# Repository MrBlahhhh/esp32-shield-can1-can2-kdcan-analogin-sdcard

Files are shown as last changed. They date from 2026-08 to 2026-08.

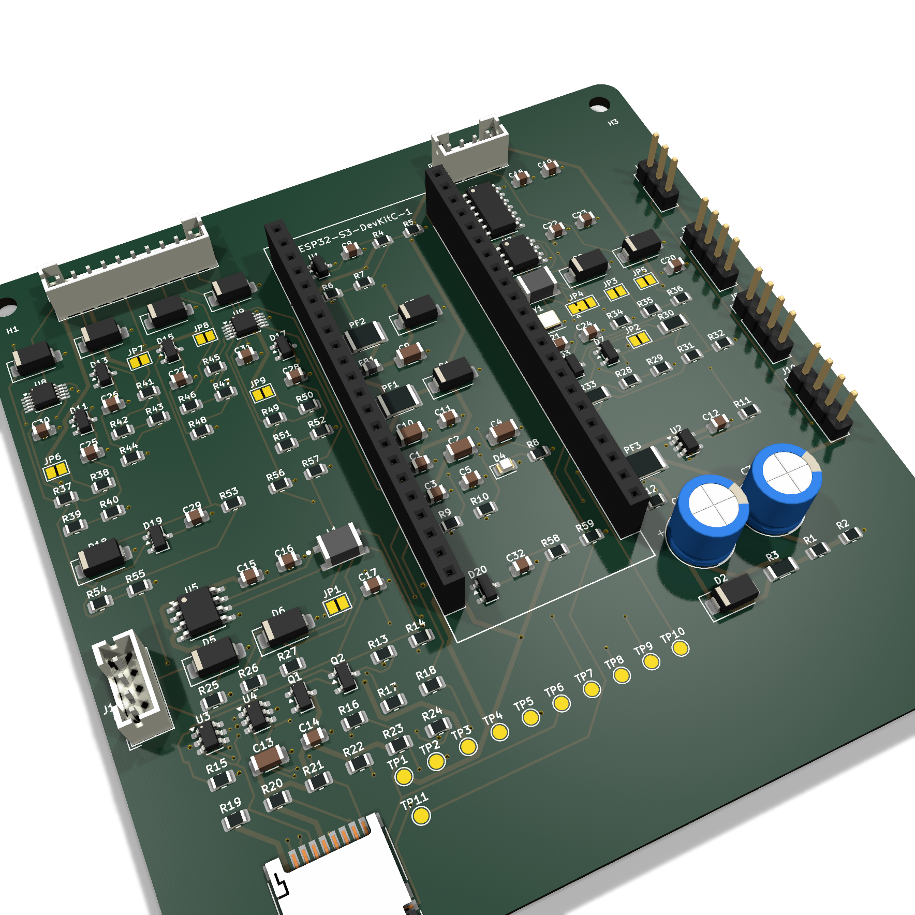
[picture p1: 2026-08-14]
plots/board-iso.png

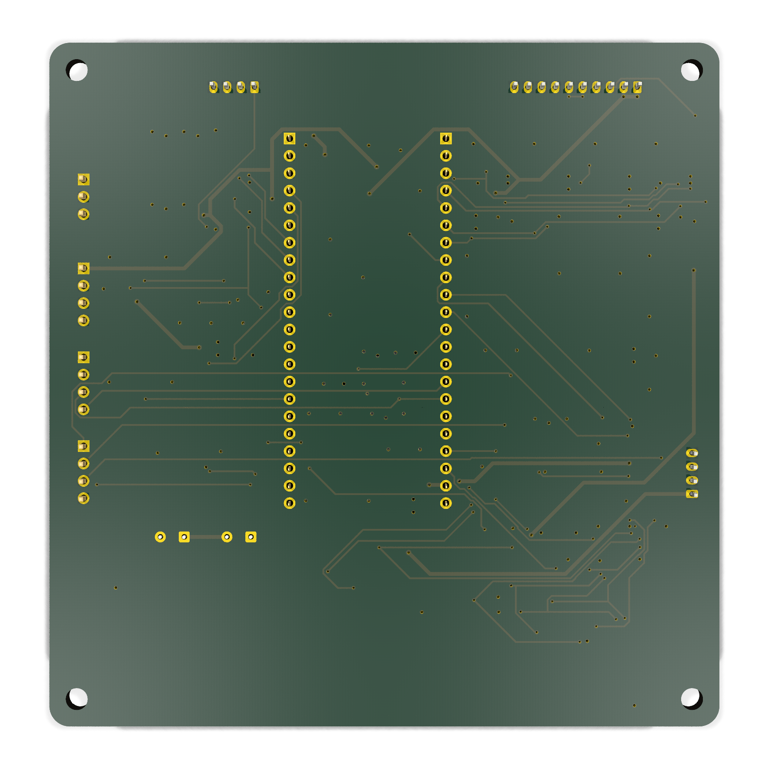
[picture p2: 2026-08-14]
plots/board-back.png

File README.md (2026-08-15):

# ESP32-S3 automotive I/O carrier — two CAN buses, K-line, microSD, analog

## TL;DR

A carrier board an **ESP32-S3-DevKitC-1 plugs into**, turning it into a
vehicle data logger. The dev board brings the MCU and its power; this board
brings everything that has to touch a car.

- **Two CAN buses at once.** One on the ESP32's own TWAI controller, one on
  an MCP2518FD over SPI — because the S3 has exactly one TWAI and two
  transceivers on it would only ever give you a choice, not both.
- **K-line (ISO 9141 / KWP2000) as well**, so a BMW/MINI K+DCAN cable is
  covered end to end. A solder jumper picks whether the aux harness pins
  carry K-line or the second CAN pair; the two cannot share a wire.
- **Four analog channels, read differentially.** The sensor loom's own
  ground comes back as a Kelvin wire through an attenuator matched to the
  signal channels', so chassis offset subtracts out exactly instead of
  landing on every reading.
- **The card survives ignition-off.** A supercapacitor bank holds the 5 V
  rail for about 825 ms after the supply goes away — six times what the board
  this forked from shipped with, and long enough to finish the block in
  flight and close the file.
- **The Python in `gen/` is the source.** It generates, places, routes,
  audits and circuit-simulates the whole board; the KiCad files are build
  outputs. `python gen/build_board.py` rebuilds the PCB from nothing.
- **The firmware runs before the board exists.** `gen/simulate_firmware.py`
  compiles the real sketch for the PC against a model of this board and
  feeds it CAN frames, sensor voltages and a power cut.
- **State: routed clean, simulated, firmware ported, never manufactured.**

## Why a carrier and not a shield

It was going to be a shield. It measured out at 1.4× the dev board's entire
area before a single track was drawn, so it isn't one — the DevKitC-1 drops
into two 22-way sockets on a board considerably larger than itself.

Worth being plain: at **98 × 100 mm** this is no smaller than the standalone
board it forked from. What it buys is a replaceable MCU with no module to
reflow, and a second CAN bus and a K-line the parent never had.

| | |
|---|---|
| Board | 98 × 100 mm, 4 layer |
| Parts | 153 component instances, 70 distinct BOM lines |
| Nets | 90 |
| Assembly | 128 surface-mount designators across 48 fab BOM lines |

## What's on it

| Block | Detail |
|---|---|
| **CAN 1** | TJA1051T/3 on the ESP32's TWAI. Common-mode choke, split termination (off by default), bidirectional clamps. |
| **CAN 2** | MCP2518FD (SOIC-14) on SPI with a 40 MHz crystal, its own TJA1051, choke, termination and clamps. |
| **K-line** | Discrete: 2N7002 low-side driver, clamped 22k/10k receiver, optional ISO 9141 tester pull-up on a jumper. |
| **Analog** | 4 channels, fixed 0–16 V divider (0.1 % where it sets the gain, 0.235 % worst case, no calibration needed), pull-up jumper per channel, two ADS1115s, shared Kelvin ground return. |
| **microSD** | 1-bit SDMMC, switched card supply, ESD arrays on every contact. |
| **Hold-up** | 2 × 0.33 F 2.7 V supercaps in series on the 5 V rail, TLV431 power-fail detector tripping at 4.20 V. |
| **Shift light** | 74AHCT1G125 buffer so WS2812 DIN is a real 5 V, fused tap, 3-pin header. |

There is **no power conversion**. Both rails come up from the dev board's
sockets — 5 V from its USB-C behind its own Schottky, 3.3 V from its LDO.
The only 12 V the board sees is OBD-II pin 16, and that is sense-only.

## Pin map

All 24 usable DevKitC-1 GPIOs are allocated; nothing is spare. Pins are
grouped by which socket row they are on, because each row is 22 through-holes
that cut a 53 mm slot through every inner layer — a signal crossing one has
no return path underneath it.

| J1 row (left of the board) | | J3 row (right) | |
|---|---|---|---|
| IO4–IO7 | AIN1–4 | IO1, IO2 | K-line RX / TX |
| IO8 | battery sense | IO39–IO42 | CAN 2 SPI (SCK/MOSI/MISO/CS) |
| IO9, IO10 | I²C SCL / SDA | IO21 | CAN 2 interrupt |
| IO11 | SD card detect | IO47 | SD supply enable |
| IO12–IO14 | SD D0 / CMD / CLK | IO48 | WS2812 data |
| IO15 | power fail | | |
| IO16–IO18 | CAN 1 S / TX / RX | | |

Exactly one net crosses sides — `SD_PWR_EN`, a load-switch gate — and it
routes around the end of the row rather than through it.

The analog channels must live in IO1–IO10 because ADC2 is unusable with the
radio up. After the SD bus takes IO9–IO14 and IO3 is excluded as a strapping
pin, IO4–IO8 are exactly the five that remain.

## Ordering

```
python gen/export_fab.py      # gerbers, positions, JLC BOM
python gen/export_order.py    # LCSC shopping list + what to buy elsewhere
```

Every one of the 48 fab BOM lines carries an LCSC part number, and each was
checked against the live catalogue rather than assumed — see
[`docs/PARTS.md`](docs/PARTS.md) for what that turned up, including three
part numbers that were confidently wrong and two footprints that would not
have soldered. [`docs/COST.md`](docs/COST.md) prices the result and identifies
about $5.70 a board of savings that cost nothing functional.

`fab/order-elsewhere.csv` lists what LCSC's assembly flow cannot supply:
the through-hole connectors, the two supercapacitors and the dev board.

**The order is ready and paused.** Everything is verified — gerbers, BOM,
placements, both JLCPCB quotes and an LCSC cart — and it is on hold because
US customs adds 35% of merchandise value. See
[`docs/TODO.md`](docs/TODO.md) for the state of play and the resume
checklist, and [`docs/COST.md`](docs/COST.md) for the quotes and the
hand-build-versus-assembled comparison.

## Verification

| | |
|---|---|
| `gen/validate.py` | schematic re-extracted through KiCad and compared net for net; ERC clean |
| `gen/build_board.py` | places, routes, and runs DRC — **0 violations, 0 unconnected** |
| `gen/simulate_firmware.py` | **50 checks**, the real sketch compiled for the host against a model of this board |
| `gen/mutate_firmware.py` | deliberately breaks the firmware 17 ways to prove the suite notices — **17 of 17 caught** |
| `gen/simulate.py` | ngspice: analog channel, crank, CAN bus, system budgets, log fidelity |
| `gen/audit_*.py` | docs, polarity, straps, paste, mechanical, PCB, routes, schematic readability |

Study 0 of the firmware suite is the one everything else rests on: it dumps
the simulator's pin map and compares it to `netlist.txt`, so a model built
from prose instead of the design fails loudly rather than validating the
wrong board.

## Wanted, not yet built

[`docs/TODO.md`](docs/TODO.md) — additions nobody has started, as opposed to
the defects below, plus the state of the paused parts order. Currently two
sensor additions, and **neither needs a board change**:

- **Exhaust gas temperature** through an MCP9600 on the I2C header. Entirely
  firmware.
- **Wideband AFR** from a DIY-EFI TinyWB. Its 0–5 V output drops straight
  into a sensor channel with nothing to change at all — that is the input
  the analogue front end was designed around. The open question is its
  10–20 AFR scaling, which clips anything richer than 10.0.

## Known open

- ~~**`ROW_PITCH` is an assumption.**~~ **Settled — 22.86 mm is correct**, from
  Espressif's own DXF. The pad columns sit at x = 1.270 and x = 24.130, 22
  pads each over y 7.960–61.300 (53.34 mm = 21 × 2.54), so the spacing is
  24.130 − 1.270 = **22.860 mm exactly**. It closes against the board width
  too: 1.270 + 22.860 + 1.270 = 25.400.

  Worth knowing that a figure of "25.4 mm row spacing on a 27.9 mm board"
  circulates for this part. That is the **original ESP32-DevKitC** with the
  WROOM-32 module, which really is wider. On the S3, 25.40 mm is the board
  width — the tell is that a 25.5 mm body with 25.4 mm rows would put the pin
  centres 0.05 mm from the edge.
- **No antenna keepout.** The module is on the dev board now, radiating from
  about 8.5 mm above this laminate. Copper underneath still detunes it, but
  which end of the outline to clear needs measuring off the same DXF.
- **The hold-up timings are calculated, not measured.** 825 ms shed /
  254 ms unshed come from `t = C·dV/I`; the ngspice study for the supercap
  bank has not been written, and ESR and the Schottky's drop over
  temperature will both eat into them.
- **Check the dev board revision.** v1.1 puts the onboard RGB LED on IO38,
  which this board leaves free for it. Some revisions use IO48, which is the
  WS2812 output here and would clash.
- **The schematic still has about 20 text collisions** out of the ~150 it
  started with, mostly a label brushing a neighbour inside a hand-drawn
  block. `gen/audit_schematic.py` lists each one with coordinates.
- **Two bypass capacitors sit 8.7 mm from the pin they bypass**, against the
  6 mm `gen/audit_pcb.py` asks for. That is the width of the SOIC-8 itself:
  the shelf packer keeps each bypass immediately beside its IC, but fills
  left to right, so the capacitor lands on the opposite side of the package
  from the supply pin. Down from 42 mm, and fine for 500 kbit/s CAN with
  22 µF of bulk on the same rail, but it is the one placement the audit
  still objects to.

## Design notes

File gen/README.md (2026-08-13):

# The generator pipeline

Everything in this project is generated: the Python in this directory is the
source of truth and every `.kicad_sch` / `.kicad_pcb` / `fab/` / `plots/`
file is a build artifact. Nothing is ever hand-edited in KiCad — if it were,
the next regeneration would silently discard it. This file documents how the
pipeline works and, more importantly, the rules that were learned the hard
way, so the next boards can reuse all of it. The intended flow for a new design is at the bottom of this file.

## The one-command loops

```
# schematic loop (any Python 3)
python gen/generate_schematic.py && python gen/tidy_sch_text.py \n  && python gen/validate.py && python gen/audit_schematic.py

# board loop (needs KiCad 9 installed, freerouting.jar in the repo root)
python -u gen/build_board.py --passes 60

# the checks DRC cannot make (after a build)
"C:\Program Files\KiCad\9.0\bin\python.exe" gen/audit_pcb.py
python gen/simulate.py            # needs ngspice, numpy, matplotlib

# outputs
python gen/export_plots.py        # schematic.pdf + three board renders
"...\bin\python.exe" gen/export_fab.py   # JLCPCB gerbers/BOM/CPL
```

## What each file owns

| file | owns |
|---|---|
| `generate_schematic.py` | the part and net tables (the design itself), sheet packing, symbol/wire/label emission, netclasses, title blocks |
| `sch_blocks.py` | hand-drawn schematic layouts for every recurring circuit — coordinates only, no electrical content |
| `generate_pcb.py` | board outline, placement zones, fixed placements (`FIXED`, `BUCK_FIXED`, `PIN_FIXED`), planes, keepouts |
| `build_board.py` | the 10-stage build driver, with a lock so two builds cannot fight |
| `route_bucks.py` | hand-shaped copper for switching loops. **Not run on this board** — the converters went with the power section, `BUCK_FIXED` is empty, and `build_board.py` skips the stage. Kept for the next design that has one |
| `finish_routing.py` | ties for duplicated connector pins (runs before AND after autorouting) |
| `stitch_planes.py` | a via from every GND/+3V3 pad to its plane, with hole-collision checks |
| `maze_route.py` | rip-up-and-retry router for whatever freerouting leaves open |
| `tidy_silk.py` | reference designator declutter; touches no copper |
| `tidy_sch_text.py` | the same job on the schematic: nudges colliding references and values, slides labels along their own wire, pulls a stub out where a label needs room. Touches no connectivity |
| `audit_schematic.py` | measures what tidy_sch_text.py then fixes — text collisions (including pin numbers) and symbols joined by name rather than by wire |
| `validate.py` | compares KiCad's own netlist node-for-node against `netlist.txt`, runs ERC |
| `audit_pcb.py` | current capacity, antenna keepout, decoupling distance, thermal, drill overlaps |
| `simulate.py` | twelve ngspice/numpy/scipy studies of the circuits themselves |
| `audit_routes.py` | post-route extraction: IR drop over the real copper, bus lengths/skew, SW-node area |
| `audit_straps.py` | every ESP32 strapping pin's state at reset vs what the netlist hangs on it |
| `overstress.py` | closed-form worst-case for every external input |
| `export_plots.py` | schematic.pdf + board renders (top, back, iso) into `plots/` |
| `export_fab.py` | JLCPCB gerber zip, BOM csv, CPL csv into `fab/` (KiCad python) |

## Design rules the pipeline enforces mechanically

- Parts are identified by **(sheet, value, exact pad-net signature)**
  everywhere — placement tables, schematic blocks, buck routing. References
  renumber on every run and must never be used as keys.
- Values are **display-short** ("600R", "0.2A PTC", "AO3401A"); ratings live
  in the hidden Voltage/Tolerance/Note/MPN fields. `split_value()` separates
  voltage and tolerance automatically. Because values are matching keys, a
  value rename must be applied to `generate_schematic.py`, `sch_blocks.py`,
  `generate_pcb.py` and `audit_pcb.py` in the same commit.
- Every recurring or nontrivial circuit gets a **hand-drawn block** in
  `sch_blocks.py`. The column packer is only for true one-liners (bypass
  caps, single pull-resistors that belong to no connector) — anything that
  reads as "parts floating in space" should be blocked or attached.

## How to draw a schematic block (the hard-won rules)

A block is a dict: `sheet`, `anchor` (value, netset), `parts`
[(value, netset, dx, dy, rot)], `wires` [polylines], `junctions`, `rails`
[(net, x, y, facing)], `labels` {net: (x, y, angle)}. All coordinates are
mm relative to the anchor, on the **1.27 mm grid** — 12.07 is not a grid
point, 12.70 is; off-grid ends throw ERC "off connection grid" warnings.

**Rotation → pin positions** (sheet coordinates, y grows downward):

- Two-pin R/C/L/fuse (pins 1/2 at lib (0, ±3.81)):
  rot 0 → pin 1 top, pin 2 bottom; rot 180 → flipped;
  rot 90 → pin 1 left; rot 270 → pin 1 right.
- GSD FETs / BEC BJTs (G/B lib (−5.08, 0), D/C (2.54, 5.08), S/E (2.54, −5.08)):
  rot 0 → gate left, drain top, source bottom;
  rot 90 → gate bottom, drain left-top, source right-top;
  rot 270 → gate top, source left-bottom, drain right-bottom.
  The mapping is: rot 270 ≡ (lx,ly)→(ly,lx), rot 90 ≡ (lx,ly)→(−ly,−lx).
- TL431DBZ: A left, K right, REF top (rot 0).

**Connectivity rules** (each of these broke a build before it was learned):

- A wire must **end** at every junction on it. To tap a wire mid-span,
  split it into two wires that both end at the tap point and add a junction
  there. Three or more wire-ends (or wire-ends plus a pin) at one point
  need a junction; exactly two objects sharing an endpoint connect without
  one, and adding a junction to a bare two-object meeting point *breaks*
  the netlist.
- Crossing wires without a junction are legal and do not connect — use
  crossings freely, the way any dense schematic does.
- A wire routed through a third part's **pin point** connects to it. Route
  around pins you do not mean to touch.
- Labels attach anywhere along a wire or at a pin end. One label position
  per net per block. The emitter picks local vs global form automatically
  from whether the net leaves the sheet.
- Pins on power nets (GND, +3V3, +5V, +VBAT, +5VS, VBUS) may simply be
  left unwired: the emitter hangs the right power symbol on them. Only
  signal nets need wires or labels.
- **The anchor keeps its natural rotation** — only member parts get the
  block's `rot`. If the drawing needs a part rotated, that part cannot be
  the anchor (this is why SENSW anchors on the 2N7002, not the P-FET).
- Value text is placed above/below the body; leave a grid step of air
  between parallel runs or the text lands on the neighbouring wire.

**Label and text readability** (learned by zooming into ugly sheets):

- Every private net still needs exactly **one label for its name** — delete
  them all and KiCad silently renames the net `Net-(R5-Pad2)`, which breaks
  name-based netlist comparison and the schematic/board net linkage. But
  the label does not have to sit on the circuit: put it on a **short
  vertical spur** (one wire, one junction) rising into open sheet, angle 90.
- Labels at wire ends must extend **away** from the circuit: angle 180 on a
  left-pointing stub, 0 on a right-pointing one. A label anchored at a left
  stub-end with angle 0 prints its text right across the part it feeds.
- Part pitch on a shared run: **>= 10-12 mm** between centres, more when a
  value is long. Budget a full symbol's width between one part's text and
  the next part's body.
- Every pin that gets an auto GND/power symbol needs **~10 mm of empty
  sheet** beyond it for the symbol body plus its text.
- To actually judge a sheet, render it: `kicad-cli sch export svg`, then a
  headless browser screenshot (`msedge --headless --screenshot=... file:///
  ...svg`), and zoom in. Text collisions are invisible at full-page scale
  and glaring at reading scale — review at the scale a reader uses.

**Never put a control character in any emitted string.** A literal newline
inside a symbol property is accepted by KiCad's loader and then silently
breaks connectivity for every symbol after it in the file — the netlist
drops them with no error pointing anywhere near the cause. The emitter now
flattens all whitespace in properties; keep it that way.

## Writing simulation decks (ngspice gotchas, each cost an hour)

- `tran` picks its own tmax and will step right over ns-scale pulses.
  Always pass it explicitly: `tran <step> <stop> 0 <step>`.
- An "ideal diode" as a tanh-blended behavioral source leaks backward.
  Use a hard clamp: `B1 a b I=max(V(a)-V(b),0)/R_on`.
- An RC delay hung directly on a behavioral comparator output loads it and
  shifts the threshold. Buffer first: `Bbuf buf 0 V=V(comp)`, RC off `buf`.
- LTRA transmission lines go unstable next to coupled inductors; the ideal
  `T` element (`T1 p1 n1 p2 n2 Z0=120 TD=21n`) is solid. Calibrate drivers
  to the datasheet's loaded test condition, not open-circuit levels.
- `wrdata` on an AC vector writes complex pairs. Convert first:
  `let m = mag(v(out))` and write `m`.
- Keep component values in the decks in step with the schematic tables —
  the duplication is deliberate; a disagreement is a bug report.

## Fab outputs, plots, and the ordering package

- JLCPCB BOM header is exactly `Comment,Designator,Footprint,JLCPCB Part #`.
  Basic parts auto-match from the footprint+value; extended parts need a
  real LCSC C-number in the part's `lcsc=` field — **never guess one**.
  Parts without a number get listed in the project README for hand-matching
  in the order UI. Check BOM designator count == CPL count after export.
- `kicad-cli pcb render` needs its rotate argument quoted *inside* the
  string: `["--rotate", "'-30,0,25'"]` — without the inner quotes the
  leading `-` is eaten as a flag.
- STEP model for enclosure work: `kicad-cli pcb export step --subst-models`.
- **NTFS timestamp tunneling:** a regenerated file keeps its old
  CreationTime — even through delete-then-recreate within ~15 s — and
  Explorer's default "Date" column shows CreationTime, so fresh plots look
  stale to the user. After regenerating, stamp them:
  `Get-ChildItem plots | % { $_.CreationTime = $_.LastWriteTime }`.

## Build discipline (how a night of rebuilds went wrong)

- **One build at a time, ever.** The `.build_board.lock` exists for this;
  never put `rm -f .build_board.lock` inside a launch command "to be safe" —
  that is how two autorouters ended up writing the same board file.
- Stopping a build's shell does **not** stop freerouting: the java process
  survives and keeps routing a board that no longer exists. Kill java
  explicitly (`taskkill /F /IM java.exe`) after aborting a build.
- Always launch the driver with `python -u`. Block-buffered stdout means an
  empty log for ten minutes, which is indistinguishable from a hang and has
  caused healthy builds to be killed.
- A placement zone must have **more rect area than the sum of its parts'
  courtyards** (SOT-23 ~12 mm2, 0805 ~7 mm2, plus ~30 % packing loss). The
  shelf packer does not fail when a zone is too small -- it silently spills
  parts onto whatever is below. Watch the post-placement DRC line (the
  early tie stage prints it) instead of waiting ten minutes for routing.
- freerouting runs at below-normal priority (set in build_board.py) so a
  build does not take the machine down with it.

## Verification ladder

Every change climbs the same ladder, and each rung catches a class of
mistake the rung below cannot:

1. `generate_schematic.py` — dies loudly on unmatched block parts.
2. `validate.py` — ERC plus node-for-node netlist comparison.
3. `build_board.py` — DRC to 0 violations / 0 unconnected.
4. `audit_pcb.py` — the physics DRC does not know about.
5. `simulate.py` — does the circuit *work*, across tolerance and abuse.

## Starting a new board from this pipeline

The next boards are dedicated PCBs for **existing, running ESP32 projects**,
so the requirements are not invented — they are extracted:

0. Read the running project's firmware first. The pin map (`#define`s /
   board config), the peripheral drivers it initialises (which buses, which
   sensors, which voltages), and the modules on the current dev-board build
   ARE the part tables. List every external connection the firmware
   touches, then add the infrastructure the dev board was silently
   providing: power input + protection, USB, decoupling, boot straps,
   and (for anything in a vehicle) the ride-through/PWR_FAIL contract so
   firmware can keep its existing shutdown behaviour.

1. Copy `gen/` wholesale; delete the project-specific tables in
   `generate_schematic.py` (sheets/parts) and `generate_pcb.py` (zones,
   FIXED/BUCK_FIXED/PIN_FIXED, HOLES, board size) and `sch_blocks.py`.
2. Write the part tables first; run the schematic loop until validate
   passes with everything column-packed and ugly.
3. Draw blocks for each circuit cluster; re-run the loop after each one.
4. Define zones roughly, build the board, then iterate placement from the
   courtyard-overlap warnings and the renders.
5. Keep `simulate.py`'s decks in step with the schematic tables — the
   component values are duplicated there on purpose, so a disagreement is
   a bug report.
6. Before ordering: full ladder green, `export_fab.py`, BOM==CPL count,
   `docs/BRINGUP.md`-style staged checklist written from the studies'
   expected values, and JLC's free DFM at upload as the last gate.

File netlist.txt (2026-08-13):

Net connectivity for ESP32-S3 CAN + microSD Automotive Logger rev B
(88 nets)

+3V3           #FLG3.1 C10.1 C11.1 C16.1 C18.1 C19.1 C23.1 C30.1 C31.1 C4.1 C5.1 D11.2 D13.2 D15.2 D17.2 D19.2 D20.2 D4.2 D7.2 J3.1 J3.2 J5.2 J7.2 Q1.2 R10.1 R13.1 R24.1 R6.1 R9.1 TP2.1 U3.5 U4.5 U5.5 U6.14 U7.5 U8.8 U9.1 U9.8
+5V            #FLG2.1 C12.1 C15.1 C2.1 C22.1 C3.1 D2.1 J3.21 J7.1 PF2.1 PF3.1 R3.1 R4.1 TP1.1 U2.5 U5.3 U7.3
+5VS           #FLG4.1 C9.1 D3.1 FB1.2 J9.1 J9.2 JP6.1 JP7.1 JP8.1 JP9.1 TP3.1
AGND_A         R53.2 R54.1
AGND_SENSE     #FLG7.1 C29.1 D19.3 J10.3 R54.2 R55.1 U8.7 U9.7
AIN1           C25.1 D11.3 J3.4 R39.2 R40.1 U8.4
AIN1_A         R37.2 R38.2 R39.1
AIN1_IN        D10.1 J9.3 R37.1
AIN1_PU        JP6.2 R38.1
AIN2           C26.1 D13.3 J3.5 R43.2 R44.1 U8.5
AIN2_A         R41.2 R42.2 R43.1
AIN2_IN        D12.1 J9.4 R41.1
AIN2_PU        JP7.2 R42.1
AIN3           C27.1 D15.3 J3.6 R47.2 R48.1 U8.6
AIN3_A         R45.2 R46.2 R47.1
AIN3_IN        D14.1 J9.7 R45.1
AIN3_PU        JP8.2 R46.1
AIN4           C28.1 D17.3 J3.7 R51.2 R52.1 U9.4
AIN4_A         R49.2 R50.2 R51.1
AIN4_IN        D16.1 J9.8 R49.1
AIN4_PU        JP9.2 R50.1
AIN_SP1        J10.1 R56.1 U9.5
AIN_SP2        J10.2 R57.1 U9.6
AUX_A          D8.1 J2.1 JP4.2 TP11.1
AUX_B          D9.1 J2.2 JP5.1
CAN2H_T        L2.1 U7.7
CAN2L_T        L2.3 U7.6
CAN2_CS        J4.6 U6.13
CAN2_H_C       JP3.1 JP4.3 L2.2
CAN2_INT       J4.18 U6.4
CAN2_L_C       JP5.2 L2.4 R36.2
CAN2_MISO      J4.7 U6.12
CAN2_MOSI      J4.8 U6.11
CAN2_RXD       U6.2 U7.4
CAN2_S         R34.1 U7.8
CAN2_SCK       J4.9 U6.10
CAN2_SPLIT     C24.1 R35.2 R36.1
CAN2_TXD       U6.1 U7.1
CANH_T         L1.1 U5.7
CANL_T         L1.3 U5.6
CAN_H          D5.1 J1.3 JP1.1 L1.2 TP8.1
CAN_L          D6.1 J1.4 L1.4 R27.2 TP9.1
CAN_RX         J3.11 U5.4
CAN_S          J3.9 R25.1 U5.8
CAN_SPLIT      C17.1 R26.2 R27.1
CAN_TX         J3.10 U5.1
GND            #FLG1.1 C1.2 C10.2 C11.2 C12.2 C13.2 C14.2 C15.2 C16.2 C17.2 C18.2 C19.2 C2.2 C20.2 C21.2 C22.2 C23.2 C24.2 C25.2 C26.2 C27.2 C28.2 C29.2 C3.2 C30.2 C31.2 C32.2 C4.2 C5.2 C7.2 C8.2 C9.2 D1.2 D10.2 D11.1 D12.2 D13.1 D14.2 D15.1 D16.2 D17.1 D18.2 D19.1 D20.1 D3.2 D5.2 D6.2 D7.1 D8.2 D9.2 J1.2 J10.4 J2.3 J2.4 J3.22 J4.1 J4.21 J4.22 J5.1 J6.3 J7.3 J7.4 J8.10 J8.6 J9.10 J9.9 Q2.2 Q3.2 R15.2 R2.2 R25.2 R29.2 R32.2 R34.2 R40.2 R44.2 R48.2 R5.2 R52.2 R55.2 R56.2 R57.2 R59.2 R8.2 TP5.1 U1.3 U2.1 U2.3 U3.2 U4.2 U5.2 U6.7 U7.2 U8.1 U8.3 U9.3 Y1.2 Y1.4
I2C_SCL        J3.15 J5.4 R10.2 U8.10 U9.10
I2C_SDA        J3.16 J5.3 R9.2 U8.9 U9.9
K_LINE         JP4.1 R30.2 R31.1 R33.2 TP10.1
K_PU           JP2.2 R33.1
K_RX           D7.3 J4.4 R31.2 R32.1
K_TX           J4.5 R28.1
K_TX_D         Q3.3 R30.1
K_TX_G         Q3.1 R28.2 R29.1
LED_5V         J6.1 PF3.2
LED_DIN        R12.1 U2.4
LED_DIN_A      R11.2 U2.2
LED_DIN_J      J6.2 R12.2
LED_DIN_MCU    J4.16 R11.1
OBD_VBAT       #FLG5.1 J1.1 PF1.1 R58.1 TP4.1
OBD_VBAT_F     C1.1 D1.1 JP2.1 PF1.2
PFD_SENSE      C8.1 R4.2 R5.1 R7.2 U1.2
PWR_FAIL       J3.8 R6.2 R7.1 U1.1
PWR_LED_K      D4.1 R8.1
SCAP_MID       C6.2 C7.1 R1.2 R2.1
SCAP_TOP       C6.1 D2.2 R1.1 R3.2
SD_CD          J3.17 J8.9 R24.2 U4.4
SD_CLK         J3.20 R16.1
SD_CLK_C       J8.5 R16.2 TP6.1 U3.1
SD_CMD         J3.19 R17.1
SD_CMD_C       J8.3 R17.2 R19.2 TP7.1 U3.3
SD_D0          J3.18 R18.1
SD_D0_C        J8.7 R18.2 R20.2 U3.4
SD_D1_C        J8.8 R21.2 U3.6
SD_D2_C        J8.1 R22.2 U4.1
SD_D3_C        J8.2 R23.2 U4.3
SD_EN_G        Q2.1 R14.2 R15.1
SD_PG          Q1.1 Q2.3 R13.2
SD_PWR_EN      J4.17 R14.1
SD_VDD         #FLG6.1 C13.1 C14.1 J8.4 Q1.3 R19.1 R20.1 R21.1 R22.1 R23.1
SENS_RTN       D18.1 J9.5 J9.6 R53.1
TERM2_A        JP3.2 R35.1
TERM_A         JP1.2 R26.1
VBAT_SNS       C32.1 D20.3 J3.12 R58.2 R59.1
VSENS_F        FB1.1 PF2.2
XTAL1          C20.1 U6.6 Y1.1
XTAL2          C21.1 U6.5 Y1.3

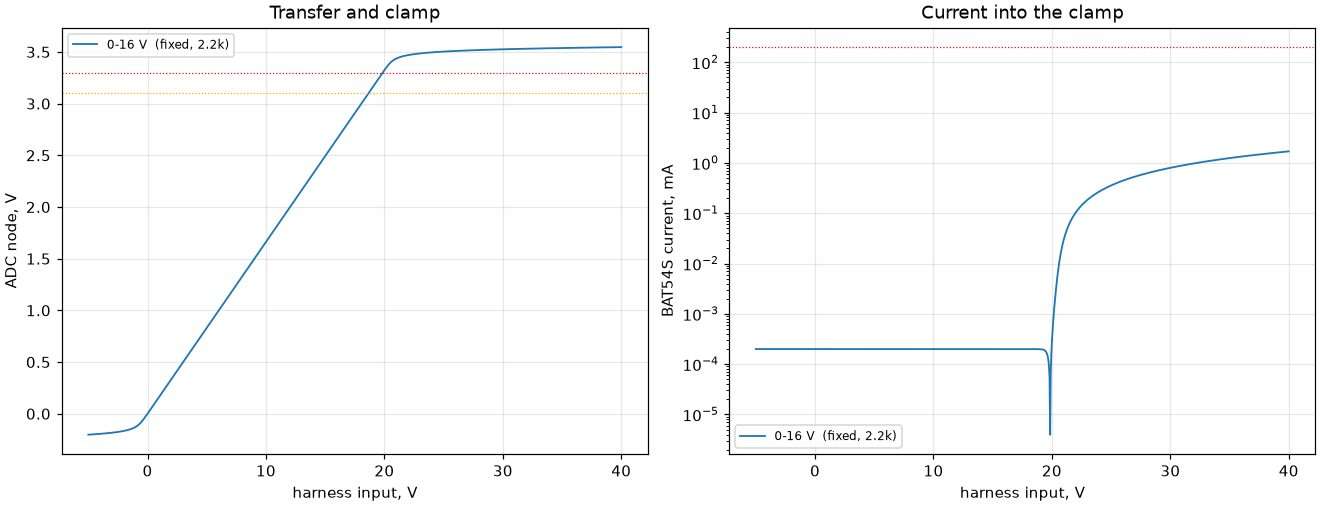
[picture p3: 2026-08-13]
sim/analog.png

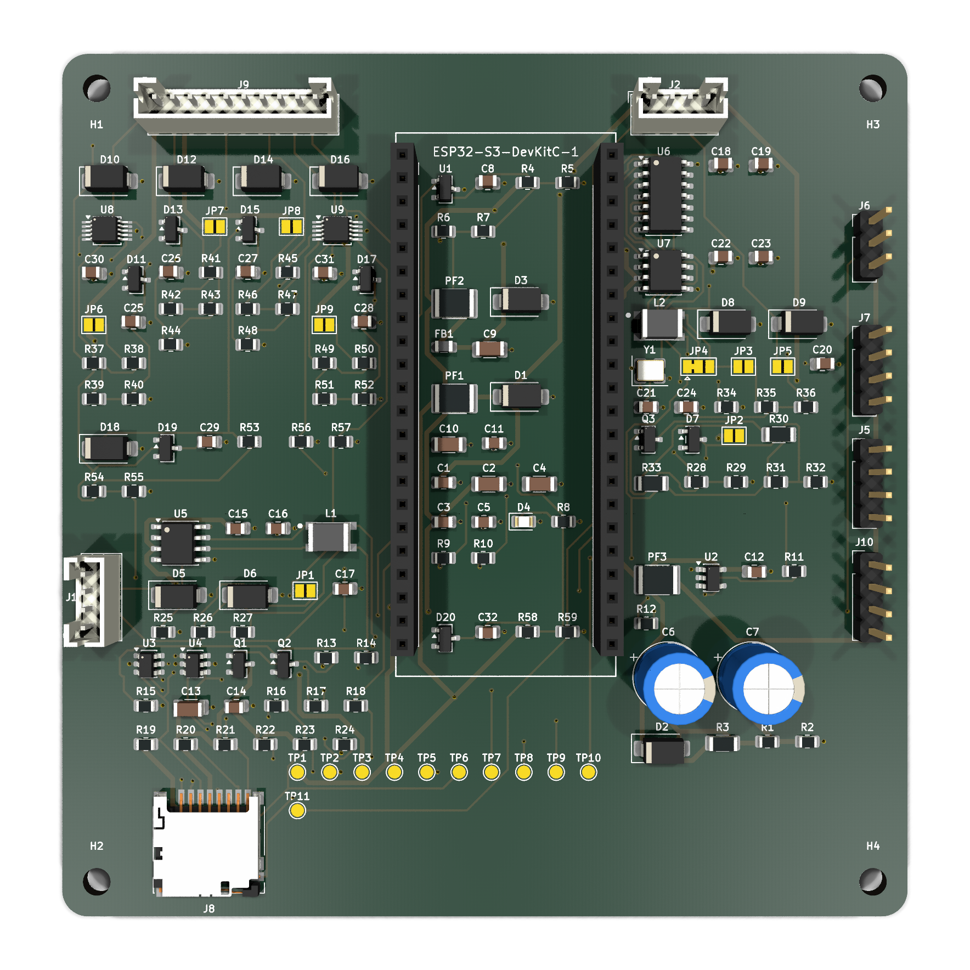
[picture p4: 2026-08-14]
plots/board-routed.png

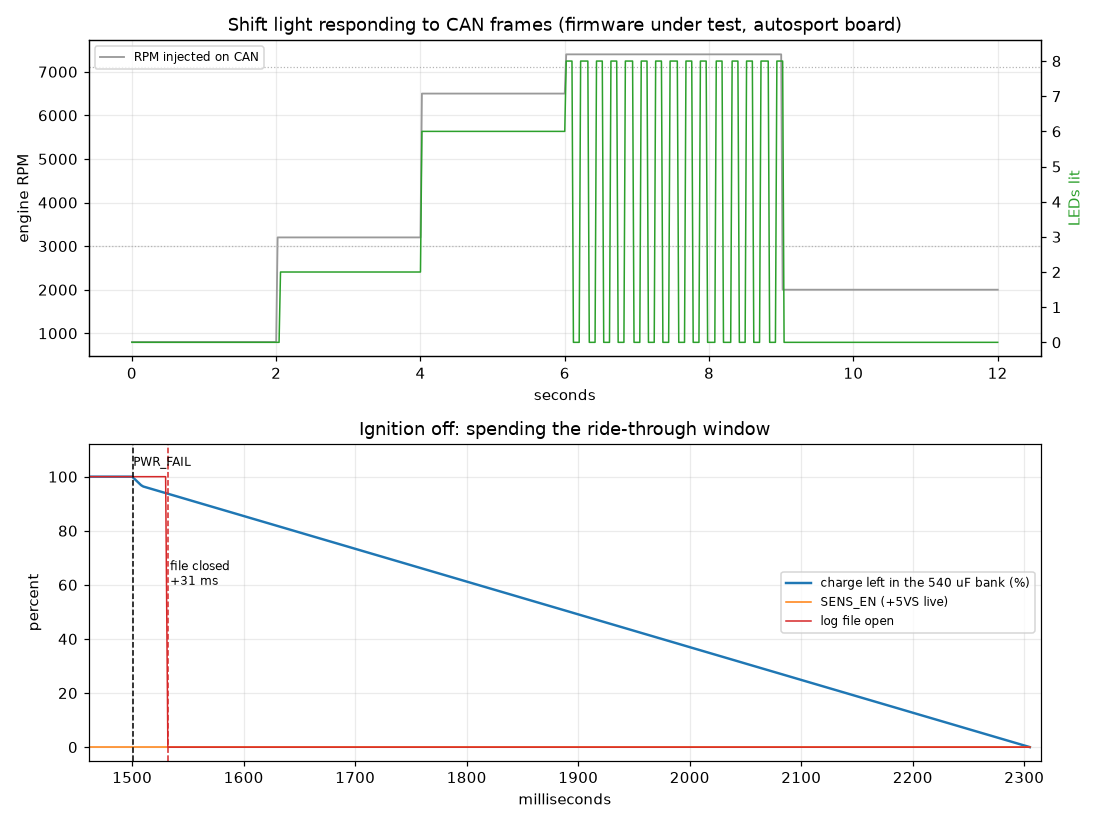
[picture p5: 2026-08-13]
sim/firmware.png

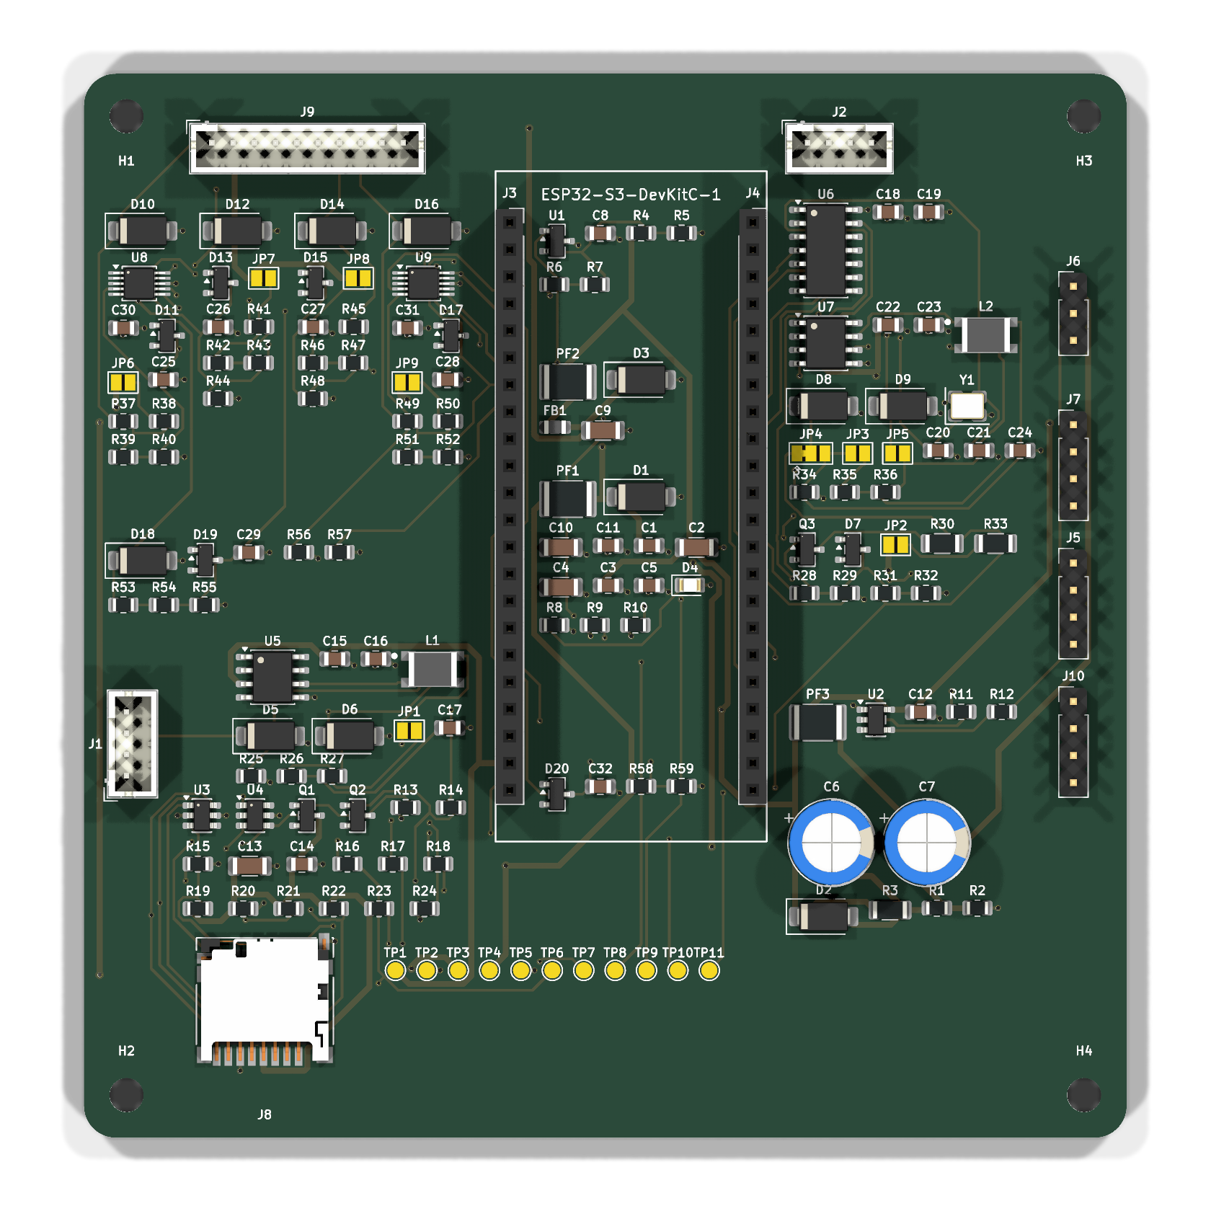
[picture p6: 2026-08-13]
sim/carrier-top.png

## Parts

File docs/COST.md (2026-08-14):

## What to upload, per vendor

The generated files differ by who is building it, and the difference that
bites is the part number. **JLCPCB matches on LCSC codes; everyone else
matches on manufacturer part numbers.** Uploading `fab/bom.csv` to PCBWay or
MacroFab returns every line unmatched, because `C37593` means nothing
outside LCSC.

| | JLCPCB | PCBWay / MacroFab / Eurocircuits |
|---|---|---|
| Board | `fab/*-gerbers.zip` | same |
| BOM | `fab/bom.csv` (LCSC codes) | `fab/assembly-bom-*.xlsx` (**MPNs**) |
| Placement | `fab/positions.csv` | `fab/centroid-*.csv` |

`gen/export_assembly_bom.py` writes the MPN version. Columns are Designator,
Quantity, Value, Package, Manufacturer, MPN, Type, Populate — the union of
what those three ask for, including the SMD/PTH marking PCBWay wants.

PCBWay's one hard rule is that **the pick-and-place designators must match
the BOM exactly, with through-hole excluded**. Both hold here and are
checked rather than assumed: 128 designators on the logger and 51 on the
gate, identical in both files, with no through-hole in either — those live
in `fab/order-elsewhere.csv` because no SMT line fits them.

### Two centroid files, and why

`fab/positions.csv` is KiCad's own export and is what JLCPCB wants: X to the
right, **Y negated**, because KiCad's Y axis points down and the export flips
the sign rather than moving the origin. Every Y in it is negative -- the
logger runs -91.5 to -13.0 on a board occupying 0..100. JLCPCB's tooling
knows that convention.

Not every assembler does, and an unstated origin with negative Y is
ambiguous in exactly the way that gets a board built mirrored. So
`gen/export_centroid.py` writes `fab/centroid-{logger,gate}.csv` with the
origin at the **bottom-left corner of the board outline**, X right, Y up,
both positive. That can be checked by eye: nothing negative, nothing larger
than the board.

It also filters to the BOM rather than to the board. Taking every footprint
gave 140 rows against the logger's 128 BOM designators, because the board
also carries connectors, sockets and supercapacitors. PCBWay asks
specifically for "all the designators/references same as the ones in BOM,
with THT designators excluded", and a centroid that disagrees with the BOM is
the one thing they warn about. The script fails if the two ever diverge.

Through-hole is hand-fitted whoever builds the boards: relays, terminal
blocks, the optocoupler and the JST headers.
if a quote is easy to get.

### Europe — the most plausible alternative

- **Aisler** (Netherlands) — small-batch, hobbyist-friendly, EU-made, online
  quoting. Closest thing to an OSH Park in Europe.
- **Eurocircuits** (Belgium/Germany) — prototype and small series, and they
  do assembly. Well regarded, properly engineered, online quoting.
- **Beta Layout / PCB-Pool**, **Multi-CB** (Germany) — similar.

EU prices are higher than mainland China, but the comparison is against
JLC+35% rather than JLC, and EU→US duty is a different and generally lower
rate. Eurocircuits is the one to quote for assembly, Aisler for bare boards.

### United States — priced, not competitive

MacroFab quoted **$1200 and that excluded pick and place**, against JLCPCB's
$475.71 all in. Duty would have to reach **265%** before JLCPCB assembled
cost what MacroFab quoted; it is 35%.

Bare board only: OSH Park prices 4-layer by area at roughly $10/in², and the
logger is about 15 in², so three boards would exceed $100 against $13 for
ten. Advanced Circuits, Sunstone, Bay Area Circuits and Royal Circuits are
all real, all 5–20× for prototype quantities. Screaming Circuits, PCB:NG and
Tempo do assembly at MacroFab-like levels.

US board fab is not close, and the tariff does not make it close.
oor stays open.

Worth knowing that all 19 Yageo part numbers that script *constructs* from
Yageo's own scheme came back **Exact** matches at Octopart, which validates
the scheme end to end.
eference the ADS1115's own gain error is 0.15 % typical and 0.30 %
maximum, so the middle row puts the divider just under the converter — the
point past which spending more stops buying anything. It saves $1.47 against
all-0.1 % and needs no calibration.

#### The original argument, for the record

The biggest surprise in the whole BOM: **fifteen resistors cost $2.68**, more
than the CAN controller. Yageo's RT/AT 0.1 % series is 0.30 and 0.19 dollars a
piece against $0.0027 for a stocked 1 % part — a hundredfold difference.

They are not buying what they look like they are buying:

- **The ADS1115's own gain error is ±0.15 % typical, ±0.30 % maximum.** A
  0.1 % divider contributes about 0.14 %. The converter is already the
  dominant error term, so tightening the resistors below it changes the total
  by almost nothing.
- **Absolute accuracy has to be calibrated anyway.** One constant per channel
  against a known voltage removes the divider error whatever its tolerance —
  and the schematic has said "exact scale is a firmware calibration constant"
  since the parent board.
- **The thing that cannot be calibrated away is the differential match**, and
  1 % is fine there. The ground correction's residue is the *mismatch* between
  the signal chain and the return chain: at 1 % that is about 2 % of the
  offset, so a 300 mV chassis offset leaves **6 mV** instead of 0.6 mV. Both
  are negligible against the 300 mV being removed.

Honest version of the trade: uncalibrated, 0.1 % gives ~0.33 % total error and
1 % gives ~1.4 %. Calibrated, they are indistinguishable. **If you will
calibrate once per channel, this is free money.** If you will not, keep the
0.1 % parts on the four signal channels and the shared return — that is ten
resistors, not fifteen, and saves $0.27 instead of $2.63.

### 2. Shrink the supercapacitor bank — saves roughly $2

1 F per cell buys 2500 ms of hold-up. Nothing needs that:

| cells | bank | shed | everything on |
|---|---|---:|---:|
| 0.10 F | 0.05 F | 250 ms | 77 ms |
| **0.33 F** | 0.165 F | **825 ms** | 254 ms |
| 0.47 F | 0.235 F | 1175 ms | 362 ms |
| 1.00 F (now) | 0.5 F | 2500 ms | 769 ms |

The parent board rode out **127 ms** and that was judged adequate. A healthy
card flushes in 18 ms; the worst stall the studies model is 500 ms, and
`shutdown()` clears the strip within 9 ms so the shed column is the one that
applies. **0.33 F is 6× the parent's proven margin** and still clears the
worst modelled stall with 65 % to spare.

Correction to `docs/PARTS.md` while I am here: I wrote that cylindrical cells
are "tens of milliohms". The Eaton HV0810 class is **200 mΩ**. Two in series
is 400 mΩ, which drops 48 mV at 120 mA — fine, and still inside the "under
about 1 Ω" requirement, but the note overstated the case.

### 3. Replace the Hirose microSD socket — NOT DONE, see below

$1.12 against $0.04–0.06 for a generic push-push TF socket. That is 9 % of the
SMD BOM in one connector.

The catch is real: **the cheap sockets have no card-detect switch.** That
costs the `SD_CD` signal, and firmware finds out there is no card by failing
to mount — which for a logger that checks at boot is not much of a loss. It
also *frees a GPIO*, and this board currently has none spare.

It needs a footprint change and push-push instead of push-pull (spring eject
rather than friction). Arguably better in a car.

### 4. Consider one ADS1115 instead of two — saves $1.32

The second one exists solely to give channel 4 a differential pair: one chip's
MUX offers three channels against a shared negative, not four.

With one chip you keep three fully differential channels and read the fourth
single-ended on the ESP32's own ADC — still four inputs, but the fourth
without ground correction and at ±1–2 %. Worth it only if three precision
channels is genuinely enough.

## Not recommended

**MCP2518FD → MCP2515 (saves $1.82).** Tempting: $0.94 against $2.76, and the
car runs classic CAN at 500 kbit/s so CAN FD is unused. But the MCP2515 has
**two receive buffers** where the MCP2518FD has 2 KB of message RAM and 32.
On a busy bus with SPI latency in the way, two buffers overrun and you lose
frames — and this is a logger, where a dropped frame is the failure mode that
matters. Keep the 2518.

**TJA1051 → SN65HVD230 (saves ~$0.30).** The HVD230 is 3.3 V only. This board
wants 5 V bus drive with a 3.3 V logic pin, which is exactly what the
TJA1051T/3 does. Not the same part.

**2-layer PCB.** The two socket rows already slot the planes; taking the
planes away entirely on a board carrying CAN, a 20 MHz SPI bus and four analog
channels is a false economy.

## Summary

| Change | saves | status |
|---|---:|---|
| 0.1 % only where it matters | **$1.47** | **done** |
| 1 F → 0.33 F supercaps | ~$1.80 estimated | **done** |
| Generic microSD socket | — | **dropped**, see below |
| **Achieved** | **$3.27** | **$18.29 → $15.02, an 18 % cut** |
| One ADS1115 | $1.32 | available, costs channel 4's ground correction |

The resistor saving is measured against the regenerated BOM. The supercapacitor saving is an estimate, because those
are bought outside the LCSC catalogue and the price depends on the cell.

## What happened to the socket

The $1.06 saving was real arithmetic against the wrong part. Those $0.04
sockets are SHOU HAN and XUNPU house parts whose only drawing is a scanned
PDF with no extractable dimensions, so **the land pattern cannot be verified**
— and this project's whole standard is that every part is checked before it is
trusted. Shipping an unverified footprint on five boards to save a dollar is
not a trade worth making.

The verifiable alternatives are much less attractive than the search results
suggested:

| Part | LCSC | qty 10 | KiCad footprint | card detect |
|---|---|---:|---|---|
| Hirose DM3D-SF (fitted) | `C719027` | $1.12 | yes | yes |
| Molex 47219-2001 | `C164170` | $0.63 | yes | no, hinged lid |
| Hirose DM3AT-SF-PEJM5 | `C114218` | $0.96 | yes | yes, push-push |

So the honest saving is **$0.49**, not $1.06, and it costs the card-detect
signal and swaps a push-pull for a hinged lid. That is 2.7 % of the board to
lose a feature. Not worth it — the Hirose stays.

Worth noting for a larger run: at volume the $0.04 parts become worth the
effort of drawing and verifying a footprint from the manufacturer's drawing.
At five boards it is not.

## A note on the PCB

98 × 100 mm sits **2 mm inside** the 100 × 100 tier boundary that most fabs
price against. Any growth past that steps into a materially more expensive
bracket, so treat 100 mm as a hard limit on both axes rather than a target to
grow into.

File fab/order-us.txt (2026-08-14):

US distributor order -- 10 x logger, 5 x gate
================================================================

Upload order-us.csv to Digi-Key's BOM manager. Quantities are
the exact build plus 2 spares -- there are no minimums here,
and some lines are lifted to the next price break only because
that costs less than buying under it.

  part number                   qty  what
  CC0805JRNPO9BN150              22  15pF 50V               
  CC0805KRX7R9BB222              12  2.2nF 50V              
  LTV-814                         7  AC-input optocoupler,  
  SMAJ5.0A                       17  SMAJ5.0A               
  SMAJ36A                         7  SMAJ36A                
  TLV431ASN1T1G                  12  TLV431ASN1T1G          
  CL31A226KAHNNNE                32  22uF 16V               
  B4B-PH-K-S(LF)(SN)             22  JST PH 4-pin vertical  
  SMAJ26CA-13-F                  52  SMAJ26CA-13-F          
  CL31A106KBHNNNE                37  10uF 16V               
  SRV05-4.TCT                    22  SRV05-4.TCT            
  CL21B474KBFNNNE                52  470nF 50V              
  RC0805FR-07100KL              107  100k                   constructed, was 0805W8F1003T5E
  B10B-PH-K-S(LF)(SN)            12  JST PH 10-pin vertical 
  MF-MSMF050-2                   17  MF-MSMF050-2           
  RC0805FR-07100RL               12  100                    constructed, was 0805W8F1000T5E
  RC0805FR-0710KL               107  10k                    constructed, was 0805W8F1002T5E
  RC0805FR-07121KL               10  121k                   constructed, was 0805W8F1213T5E
  CC0805KRX7R9BB472              22  4.7nF 50V              constructed, was 0805B472K500NT
  RC0805FR-0718KL                12  18k 1%                 constructed, was 0805W8F1802T5E
  RC0805FR-071KL                100  1k                     constructed, was 0805W8F1001T5E
  RC0805FR-071ML                 12  1M                     constructed, was 0805W8F1004T5E
  RC0805FR-072K2L                17  2.2k                   constructed, was 0805W8F2201T5E
  RC0805FR-07220RL               17  220                    constructed, was 0805W8F2200T5E
  RC0805FR-0722KL                12  22k                    constructed, was 0805W8F2202T5E
  RC0805FR-0733RL                42  33                     constructed, was 0805W8F330JT5E
  RC0805FR-074K7L                22  4.7k                   constructed, was 0805W8F4701T5E
  RC0805FR-0743KL                12  43k 1%                 constructed, was 0805W8F4302T5E
  RC0805FR-0747KL                12  47k                    constructed, was 0805W8F4702T5E
  RC0805FR-078K2L                12  8.2k                   constructed, was 0805W8F8201T5E
  RC1206FR-07100RL               12  100                    constructed, was 1206W4F1000T5E
  RC1206FR-074K7L                10  4.7k                   constructed, was 1206W4F4701T5E
  RC1206FR-0720RL                12  20                     constructed, was 1206W4F200JT5E
  RC1206FR-07750RL               12  750                    constructed, was 1206W4F7500T5E
  AO3400A                        12  AO3400A                
  SMAJ40CA                       52  SMAJ40CA               
  SMAJ6.0A                       12  SMAJ6.0A               
  SS14                           17  SS14                   
  CL21B104KCFNNNE                22  100nF 100V             
  CL21B105KBFNNNE                12  1uF 16V                
  RC0805FR-0731K6L               12  31.6k                  constructed, was FRC0805F3162TS
  RC0805FR-072K49L               42  2.49k                  constructed, was FRC0805F2491TS
  C3216X6S2A106KT0A0E             7  10uF 100V              
  ADS1115IDGSR                   22  ADS1115IDGSR           
  BAT54S                         72  BAT54S                 
  CL21B102KBCNNNC                12  1nF 50V                
  LM5164DDAR                      7  LM5164DDAR             
  CC0805KRX7R9BB104             157  100nF 16V              
  RT0805BRD0710KL               100  10k 0.1%               constructed, was FRH0805B1002TS
  TJA1051T/3,118                 22  TJA1051T/3,118         
  MCP2518FDT-H/SL                12  MCP2518FDT-H/SL        
  DM3D-SF                        12  DM3D-SF                
  MF-MSMF020/60-2                22  MF-MSMF020/60-2        
  RC0805FR-0760R4L               42  60.4                   constructed, was 0805W8F604JT5E
  DMG2301L                       12  DMG2301L               
  SN74AHCT1G125DBVR              12  SN74AHCT1G125DBVR      
  ACT45B-510-2P-TL003            22  ACT45B-510-2P-TL003    
  MPZ2012S601ATD25               12  742792022              
  1N4148W                        12  1N4148W                
  2N7002                         22  2N7002                 
  RT0805BRD072K21L               52  2.21k 0.1%             
  SS34                            7  SS34                   

  62 lines, 1716 pieces

24 of those are CONSTRUCTED Yageo equivalents
----------------------------------------------------------------
The original is a Chinese brand no US distributor carries.
Same value, tolerance and package, so the substitution is
free -- but the numbers are built from Yageo's scheme, not
read off a catalogue page. The scheme was checked against
the live site for 100R and 31K6. Spot-check a few.

CHOOSE THESE YOURSELF -- footprint-critical
----------------------------------------------------------------
Substituting the maker substitutes the pinout, and the
board is already laid out. Match the spec exactly:

  green                  x17    (was KT-0805G)
        green LED, 0805, ~525 nm

  SPDT power relay, 5 V  x12    (was SRD-05VDC-SL-C)
        SPDT power relay, 5 V coil, THT, 19.2 x 15.6 mm body, SANYOU/Songle pinout (coil 2+5, COM 1, NO 3, NC 4)

  5.00 mm screw terminal x22    (was KF301-5.0-2P)
        2-pole screw terminal, 5.00 mm pitch, THT

  5.00 mm screw terminal x12    (was KF301-5.0-3P)
        3-pole screw terminal, 5.00 mm pitch, THT

  TX322540M4FBCE2T       x12    (was TX322540M4FBCE2T)
        40 MHz crystal, 3225 4-pad, 12 pF load, -40/+85 C or wider

  XL-2012UYC             x12    (was NCD0805Y1)
        yellow LED, 0805, ~595 nm

NOT CLASSIFIED -- look these up by hand
----------------------------------------------------------------
  C168133    FNR8040S330MT            cjiang             x7    FNR8040S330MT

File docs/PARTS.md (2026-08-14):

# Part numbers, and how they were checked

Every LCSC number on this board was opened and read before it was trusted:
manufacturer part number, package, and the one or two parameters that decide
whether the part is the right one. This page records what that turned up,
because the interesting entries are the ones that were wrong.

The habit exists because this project has been bitten before. On the parent
board `C8544` was written down for an MMBT3906 and is in fact an **S9018
NPN** — the wrong polarity, in the same package, which would have left a USB
over-voltage cutoff permanently inoperative. `C7975` for an SN74AHCT1G125 is
an **LMV324 quad op-amp**. Neither is catchable by ERC, DRC, a netlist
compare or a simulation. They are only catchable by looking.

## Wrong on the first pass

| Wanted | First guess | What it actually is | Corrected to |
|---|---|---|---|
| MCP2518FD, SOIC-14 | `C2148396` | 18.7 kΩ 0805 resistor, **out of stock** | `C626759` |
| 40 MHz crystal, 3225 | `C255909` | **16 MHz** crystal | `C5186937` |
| JST PH 10-pin header | `C157966` | JST **XH 9-pin**, 2.5 mm pitch | `C158038` |

Three of the five part numbers introduced in one sitting were wrong, and all
three were plausible: right category, right-looking number, and the BOM would
have exported clean.

## Footprints that would not have soldered

Both polyfuses were specified on a **1206** land and both parts are **1812**.
Bourns' MSMF series is 4.5 × 3.2 mm; a 1206 land is 3.2 × 1.6 mm. This came
across from the parent board, where it had survived every audit — nothing in
the toolchain compares a part's package against the footprint it was assigned,
because nothing in the toolchain knows the part's package. Reading the
catalogue entry is what knows.

- `C17313` MF-MSMF050-2 — 0.5 A hold, 1812
- `C719178` MF-MSMF020/60-2 — 0.2 A hold, 60 V, 1812

## The generic-passive table is keyed on package now

`GENERIC_LCSC` in `gen/generate_schematic.py` maps a jellybean value to a
part number. It used to be keyed on value alone, which is fine until the same
value appears in two packages — and this board has 33 Ω on both an 0805 and a
1206 land, the second for the K-line driver's fault current. Keyed on value
only, the 1206 position ordered the 0805 part: right resistance, wrong
footprint, every board.

It is keyed on `(value, package)` now, and `generic_lcsc()` returns nothing
rather than guessing when a combination is missing. An unmatched line has no
part number, `export_order.py` refuses to write it, and somebody has to go
and look — which is the correct failure.

## Values chosen to match stock, not the other way round

Several values moved so that a real, stocked part exists:

| Was | Now | Why |
|---|---|---|
| 28.7k / 12.0k divider | **43k / 18k** | Same trip point to 2 mV (4.202 V vs 4.204 V); both are stocked 1 % parts and 28.7k is not |
| 33 Ω K-line series | **20 Ω** | 33 Ω does not exist in 1206 in the basic library. 20 Ω keeps the dominant level inside 0.2 × Vb with either pull-up configuration; 100 Ω would not |
| 510 Ω tester pull-up | **750 Ω** | Also absent in 1206, and 750 is the better number anyway: 190 mW while dominant against 510 Ω's 280 mW, which a 250 mW part could not carry |
| 22 Ω charge resistor | **100 Ω** | Charging 0.5 F dissipates 5.5 J whatever the resistance; 22 Ω puts 1.0 W into a 250 mW part for the first several seconds. 100 Ω peaks at 0.22 W |
| 100 nF anti-alias | **470 nF** | 100 nF against the 1.84 kΩ source gives an 865 Hz corner, above the ADS1115's 430 Hz Nyquist. Caught by `gen/simulate.py` once 0–16 V became the only range |

## Where LCSC's own data is wrong

`C719027` (Hirose DM3D-SF, the microSD socket) is listed as **"Card
Detection: No"**. It has one. DigiKey describes the same part as
"10 (8 + 2) position" with a normally-open card-detect switch, and the KiCad
footprint carries the two extra pads. The schematic wires pin 9 as
`SD_CD` and that is correct — do not "fix" it.

## The rest

Opened and confirmed, with stock at the time of checking:

| Part | LCSC | Confirmed as |
|---|---|---|
| TJA1051T/3 | `C58988` | NXP CAN transceiver, SOIC-8 |
| MCP2518FD | `C626759` | Microchip CAN FD controller, SOIC-14 |
| ADS1115IDGSR | `C37593` | TI 16-bit I²C ADC, VSSOP-10 |
| SN74AHCT1G125 | `C7484` | TI single bus buffer, SOT-23-5 |
| TLV431A | `C127592` | onsemi shunt reference, SOT-23 |
| SRV05-4 | `C13612` | Semtech 4-channel TVS array, SOT-23-6 |
| ACT45B-510 | `C76584` | TDK CAN choke, 51 µH, AEC-Q200 |
| 2N7002 | `C8545` | N-channel, 60 V — the standoff the K-line needs |
| DMG2301L | `C7472914` | P-channel, 20 V, 3 A |
| BAT54S | `C408389` | dual **series** Schottky, SOT-23 |
| SS14 | `C2480` | 40 V Schottky, SMA |
| SMAJ26CA | `C134976` | 26 V **bidirectional** TVS |
| SMAJ40CA | `C223989` | 40 V bidirectional TVS, 400 W |
| SMAJ6.0A | `C223993` | 6 V **unidirectional** TVS |
| KT-0805G | `C2297` | green LED, 0805 |
| B4B / B8B / B10B-PH | `C131334` / `C157974` / `C158038` | JST PH, 2.0 mm |
| DM3D-SF | `C719027` | Hirose microSD, push-pull |
| TX322540M4FBCE2T | `C5186937` | 40 MHz, 12 pF CL, −40/+85 °C, 30 Ω ESR |

The crystal's temperature range is the reason it is that part and not the
first 40 MHz one found: `C5380316` is also 40 MHz in the same package and is
rated **−20 to +70 °C**, which a car in a summer car park exceeds.

## The generic table was not as checked as it claimed

The header of this page says every number was opened and read. That was true
of the parts chosen deliberately. It was **not** true of `GENERIC_LCSC`, the
lookup that hands out a part number for any plain resistor or capacitor by
value and package — that table carried a comment saying it had been verified
against the live catalogue, and it had not been. Nine of its entries were
wrong, and they were wrong in the way that survives every other check:

| Wanted | Was | What it actually is | Now |
|---|---|---|---|
| 2.2 nF 50 V 0805 | `C1547` | 12 pF, and **0402** | `C107146` |
| 121 kΩ 0805 | `C25089` | 20 Ω, and 0402 | `C17438` |
| 31.6 kΩ 0805 | `C25100` | 27 Ω, and 0402 | `C2930156` |
| 4.7 kΩ 1206 | `C17909` | 120 Ω | `C17936` |
| SMAJ5.0A, SMA | `C908214` | right part, **SOD-123 body** | `C113952` |
| SMAJ36A, SMA | `C908224` | right part, SOD-123 body | `C113967` |
| green LED 0805 | `C965798` | 0603 | `C2297` |
| yellow LED 0805 | `C965800` | 0603 | `C84261` |
| 600 Ω @ 100 MHz bead | `C216149` | **60 Ω** — a factor of ten | `C81034` |

Six of the nine are package errors, and a package error is the worst kind
here: the part number is valid, the part is in stock, the value is right, and
it arrives and does not fit the land pattern. Nothing in ERC, DRC, the
netlist compare or the stock check looks at the body size of what was
ordered against the footprint it was ordered for.

`gen/verify_cart.py` now does exactly that, and it is the reason all nine
were found at once. Two ways to run it:

```
python gen/verify_cart.py --live                # before there is a cart
python gen/verify_cart.py <cart-export.csv>     # after, on what LCSC has
```

`--live` looks every number in `fab/order-combined.csv` up in the catalogue
and compares package, value, tolerance and voltage against what the
schematic asked for. Use that one — a wrong number found there is a one-line
edit, and the same number found in a cart export has already been paid for.

Two of its own bugs are worth knowing, because both reported correct parts as
wrong: `1N4148W` parsed as the value "1" against a description leading with
"150 mA", and the Würth bead's MPN `742792022` parsed as 742 megohms. Values
that are really part numbers are now skipped rather than compared.

### When to substitute for a part that is not in the index

An earlier version of this page said `C28233` was a 16 V capacitor that
`check_stock.py` had wrongly dropped into a 100 V position. **That was wrong.**
`C28233` is a 100 V 100 nF X7R 0805 and the substitution was correct. The
index holds two records for it — one keyed by part number and one by MPN —
and the by-number record comes back with an empty description, so the
Samsung code `CL21B104K`**`C`**`FNNNE` was decoded by hand and read as 16 V.
The cart export settles it: `A` is 25 V and `B` is 50 V across four other
Samsung lines on this board, and `C` is 100 V.

The real question is narrower. Absence from the index means one of two
things, because the index is JLCPCB's **assembly** library:

- `C37593`, the ADS1115, is reported absent from it and was sitting in a real
  LCSC cart at the same moment. It is not absent at all: JLCPCB quoted this
  board at 48 items, every part type including that one. The index simply
  answers inconsistently for it — present on some queries, missing on others.
  So a miss here can just be the index being unreliable.
- `C29055` and `C1794` were absent and LCSC rejected both, one "not found"
  and one "not available".

Two out of three, so absence is a real signal, and refusing to act on it is
not the safe choice it looks like — a round of this project shipped a cart
with two unbuyable lines in it for exactly that reason.

What separates the cases is not the index, it is what the schematic asked
for. A jellybean is specified by **value** — "100 nF 100 V", "15 pF 50 V" —
and anything meeting that value will do, so swapping is free. A part
specified by **manufacturer part number** — "ADS1115IDGSR", "1N4148W" — was
chosen for reasons the tool cannot see, and the nearest match by description
is a different component. So it substitutes jellybeans and never an MPN.

Any substitute it does make must state a tolerance and a voltage at or above
the design's. Silence is not evidence of a 100 V part.

### Both dead parts are fixed at source, not at order time

`C29055` and `C1794` are gone from the generators. The 100 V decoupler is
`C28233` and the crystal load caps are `C107110`, an NP0 part, which matters
for a 40 MHz crystal in a way X7R would not have been.

The 100 nF was interesting for a second reason: the logger already said
`C28233` and only the gate project said `C29055`. The combined order picks
one number when the two projects disagree, and it picked by **quantity used**
— the gate uses ten and the logger five, so the one dead number in the pair
beat the live one. It now prefers whichever number has come back in a cart
export, and falls back to quantity only between two equally unknown ones.

## A 32.768 kHz crystal as the converter's bulk input capacitor

Caught on the last check before the order went in, with a correct-looking
cart open on screen. The gate board's generic table had `C387601` for
`10uF100V` in 1206. `C387601` is an **ECS-.327-7-34B-TR, a 32.768 kHz
crystal**, and it was sitting in the cart against C2 — the LM5164's bulk
input capacitor on the 24 V rail.

`verify_cart.py` had passed it twice, for two independent reasons, and both
were bugs in the checker rather than bad luck:

- **The package matched.** `SMD3215-2P` contains "3215", which was in the
  accept list for 1206. It should never have been: 1206 is **3216** metric,
  and 3215 is a crystal package. One digit.
- **The value check silently did nothing.** It read the *leading* token of
  the description. That description begins "Crystal", which is not a number,
  so there was nothing to compare — and finding nothing to compare was
  treated as agreement rather than as the loud signal it is.

The value check now anchors on the **unit** and searches the whole line, so
it does not care whether the description leads with the value, the power
rating, the voltage or a temperature range — all four spellings occur. If
the design asks for a capacitance and the line states no capacitance
anywhere, that is now a reported disagreement. Where a record carries no
description at all, the report says so by name instead of counting it as a
pass; "checked" and "nothing to check with" are different answers.

The replacement is `C35689855`, a TDK `C3216X6S2A106KT0A0E` — 10 µF 100 V
X6S, **1206**, so the land pattern is unchanged and no board respin is
needed. It is the only 10 µF 100 V part in 1206 in the catalogue; everything
else at that value and rating is 1210. The 100 V is not over-specification:
the input TVS is an SMAJ36A clamping at 58.1 V, which a 50 V part would not
survive.

The logger's table had the same key pointing at `C6872041`, which is not in
the catalogue at all. Nothing used it, so it never surfaced — a dead number
waiting for the first part that asked for that value. Both now point at
`C35689855`.

## Minimum order quantities: the cart export is the only source

MOQs cannot be derived. Across 78 real parts they take seven distinct values
— 1, 2, 5, 10, 20, 50, 100 — and two 0805 resistors from the same
manufacturer in the same series can differ. An early version of this project
guessed them from the package and got **45 of 70 wrong**.

There is also no API for them. LCSC's own is behind Akamai, EasyEDA's mirror
answers 403 from CloudFront, JLCPCB's cart endpoint 404s, and the parts index
that does answer carries stock and price but not MOQ.

The reaction to that was to stop rounding altogether and let LCSC bump each
line at checkout. That is worse than it sounds, and it is what produced the
complaint that the minimums were "way off": **42 of 69 lines in the paste
file disagreed with what ended up in the cart.** The file said 5 and the cart
said 100, silently, forty-two times. A file that does not say what you are
buying is not much of an order.

What does carry the real numbers, exactly and for free, is a cart export:

```
python gen/learn_moq.py <cart-export.csv> [more.csv ...]
```

That folds `LCSC#`, `MOQ` and `Multiple` into `fab/lcsc-moq.csv`, which only
grows. Rounding is on by default now and `moq_round` leaves any part not in
that table exactly alone, so there is no guessing left in it — the choice is
"round the lines we have real numbers for", which has no downside. All 69
lines of the current order now conform, and the paste file matches the cart
line for line.

The ledger is also the best available evidence that a part number is real —
better than the parts index, which both misses parts LCSC sells and lists
parts it no longer does. The combined order uses it to break ties.

**So the loop is: paste, export, `learn_moq.py`, and the next order is
quantised correctly.** Each round trip through the cart permanently improves
the data, which is the closest thing to an API that exists here.

### Board counts and spares

The two projects are built in different numbers, so they are counted
separately, and hand assembly loses parts:

```
python gen/export_combined_order.py --boards 10 --other-boards 5 --spares 2
```

Spares are added **before** rounding, which is what makes them nearly free.
On a 100-piece minimum two extra cost nothing at all; they only move the
lines whose minimum is 1 or 5 — the LM5164, the MCP2518FD, the SD socket,
the relays, the terminal blocks. Those are exactly the lines where losing one
part stops a build, and where there is no bag of spares in the drawer.

At 10 loggers + 5 gates with two spares each, 33 of 69 lines do not move at
all: their minimum already covered the extra.

## Before you order

1. Re-check stock. These were read on 2026-08-12 and stock moves.
   `python gen/check_stock.py`, then `python gen/verify_cart.py --live`.
   Both should report nothing: no short lines, no unlisted lines, and every
   line matching the value, package, tolerance and voltage asked for.
2. After the cart exists, `python gen/learn_moq.py <export.csv>` and
   `python gen/verify_cart.py <export.csv>` — the first keeps the minimums
   current, the second checks what LCSC actually put in the basket.
3. ~~Confirm the DevKitC-1 header row pitch.~~ Done — 22.86 mm exactly, read
   out of Espressif's DXF. See the README's "Known open" for the numbers.
4. The two supercapacitors are the only line where the exact part matters
   beyond its value: ESR must be under about 1 Ω. A 5.5 V coin-type EDLC is
   30–200 Ω and cannot source the 120 mA the hold-up has to carry.
   Cylindrical cells clear that easily — the Eaton HV0810 class is 200 mΩ,
   so two in series drop 48 mV at 120 mA. (An earlier draft of this page said
   "tens of milliohms"; that overstated it. 200 mΩ is the number, and it is
   still comfortably inside the requirement.)
5. They are also the most expensive item on the board, and 1 F is far more
   than anything needs. See [COST.md](COST.md) — 0.33 F is still six times
   the hold-up the parent board shipped with.

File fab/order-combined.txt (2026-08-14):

Combined parts order -- 10 x logger + 5 x gate, +2 spare of each
==========================================================

Paste fab/order-combined-paste.txt into LCSC's quick-order
box, or upload order-combined.csv to their BOM tool.

Quantities are the build plus the spares, rounded up to
each part's real minimum from fab/lcsc-moq.csv. Anything
not in that table is left alone and LCSC raises it at
checkout. --no-moq turns the rounding off.

Spares are added BEFORE rounding, so on a 100-piece
minimum they cost nothing. They only change the lines
whose minimum is 1 or 5 -- which are the ones where
losing a part actually stops the build.

  part       order  needed  logger    gate  comment
  C49678       160     157     120      35 * 100nF 16V
  C149504      200     107      80      25 * 100k
  C17414       200     107     100       5 * 10k
  C17513       100      92      70      20 * 1k
  C13585        40      37      30       5 * 10uF 16V
  C12891        40      32      20      10 * 22uF 16V
  C28233        50      22      10      10 * 100nF 100V
  C2480         50      17      10       5 * SS14
  C2297         50      17      10       5 * green
  C17313        20      17      10       5 * MF-MSMF050-2
  C408389      100      72      70       0   BAT54S
  C13967        60      52      50       0   470nF 50V
  C134976       55      52      50       0   SMAJ26CA-13-F
  C223989       55      52      50       0   SMAJ40CA
  C5159707     100      52      50       0   10k 0.1%
  C865368       60      52      50       0   2.21k 0.1%
  C17634       100      42      40       0   33
  C72998       100      42      40       0   60.4
  C2930178     100      42      40       0   2.49k
  C1744         50      22      20       0   4.7nF 50V
  C107110      100      22      20       0   15pF 50V
  C76584        22      22      20       0   ACT45B-510-2P-TL003
  C719178       25      22      20       0   MF-MSMF020/60-2
  C8545         50      22      20       0   2N7002
  C17673       100      22      20       0   4.7k
  C13612        25      22      20       0   SRV05-4.TCT
  C58988        22      22      20       0   TJA1051T/3,118
  C37593        22      22      20       0   ADS1115IDGSR
  C113952       20      17       0      15   SMAJ5.0A
  C17557       100      17       0      15   220
  C17520       100      17       0      15   2.2k
  C28323        20      12      10       0   1uF 16V
  C46653        20      12      10       0   1nF 50V
  C223993       15      12      10       0   SMAJ6.0A
  C81034        20      12      10       0   742792022
  C719027       12      12      10       0   DM3D-SF
  C7472914      20      12      10       0   DMG2301L
  C17408       100      12      10       0   100
  C17713       100      12      10       0   47k
  C17901       100      12      10       0   100
  C17955        50      12      10       0   20
  C17560       100      12      10       0   22k
  C17985       100      12      10       0   750
  C17695       100      12      10       0   43k 1%
  C17506       100      12      10       0   18k 1%
  C17828       100      12      10       0   8.2k
  C17514       100      12      10       0   1M
  C127592       15      12      10       0   TLV431ASN1T1G
  C7484         15      12      10       0   SN74AHCT1G125DBVR
  C626759       12      12      10       0   MCP2518FDT-H/SL
  C5186937      20      12      10       0   TX322540M4FBCE2T
  C107146      100      12       0      10   2.2nF 50V
  C81598        50      12       0      10   1N4148W
  C84261        20      12       0      10   XL-2012UYC
  C20917        15      12       0      10   AO3400A
  C2930156     100      12       0      10   31.6k
  C35689855      7       7       0       5   10uF 100V
  C113967       20       7       0       5   SMAJ36A
  C8678         20       7       0       5   SS34
  C168133       10       7       0       5   FNR8040S330MT
  C17438       100       7       0       5   121k
  C17936        50       7       0       5   4.7k
  C477928        7       7       0       5   LM5164DDAR

  63 distinct parts, 3894 pieces
  * = on both boards (10 parts)

  Ordering the two projects separately would take 4314 pieces.
  Combining saves 420 pieces of minimum-order padding.

Through-hole, also from LCSC -- same basket
----------------------------------------------------------
  C10790    x10   AC-input optocoupler, DIP-4, LTV-814           gate U2
  C131334   x30   JST PH 4-pin vertical header, 2.00 mm          logger J1; logger J2
  C158038   x15   JST PH 10-pin vertical header, 2.00 mm         logger J9
  C35449    x12   SPDT power relay, 5 V coil, SANYOU/Songle SRD- gate K1, K2
  C474881   x25   5.00 mm screw terminal, 2 pole (MaiXu MX126 /  gate J1, J7; gate J6
  C474882   x15   5.00 mm screw terminal, 3 pole, same family    gate J5, J8

Buy elsewhere -- no LCSC part number
----------------------------------------------------------

  [logger] C6, C7       x20
        1 F 2.7 V low-ESR EDLC, 8 mm can, radial P3.5mm
        Eaton HB1030-2R5105-R or equivalent. TWO THINGS TO CHECK. (1) ESR must be under about 1 ohm: a 5.5 V coin-type EDLC is 30-200 ohm and cannot source the 120 mA this has to carry, so the rail would collapse the instant it was asked to. Cylindrical cells are tens of milliohms. (2) Anything from 0.1 F up works -- 0.1 F still gives about 500 ms of hold-up against the 2.5 s the design point buys

  [logger] J3, J4       x20
        0.1" pin SOCKET, 1x22 vertical
        RECEPTACLES, not pin headers: a DevKitC-1 ships with male pins already soldered pointing down, and it drops into these. Buy 1x22 strips -- most 1x40 socket strips do not cut cleanly and you lose a position

  [logger] J5, J7, J10  x30
        0.1" pin header, 1x04 vertical
        any

  [logger] J6           x10
        0.1" pin header, 1x03 vertical
        any

  [logger] harness      x10
        JST PH crimp housings + crimps
        PHR-4 x2 and PHR-10 x1 per board, plus SPH-002T-P0.5S crimps. Buy with the headers or the loom cannot be made up

  [logger] dev board    x10
        ESP32-S3-DevKitC-1, N8R8 or N16R8
        The MCU. Check the revision: v1.1 puts the onboard RGB LED on IO38, which this board leaves free for it. Some revisions use IO48, which is the WS2812 output here and would clash

  [gate] J2, J3       x10
        0.1" pin SOCKET strip, 1x07 vertical
        RECEPTACLES, not pin headers. The XIAO gets male pins soldered to its castellations pointing down and drops into these. Buy 1x07 strips or cut from 1x40 -- most socket strips lose a position when cut, so allow for that.

  [gate] J4           x5
        0.1" pin header, 1x04 vertical
        Any. The spare GPIO.

  [gate] H1-H4        x20
        M3 screw, nut and standoff
        4 corner holes, 3.2 mm.

  [gate] module       x5
        Seeed XIAO ESP32-S3
        The MCU. Fit the U.FL antenna that comes in the box -- a gate is the wrong place to rely on a chip antenna. It also needs male header pins soldered to its castellations, pointing DOWN, to plug into J2/J3.

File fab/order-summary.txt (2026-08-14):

Parts order for 5 boards
========================================

1. From LCSC -- paste fab/order-lcsc-paste.txt into their
   quick-order box, or upload order-lcsc-simple.csv.
   Order quantities are already rounded up to LCSC's
   minimum order quantity and order multiple.

   part          order  needed  comment            designators
   C49678           80      60  100nF 16V          C11,C12,C14,C15,C16,C18,C22,C23,C30,C31,C32,C5
   C17414          100      50  10k                R19,R20,R21,R22,R23,R25,R28,R32,R34,R6
   C149504         100      40  100k               R1,R13,R15,R2,R29,R56,R57,R58
   C408389          50      35  BAT54S             D11,D13,D15,D17,D19,D20,D7
   C17513          100      35  1k                 R14,R37,R41,R45,R49,R53,R8
   C13967           60      25  470nF 50V          C25,C26,C27,C28,C29
   C134976          30      25  SMAJ26CA-13-F      D1,D5,D6,D8,D9
   C223989          30      25  SMAJ40CA           D10,D12,D14,D16,D18
   C5159707         50      25  10k 0.1%           R39,R43,R47,R51,R54
   C865368          60      25  2.21k 0.1%         R40,R44,R48,R52,R55
   C17634          100      20  33                 R11,R16,R17,R18
   C72998          100      20  60.4               R26,R27,R35,R36
   C2930178        100      20  2.49k              R38,R42,R46,R50
   C13585           40      15  10uF 16V           C10,C13,C9
   C1744            50      10  4.7nF 50V          C17,C24
   C12891           40      10  22uF 16V           C2,C4
   C107110         100      10  15pF 50V           C20,C21
   C76584           12      10  ACT45B-510-2P-TL00 L1,L2
   C719178          15      10  MF-MSMF020/60-2    PF1,PF2
   C8545            50      10  2N7002             Q2,Q3
   C17673          100      10  4.7k               R10,R9
   C13612           15      10  SRV05-4.TCT        U3,U4
   C58988           11      10  TJA1051T/3,118     U5,U7
   C37593           11      10  ADS1115IDGSR       U8,U9
   C28233           50       5  100nF 100V         C1
   C28323           30       5  1uF 16V            C19
   C46653           40       5  1nF 50V            C8
   C2480            50       5  SS14               D2
   C223993          10       5  SMAJ6.0A           D3
   C2297            50       5  green              D4
   C81034           30       5  742792022          FB1
   C719027           6       5  DM3D-SF            J8
   C17313           10       5  MF-MSMF050-2       PF3
   C7472914         10       5  DMG2301L           Q1
   C17408          100       5  100                R12
   C17713          100       5  47k                R24
   C17901          100       5  100                R3
   C17955           50       5  20                 R30
   C17560          100       5  22k                R31
   C17985          100       5  750                R33
   C17695          100       5  43k 1%             R4
   C17506          100       5  18k 1%             R5
   C17828          100       5  8.2k               R59
   C17514          100       5  1M                 R7
   C127592          10       5  TLV431ASN1T1G      U1
   C7484            10       5  SN74AHCT1G125DBVR  U2
   C626759           6       5  MCP2518FDT-H/SL    U6
   C5186937         10       5  TX322540M4FBCE2T   Y1

   48 distinct parts, 2676 pieces after MOQ rounding
   LCSC enforces the true per-part minimum at checkout, so
   anything undercalled here is bumped there, not rejected.

2. Not available from LCSC/JLC -- source separately

   C6, C7       x10  1 F 2.7 V low-ESR EDLC, 8 mm can, radial P3.5mm
                Eaton HB1030-2R5105-R or equivalent. TWO THINGS TO CHECK. (1) ESR must be under about 1 ohm: a 5.5 V coin-type EDLC is 30-200 ohm and cannot source the 120 mA this has to carry, so the rail would collapse the instant it was asked to. Cylindrical cells are tens of milliohms. (2) Anything from 0.1 F up works -- 0.1 F still gives about 500 ms of hold-up against the 2.5 s the design point buys

   J1           x5   JST PH 4-pin vertical header, 2.00 mm
                B4B-PH-K-S(LF)(SN), LCSC C131334. The CAN1 + power harness: OBD-II pins 16, 4, 6, 14

   J2           x5   JST PH 4-pin vertical header, 2.00 mm
                B4B-PH-K-S(LF)(SN), LCSC C131334, same part as J1. The aux bus: K-line or CAN 2, whichever AUXSEL is set to

   J9           x5   JST PH 10-pin vertical header, 2.00 mm
                B10B-PH-K-S(LF)(SN), LCSC C158038. Sensor harness

   J3, J4       x10  0.1" pin SOCKET, 1x22 vertical
                RECEPTACLES, not pin headers: a DevKitC-1 ships with male pins already soldered pointing down, and it drops into these. Buy 1x22 strips -- most 1x40 socket strips do not cut cleanly and you lose a position

   J5, J7, J10  x15  0.1" pin header, 1x04 vertical
                any

   J6           x5   0.1" pin header, 1x03 vertical
                any

   harness      x5   JST PH crimp housings + crimps
                PHR-4 x2 and PHR-10 x1 per board, plus SPH-002T-P0.5S crimps. Buy with the headers or the loom cannot be made up

   dev board    x5   ESP32-S3-DevKitC-1, N8R8 or N16R8
                The MCU. Check the revision: v1.1 puts the onboard RGB LED on IO38, which this board leaves free for it. Some revisions use IO48, which is the WS2812 output here and would clash

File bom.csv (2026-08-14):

Qty (1 board) | Qty (10 boards) | References | Value | Voltage | Tolerance | Footprint | Manufacturer part number | LCSC | Notes
1 | 10 | C1 | 100nF | 100V |  | Capacitor_SMD:C_0805_2012Metric |  | C28233
2 | 20 | C17 C24 | 4.7nF | 50V |  | Capacitor_SMD:C_0805_2012Metric |  | C1744 | Split-termination common-mode stabiliser
1 | 10 | C19 | 1uF | 16V |  | Capacitor_SMD:C_0805_2012Metric |  | C28323 | MCP2518FD bulk
2 | 20 | C2 C4 | 22uF | 16V |  | Capacitor_SMD:C_1206_3216Metric |  | C12891 | Bulk at the 5 V socket pin
2 | 20 | C20 C21 | 15pF | 50V |  | Capacitor_SMD:C_0805_2012Metric |  | C107110 | Crystal load cap, sized for Y1's 12 pF CL: C1=C2=2*(CL - Cstray) = 2*(12 - 5) = 14 pF, and 15 pF is the nearest E-series value. Re-check this if the crystal is substituted -- CL varies part to part, and an oscillator that starts on the bench but not at -20 C is the classic way to get it wrong
5 | 50 | C25 C26 C27 C28 C29 | 470nF | 50V |  | Capacitor_SMD:C_0805_2012Metric |  | C13967 | Ch1 anti-alias. 470nF, not the 100nF this inherited: source impedance here is (1k+10k)||2.21k = 1.84k, so 100nF puts the corner at 865 Hz -- above the 430 Hz Nyquist of the ADS1115 at 860 SPS, and well above anything the ESP32's own SAR ADC can sample cleanly. That was survivable while 0-5 V was the default range (261 Hz) and became the only behaviour when the range jumpers went. 470nF gives 184 Hz, which still passes anything a wideband does and stops engine noise folding into the log
13 | 130 | C11 C12 C14 C15 C16 C18 C22 C23 C3 C30 C31 C32 C5 | 100nF | 16V |  | Capacitor_SMD:C_0805_2012Metric |  | C49678
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

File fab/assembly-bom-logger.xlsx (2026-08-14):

Designator | Quantity | Value | Package | Manufacturer | MPN | Type | Populate
C1 | 1 | 100nF 100V | 0805 | Samsung Electro-Mechanics | CL21B104KCFNNNE | SMD | 1
C17,C24 | 2 | 4.7nF 50V | 0805 | FH | 0805B472K500NT | SMD | 1
C19 | 1 | 1uF 16V | 0805 | Samsung Electro-Mechanics | CL21B105KBFNNNE | SMD | 1
C2,C4 | 2 | 22uF 16V | 1206 | Samsung Electro-Mechanics | CL31A226KAHNNNE | SMD | 1
C20,C21 | 2 | 15pF 50V | 0805 | YAGEO | CC0805JRNPO9BN150 | SMD | 1
C25,C26,C27,C28,C29 | 5 | 470nF 50V | 0805 | Samsung Electro-Mechanics | CL21B474KBFNNNE | SMD | 1
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

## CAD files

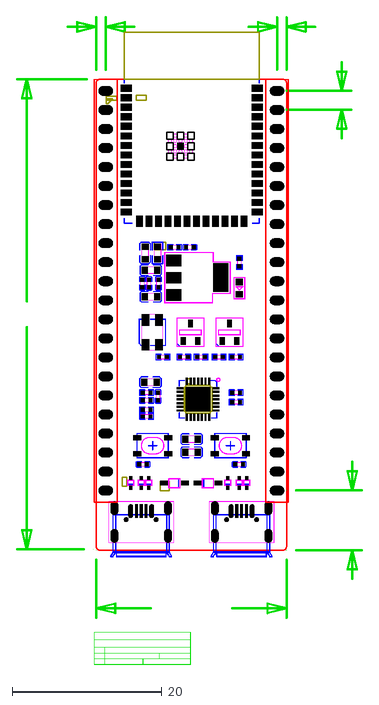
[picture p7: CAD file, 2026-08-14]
docs/DXF_ESP32S3DevKitC1_V1_20210312CB.dxf
46.2 x 86.5

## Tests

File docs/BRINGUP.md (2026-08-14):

# Assembly

**Which of these applies depends on how the boards were ordered**, and that
was still open when the order was paused — see [COST.md](COST.md). If JLCPCB
fitted the SMD, skip to step 4, the through-hole work, and then run the
polarity check in step 5, which is worth doing on an assembled board too.

The layout is spaced 1.2 mm for hand assembly either way, so nothing is lost
by building it yourself.

## By hand

Iron and a hot-air station. **Order matters** — the parts that need hot air
go on first, while the board around them is still empty and there is nothing
for the airflow to move.

1. **U8 and U9, the two ADS1115s.** TSSOP-10 at 0.50 mm pitch, the finest
   thing on the board. Paste, place, hot air. Doing these first means no
   0805 within blowing distance.
2. **U2, U3, U4** — 0.95 mm pitch. Same treatment or drag-solder with flux
   and braid, whichever you prefer.
3. Everything else with the iron, working outward. The passives sit 1.2 mm
   apart, which is what that spacing was for.
4. Through-hole last: the sockets, the microSD cage, the harness headers,
   the hold-up capacitors.
5. Check the polarised parts before power:
   `"C:\Program Files\KiCad\9.0\bin\python.exe" gen/audit_polarity.py`
   prints every orientable part with its position and what pin 1 must be.

**No stencil.** These are placed one at a time; paste goes on by syringe for
the few parts that get hot air. A stencil only pays for itself if you switch
to paste-everything-and-reflow, and that is a different workflow from the
one this layout was spaced for.

# First-power bring-up checklist

Work through this in order on the first board back from fab. Every step has
an expected value; stop at the first one that misses and debug there, because
later stages assume the earlier ones.

**Socket row pitch — settled, no longer a risk.** 22.86 mm, confirmed from
Espressif's own DXF (committed as `docs/DXF_ESP32S3DevKitC1_V1_20210312CB.dxf`):
the pad columns sit at x = 1.270 and x = 24.130, so 24.130 − 1.270 = 22.860
exactly. Sit a real module on the board before soldering the sockets anyway
— it costs nothing — but this is no longer the open question it was.

**Bench setup:** the dev board NOT yet fitted, bench supply on the aux
harness only where a stage says so, nothing on the sensor loom.

## Stage 0 — before any power

- [ ] Visual: the two 22-way sockets are **receptacles**, facing up. The
      DevKitC-1 has male pins soldered pointing down and drops into them.
- [ ] Both supercapacitor cans: **polarity**. The stripe is the negative
      terminal and pin 1 on the land is positive. These are the only
      polarised electrolytics on the board and they are in series, so a
      reversed cell is not obvious from the silk alone — check both against
      `gen/audit_polarity.py`'s fab checklist.
- [ ] `D2` (SS14) orientation. Cathode band toward `+5V`, anode toward the
      cap bank. Backwards it shorts out the 100 Ω charge resistor *and*
      blocks the discharge, so the hold-up does nothing and the USB port
      sees 4 A at plug-in. It was wired backwards once already.
- [ ] Meter, diode mode, from `+5V` and `+3V3` to GND: neither reads a dead
      short. Both should read a few hundred ohms rising as the decoupling
      charges.
- [ ] Meter across the supercap bank: open, or slowly rising. A short here
      is a reversed cell.

## Stage 1 — rails, from USB, no dev board

The board cannot power itself. Feed 5 V and 3.3 V in on the rail break-out
header (`J7`) to test without risking a dev board.

- [ ] 5 V in, current-limited to 200 mA. Inrush settles within a second or
      two, then **~30 mA** and slowly falling as the bank charges. It takes
      about 80 seconds to reach full charge through the 100 Ω — that is by
      design, see `docs/PARTS.md`.
- [ ] 3.3 V in: **< 5 mA** with nothing else attached.
- [ ] Green LED on.
- [ ] `PWR_FAIL` (test-point row) **low** with 5 V present. Wind the 5 V
      supply down: it must snap **high at 4.20 ± 0.05 V** and snap back low
      about 140 mV higher. If it sits permanently high, check `U1`'s pinout
      against the exact part bought — shunt references are not consistent
      between vendors in SOT-23.
- [ ] Kill the 5 V supply with the bank charged and watch the rail on a
      scope: it should coast for **most of a second**, not milliseconds. Collapsing
      immediately means `D2` is backwards or the cells are open.
- [ ] Nothing warm after five minutes.

## Stage 2 — the dev board

- [ ] Power off, bank discharged. Fit the DevKitC-1, **checking pin 1 at
      both ends** against the silkscreen outline.
- [ ] Power from the dev board's USB-C only. It should enumerate normally.
- [ ] Confirm both USB-C sockets are physically reachable with the loom
      plugged in — the outline reserves 12 mm at each end for the plug.
- [ ] Re-measure 5 V and 3.3 V on the break-out header: they now come *up*
      from the dev board.

## Stage 3 — buses, one at a time

- [ ] **I²C**: scan the bus. Two ADS1115s must answer, at **0x48 and 0x49**.
      Only one means the second part's ADDR pin is not on +3V3.
- [ ] **CAN 1**: with `TERM` open and a terminated bus on `J1`, check for
      frames. The transceiver is `U5`.
- [ ] **CAN 2**: `AUXSEL` bridged 2-3 and `AUXCL` closed. Frames on `J2`.
      Nothing at all means the MCP2518FD is not clocking — scope `Y1`.
- [ ] **K-line**: `AUXSEL` back to its default 1-2, `AUXCL` open. The line
      should idle at battery voltage and pull below 1.5 V when the FET is
      driven. Remember TX is inverted in hardware.

Only one CAN bus and the K-line can be usefully exercised in one loom
configuration — the aux pins are either/or by design.

## Stage 4 — card and analog

- [ ] Card detect reads a card present/absent correctly. If it never
      changes, note that LCSC lists this socket as having no detect switch;
      it does, and `docs/PARTS.md` explains why that listing is wrong.
- [ ] Write a file, pull the USB plug mid-write, re-read the card. The file
      must be closed and intact. This is the whole point of the hold-up.
- [ ] Feed a known 5.00 V into a channel: the ADS1115 should read
      **0.836 V** differentially (0–16 V divider, 2.21/13.21). The two
      gain-setting resistors are 0.1 %, so expect to be inside 0.24 % of
      that without calibrating anything. Further out than about 1 % means a
      wrong value fitted, not tolerance.
- [ ] Short `SENS_RTN` to a deliberate 200 mV offset against board ground:
      the reading must **not** move. If it does, the return attenuator does
      not match the channel — check that both legs use the same values from
      the same reel.
- [ ] Battery sense with 13.8 V on the harness: **1.045 V** at the pin,
      13.8 V after the firmware's 13.195 divisor.

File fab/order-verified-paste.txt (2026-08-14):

C49678,160
C149504,200
C17414,200
C17513,100
C13585,40
C12891,40
C28233,50
C2480,50
C2297,50
C17313,20
C408389,100
C13967,60
C134976,55
C223989,55
C5159707,100
C865368,60
C17634,100
C72998,100
C2930178,100
C1744,50
C107110,100
C76584,22
C719178,25
C8545,50
C17673,100
C13612,25
C58988,22
C37593,22
C113952,20
C17557,100
C17520,100
C28323,20
C46653,20
C223993,15
C81034,20
C719027,12
C7472914,20
C17408,100
C17713,100
C17901,100
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

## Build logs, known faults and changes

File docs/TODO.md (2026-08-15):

# Wanted, not yet built

Things this board should eventually do. Distinct from the "Known open" list
in the README, which is defects and unverified assumptions in what already
exists — everything here is an addition nobody has started.

---

## Order: ready, paused on tariffs

**Nothing is blocking this technically.** It is on hold because US customs
adds **35% of merchandise value**, which turned a $315 order into $475.71.
See [COST.md](COST.md) for the full breakdown and why it does not change the
build-versus-assemble answer, only the absolute number.

State as of 14 Aug 2026, all verified:

| | |
|---|---|
| Route chosen | **JLCPCB assembles both boards** — Economic PCBA, top side |
| Logger | 10 boards, $13.00 PCB + $226.67 assembly, 48/48 part types placed |
| Gate | 5 boards, $7.00 PCB + $68.45 assembly, 25/25 part types placed |
| JLCPCB merchandise | $315.12 |
| LCSC | `fab/order-tht-paste.csv` — 6 through-hole lines, 75 pieces, $9.64 |
| Duty + shipping | $110.30 + $50.29 on the JLCPCB side |

### To resume

1. **Re-run the checks; they are cheap and stock moves.**
   `python gen/check_stock.py`, then `python gen/verify_cart.py --live`.
   Both should report nothing.
2. **Regenerate the orders** at whatever board counts you want:
   ```
   python gen/export_combined_order.py --boards 10 --other-boards 5 --assembled
   ```
   Drop `--assembled` and add `--spares 2` if hand-building after all.
3. Re-upload the gerbers, `fab/bom.csv` and `fab/positions.csv` to JLCPCB.
   The quotes above will have moved.
4. After the LCSC cart exists, `python gen/learn_moq.py <export.csv>` to keep
   the minimums current, and `python gen/verify_cart.py <export.csv>`.

### Worth reconsidering when it restarts

- **Board counts.** 10 loggers was chosen when the marginal cost of extra
  boards looked small. With 35% on top, each extra board carries its duty
  too. Five of each is $200-ish less.
- **Two layers instead of four** for the gate controller. Noted in that
  project's `docs/ORDER.md` as an untested saving; it only matters if the
  fab bill is being squeezed.
- **Spares.** The current LCSC order has none, because assembled boards have
  no attrition to cover. If a board arrives faulty there is nothing to repair
  it with, and the SMD side means LCSC minimums all over again.

---

## Wideband AFR, via a DIY-EFI TinyWB

**Status:** analogue path needs nothing. Serial path costs a GPIO and is
probably not worth it. <https://diy-efi.co.uk/product/tinywb_module>

An LSU 4.9 controller, 17 × 21 mm, giving a **0–5 V analogue output scaled
10–20 AFR** plus a custom serial protocol.

### The analogue route works as-built

This is the sensor the analogue front end was designed around — the schematic
says so in as many words: "AFR on a 0-5 V wideband output".

| | |
|---|---|
| Signal | `AIN1_IN`–`AIN4_IN`, pins 3/4/7/8 of the 10-way sensor harness |
| Scaling | 5 V lands at 0.836 V through the fixed 0–16 V divider — 6688 counts on the ADS1115, **0.75 mV** referred to input, about **0.0003 AFR** |
| Ground | `SENS_RTN` on pins 5/6 is a Kelvin sense that subtracts out exhaust-to-chassis offset. On a sensor bolted to the manifold that is not a nicety |
| Power | `+5VS` on pins 1/2 |

**The 0.2 A PTC on `+5VS` is not a problem, despite appearances.** The LSU
4.9 heater takes amps, but it runs from **a fused 12 V supply at the sensor
connector** — the module's own 5 V is logic only. Worth writing down because
the first look at this said the rail could not do it.

### Range, not resolution, is the thing to check

0–5 V maps to **10–20 AFR**, and 10.0 AFR is λ 0.68. A turbo car at WOT
commonly sits 10.5–11.0, so the useful data is near the bottom of the range
and **anything richer than 10 AFR clips**. The resolution is absurdly good
either way; the range is the exposure.

**Ask DIY-EFI whether the analogue scaling is configurable** before doing
anything else. Many controllers rescale 0–5 V to something like 8–18 AFR,
which fixes this for free.

### The serial route, if the range turns out to be fixed

Three obstacles, worst first:

- **No spare GPIO.** All 24 usable DevKitC-1 pins are allocated. A UART means
  taking a pin off something else.
- **The one UART on a connector will not read TTL.** K-line is IO1/IO2 and
  reaches the aux harness, but its RX divider is 22 k/10 k, sized for 9–16 V
  automotive levels. 5 V TTL through it lands at **1.56 V** against a 2.48 V
  worst-case input-high threshold. Swapping to 6.8 k/10 k gives 2.98 V and
  costs you K-line.
- **The protocol is "custom"** and not publicly documented.

Cheaper pins to trade, if it comes to it: the WS2812 shift-light output on
J6 (IO48, already 5 V-capable through its buffer) or the Qwiic I²C pins on
J5. Both are on headers.

Same conclusion as [the EGT note](#exhaust-gas-temperature-via-mcp9600):
no board change either way. The decision is which GPIO you are willing to
lose, and it should not be made until the analogue range question is
answered.

## Exhaust gas temperature, via MCP9600

**Status:** scoped, not started. **Needs no board change.**

K-type EGT probes read through an MCP9600 hanging off J5, the I2C header.
Checked against the finished PCB, not the schematic:

| what | where it already is |
|---|---|
| Bus | J5 at x = 93 mm, the right board edge. The DevKitC-1 sits at x = 40 and x = 63, so it is reachable with the module in and the loom plugged |
| Pinout | 1 = GND, 2 = +3V3, 3 = SDA, 4 = SCL |
| Pull-ups | 4.7 kΩ on both lines, already fitted |
| Power | 3.3 V on pin 2. The MCP9600 wants 2.7–5.5 V and draws ~300 µA — nothing to the DevKit's LDO |
| Addresses | 0x60–0x67, against the ADS1115s at 0x48/0x49. No conflict, up to 8 channels |
| GPIO | none needed. This is the reason it is an MCP9600 and not a MAX31856 — see below |

**J5 is a 0.1″ pin header, not a JST-SH socket, despite being labelled
"I2C / Qwiic".** A Qwiic cable does not plug straight in; it needs an adapter
or flying leads. The pin order does match the Qwiic colour convention
(black/red/blue/yellow → GND/3V3/SDA/SCL) so it maps one to one.

### Getting to the engine bay

The sensors are in the bay and the logger is not, and **I²C does not leave
the board** — it is a few-inches PCB bus, single-ended, with no error
detection and no retry. A metre of SDA/SCL through ignition noise will lock
up, and because both ADS1115s share that bus, an EGT glitch takes out the
whole analog front end. A stuck SDA hangs everything until reset.

Three ways round it, in preference order:

1. **Thermocouple extension wire, MCP9600 at the logger.** The chosen
   approach. The chip stays on J5 and chromel/alumel extension cable runs to
   the bay. This also puts the cold junction somewhere thermally stable,
   which the part wants — its CJC sensor is *inside* the chip, so wherever
   the chip is, that is the reference. A cabin-mounted logger is a better
   cold junction than an engine bay one. **The cable must be chromel/alumel;
   copper before the terminals wrecks the accuracy.**
2. **MCP9600 plus a small MCU in the bay, temperatures back over CAN.** The
   automotive answer, and what commercial EGT modules do. Worth it beyond
   about two metres or four-plus channels. The aux harness can carry the
   second CAN pair, but that is a solder-jumper choice against K-line and
   the R53 wants K-line — so either give up K-line or share CAN1 with the
   OBD bus at a high ID.
3. **Differential I²C extender.** A PCA9615 at each end over twisted pair.
   Zero board change, hangs off J5 as a module, but it is still I²C
   semantics underneath.

### Before wiring anything

- **Use ungrounded (isolated-junction) probes.** EGT probes bolted into a
  manifold are usually grounded-junction — the tip is bonded to the exhaust,
  which is chassis. The MCP9600's inputs are not isolated, so a grounded
  probe gives a ground loop through the exhaust, and two probes on different
  cylinders give a loop between each other.
- Most breakouts carry their own ~10 kΩ pull-ups. In parallel with the
  board's 4.7 kΩ that is ~3.2 kΩ, about 1 mA — fine. Cut the jumpers on the
  extras if more than a couple are stacked.

### Why not the MAX31856, which is the better part

$3.39 against $9.93, TSSOP-14 against QFN-20 with an exposed pad, plus 50/60
Hz rejection and open-circuit detection. **It is SPI, and there is no chip
select to give it** — all 24 usable DevKitC-1 GPIOs are allocated. That one
fact decides the whole question.

The MCP9600's package is the hardest on the board by some margin. For one or
two channels a ready-made breakout is cheaper than a board spin and much
easier than hand-soldering a QFN-EP.

### Work remaining

All firmware.

- MCP9600 driver following the existing raw-register pattern in `main.cpp` —
  no library, same as the ADS1115 code. Hot-junction read, cold-junction
  read, thermocouple type and filter coefficient config.
- Open-circuit and out-of-range handling. A disconnected probe must log as
  absent, not as a temperature.
- EGT fields in the log format, and the matching decoder change.
- Bus-fault containment: an EGT device that stops responding must not stall
  the ADS1115 reads on the same bus.

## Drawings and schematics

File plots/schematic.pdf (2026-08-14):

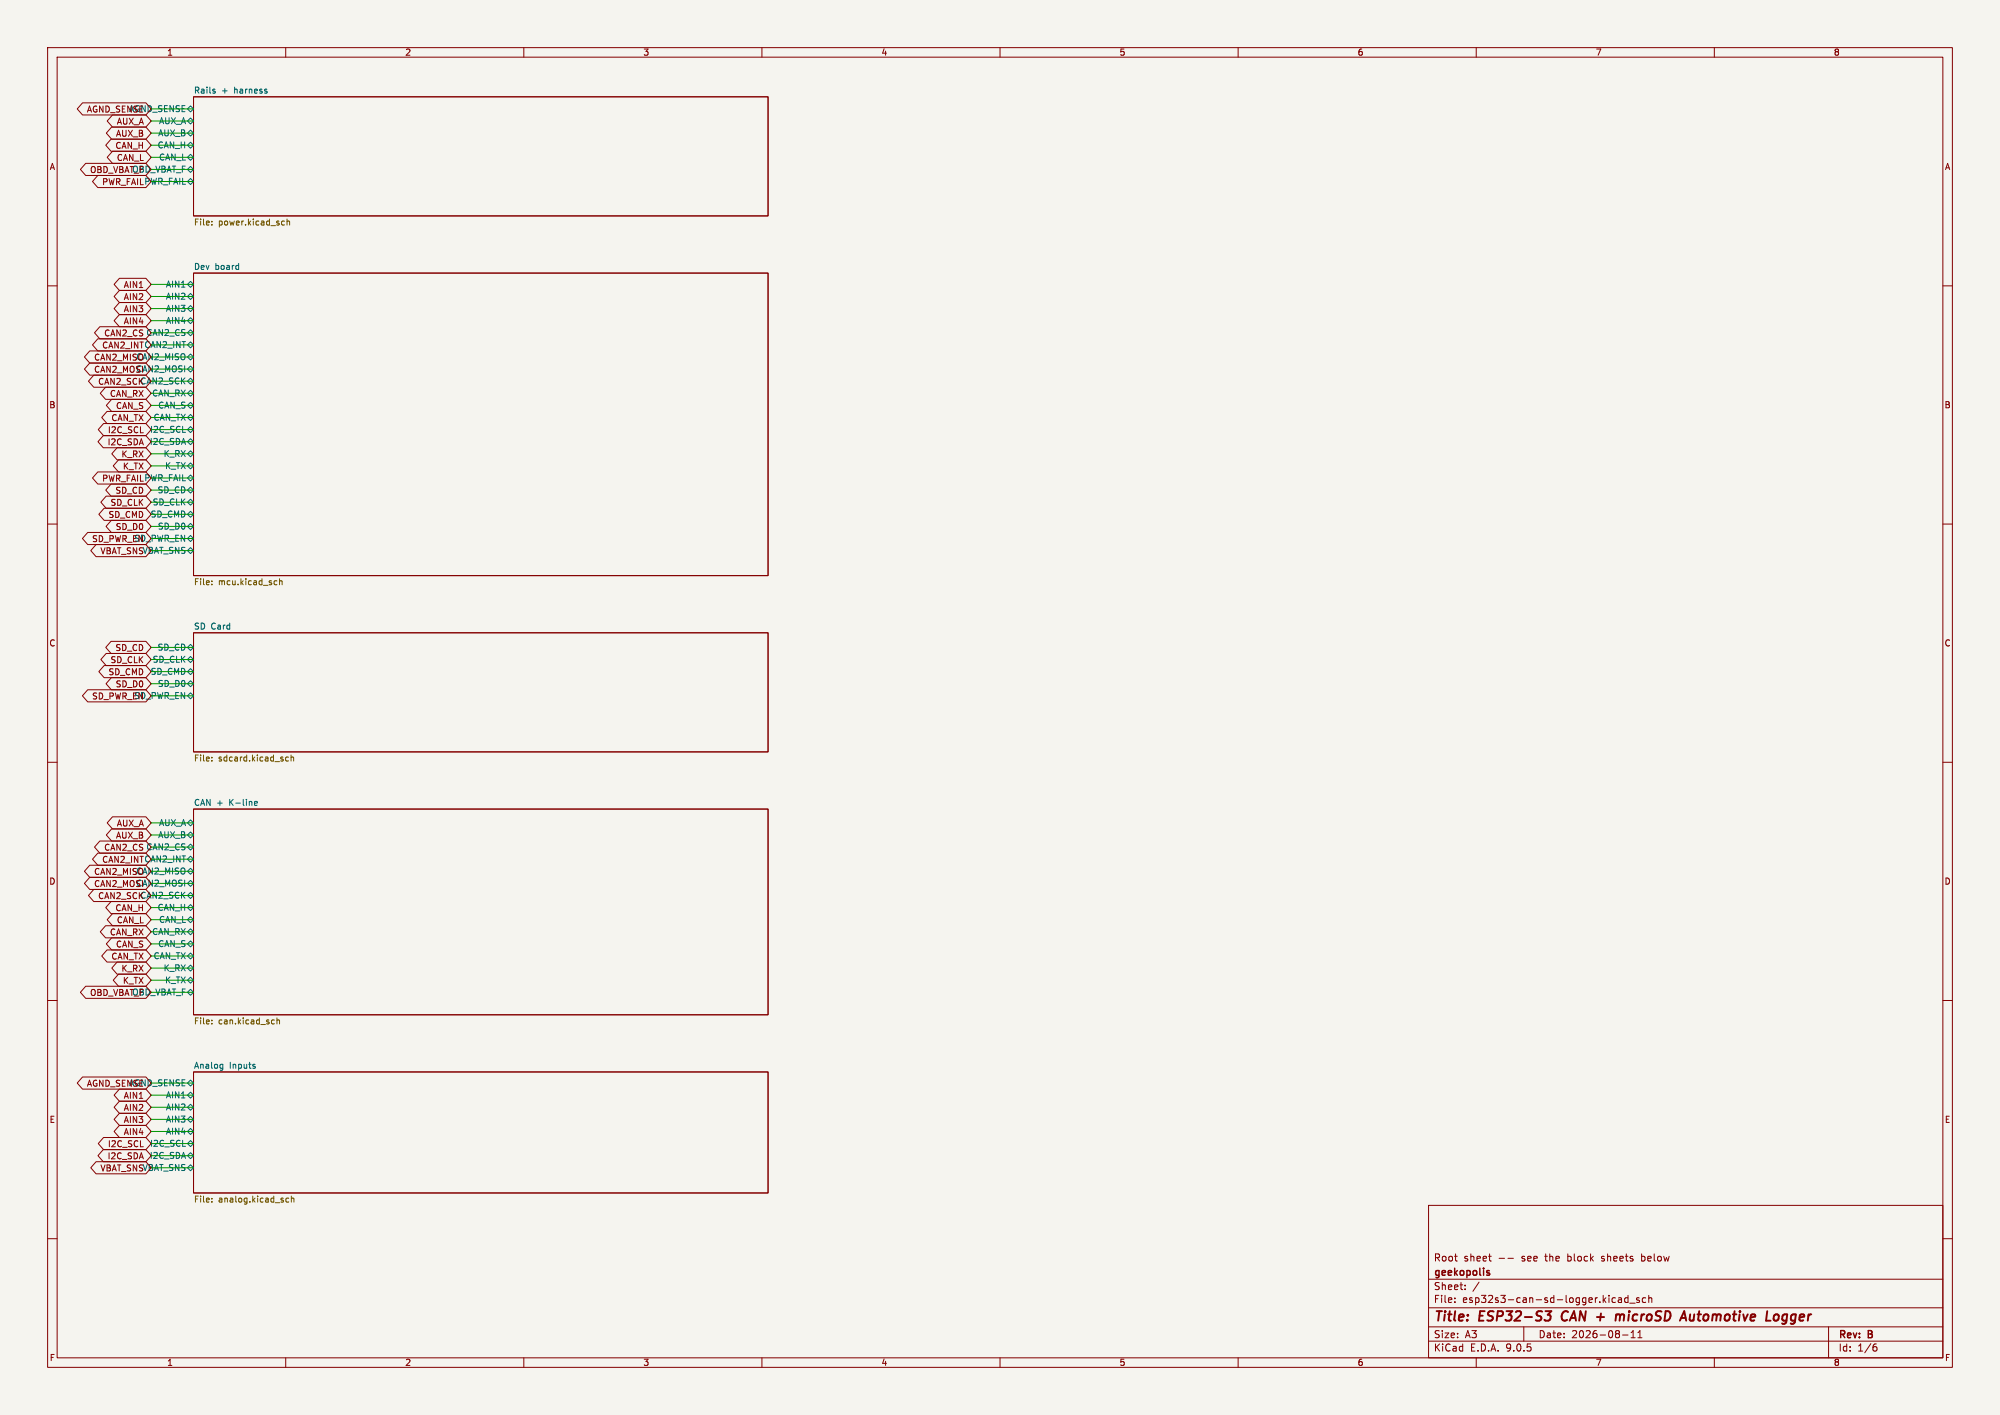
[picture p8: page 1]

VBAT_SNS
K_TX OBD_VBAT_F CAN + K-line File: can.kicad_sch AGND_SENSE

SD Card File: sdcard.kicad_sch AUX_A

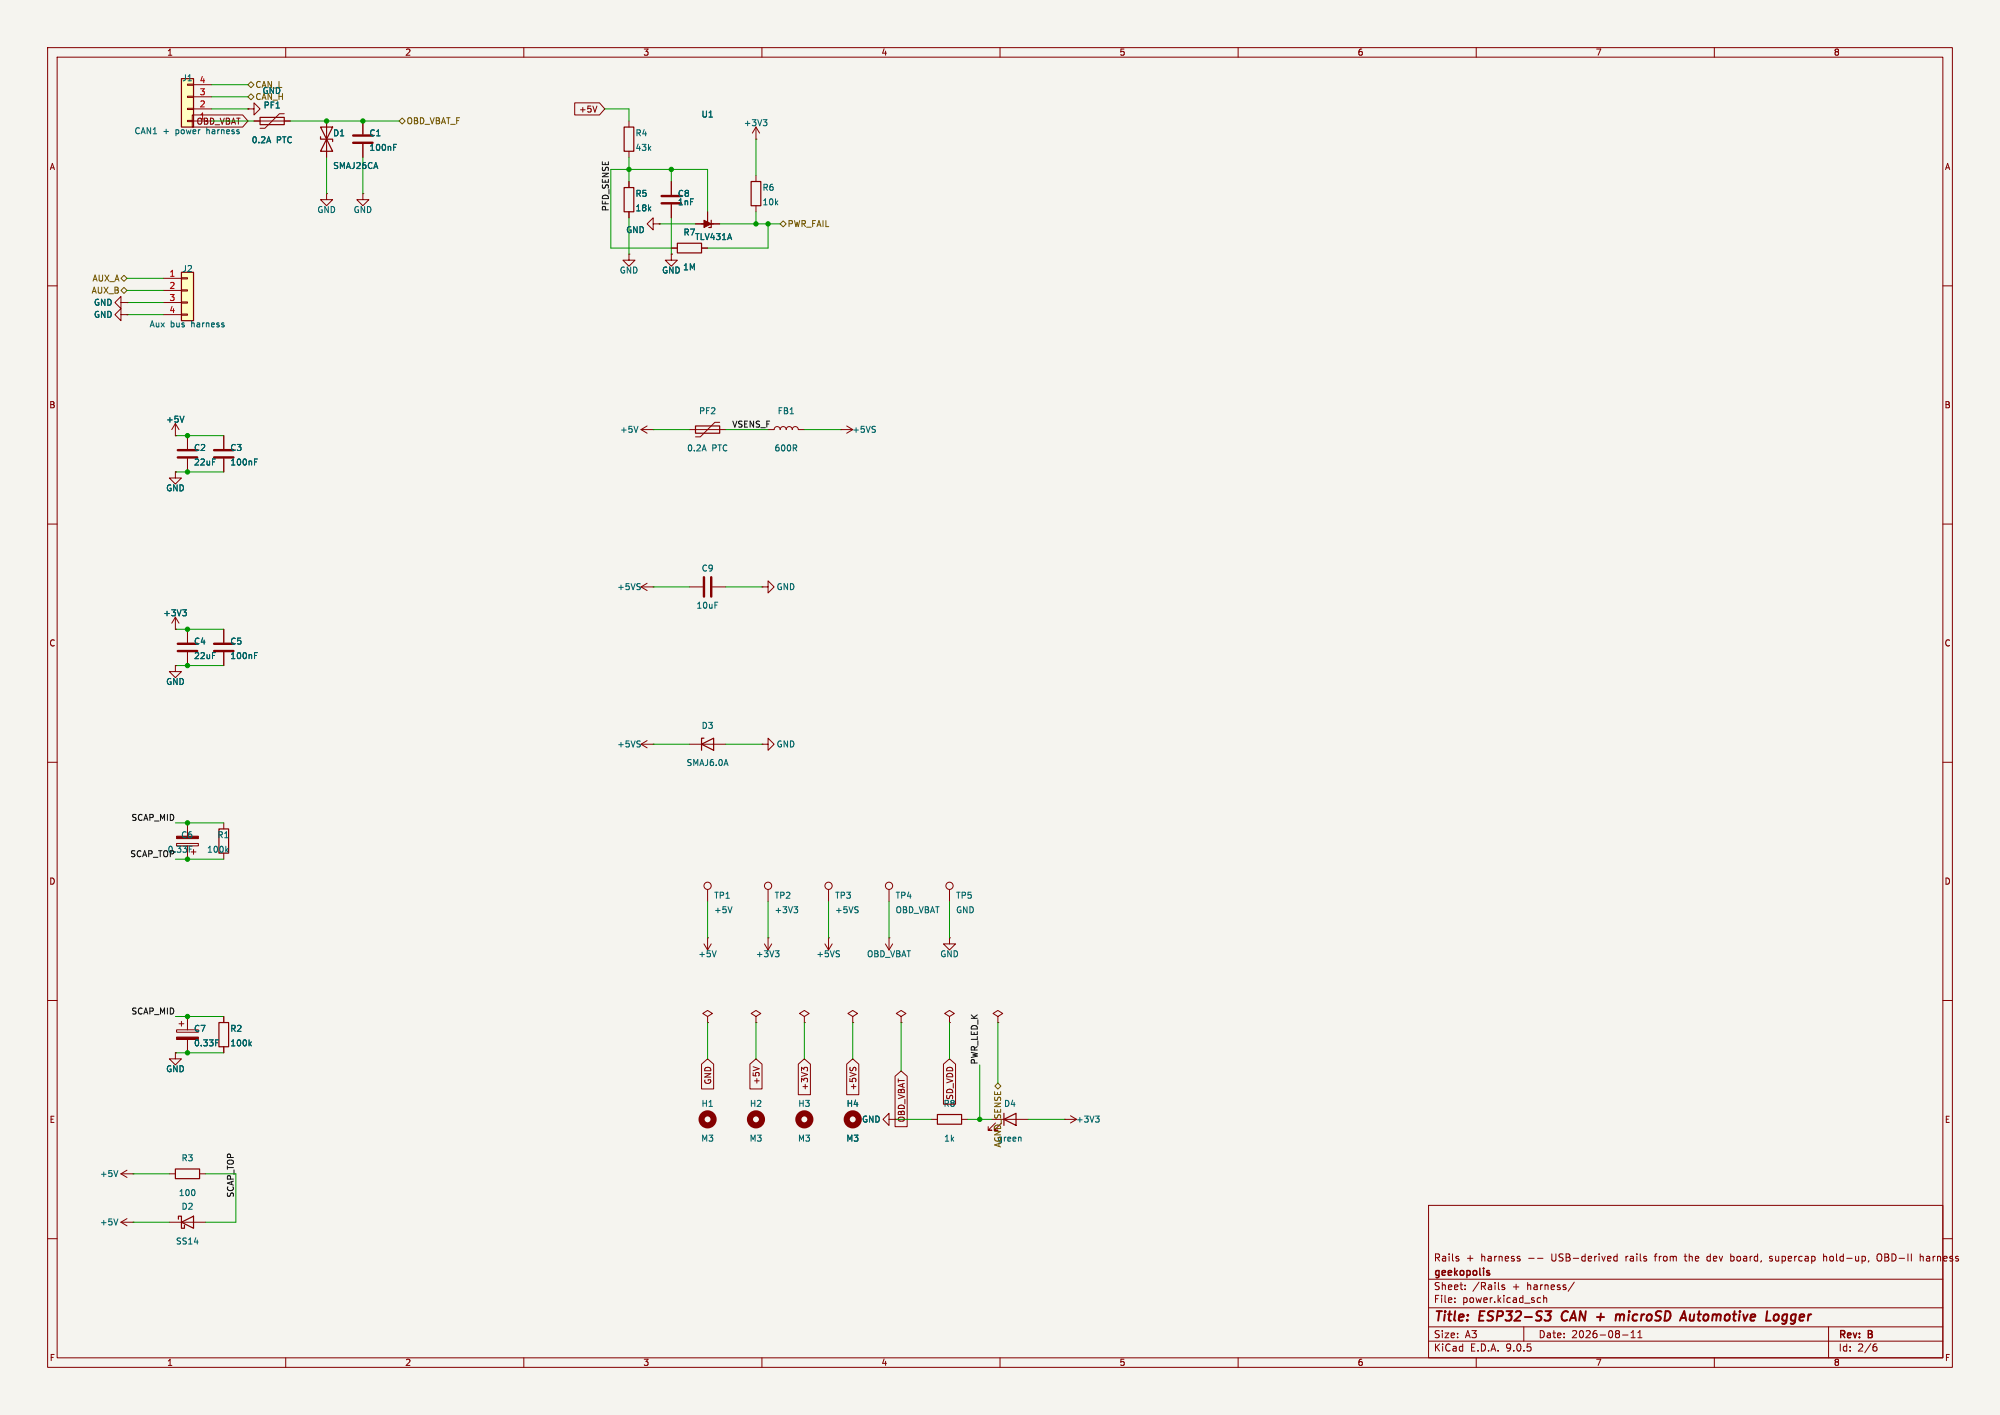
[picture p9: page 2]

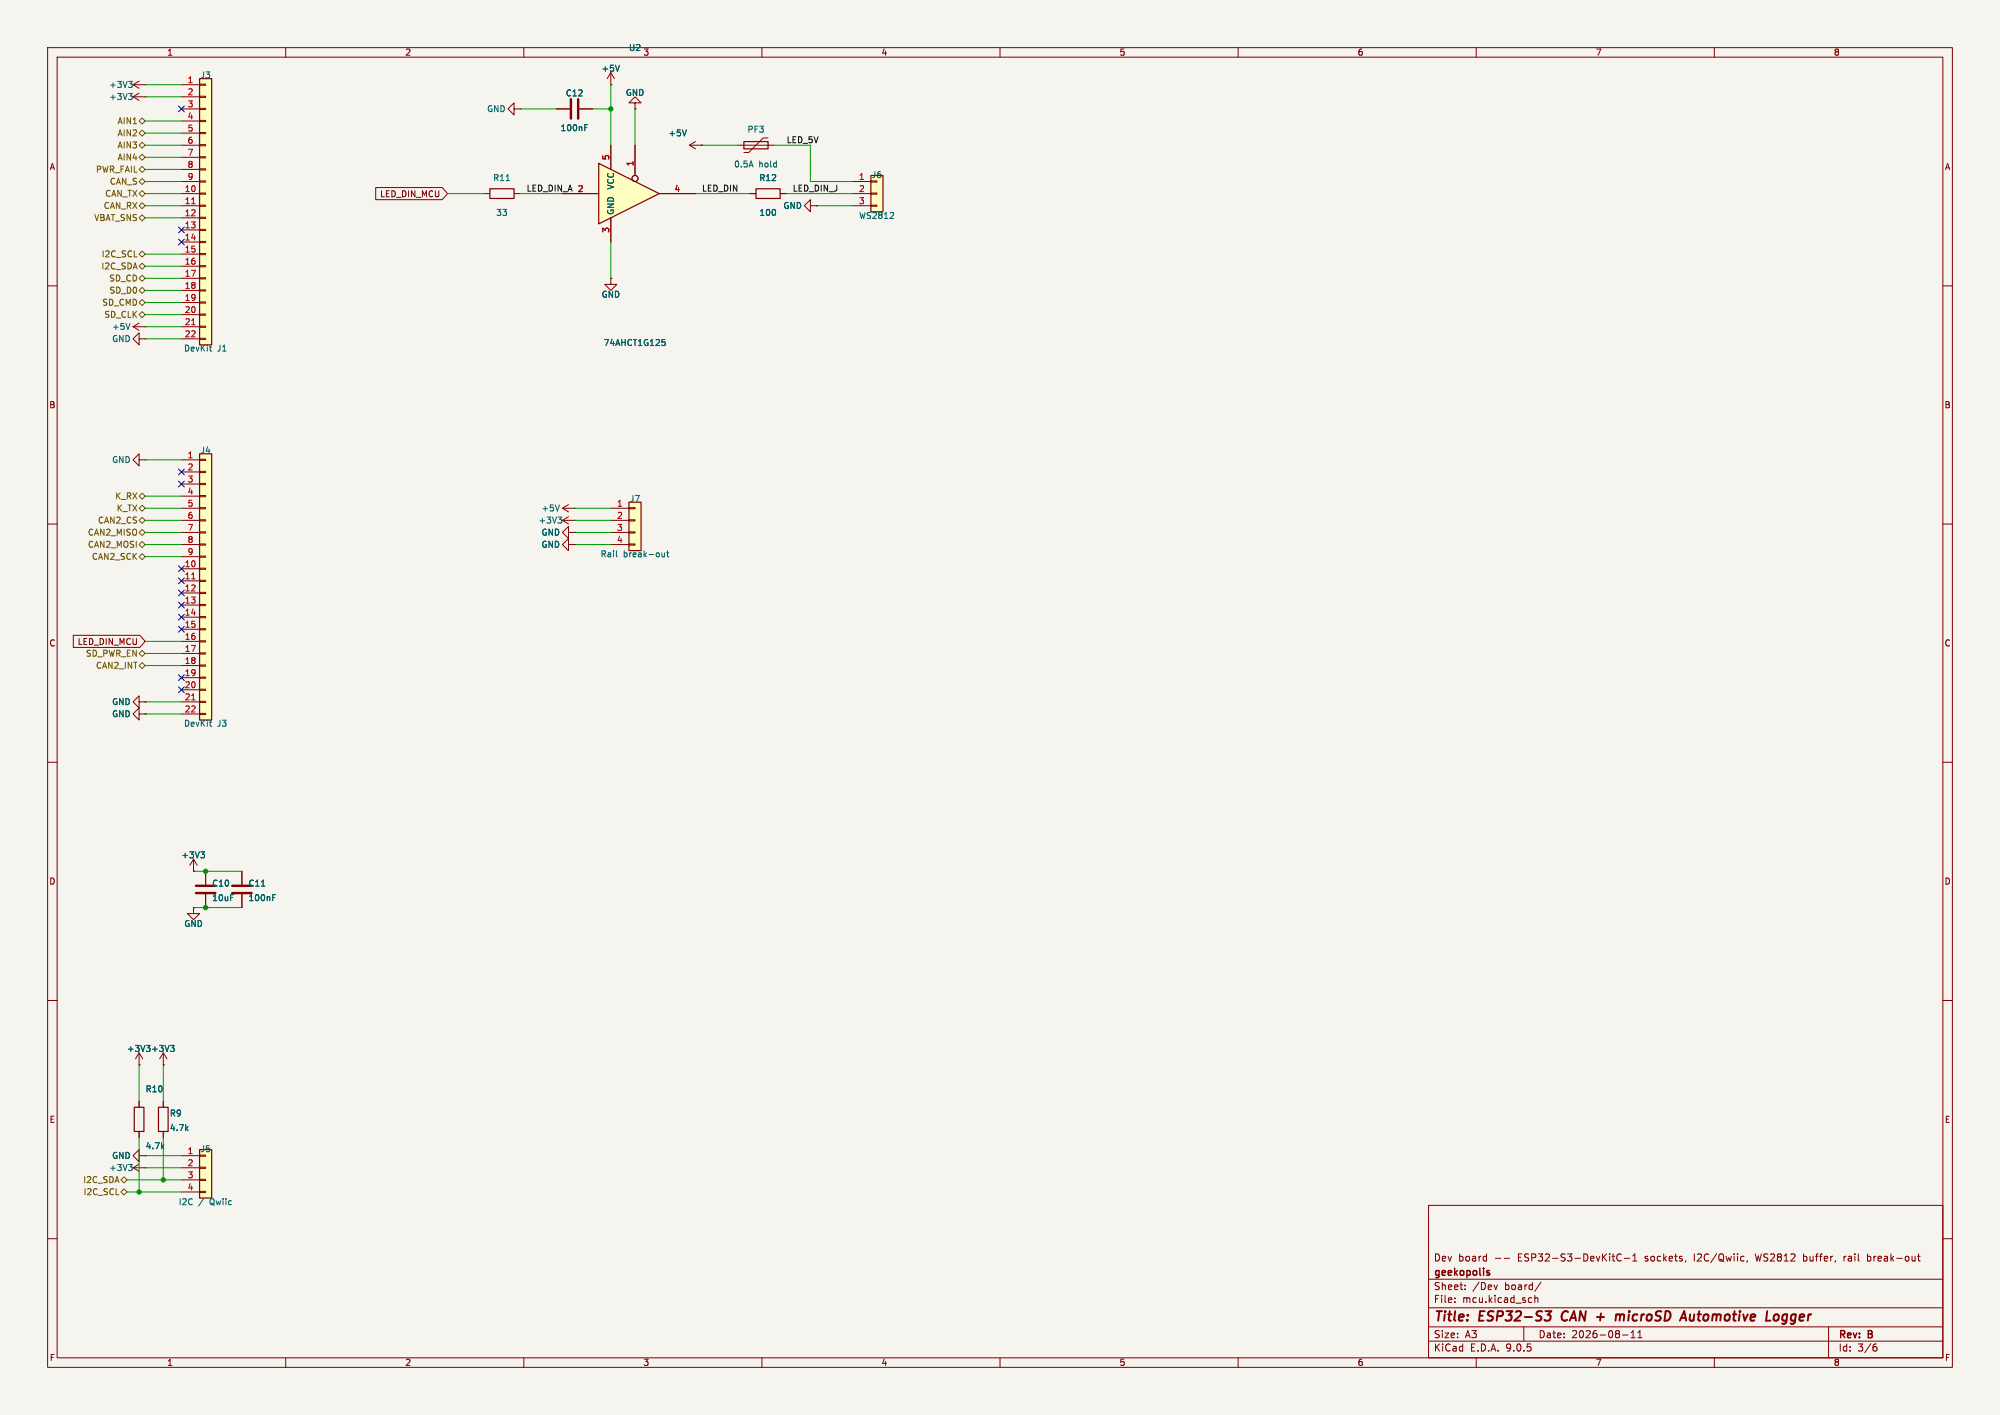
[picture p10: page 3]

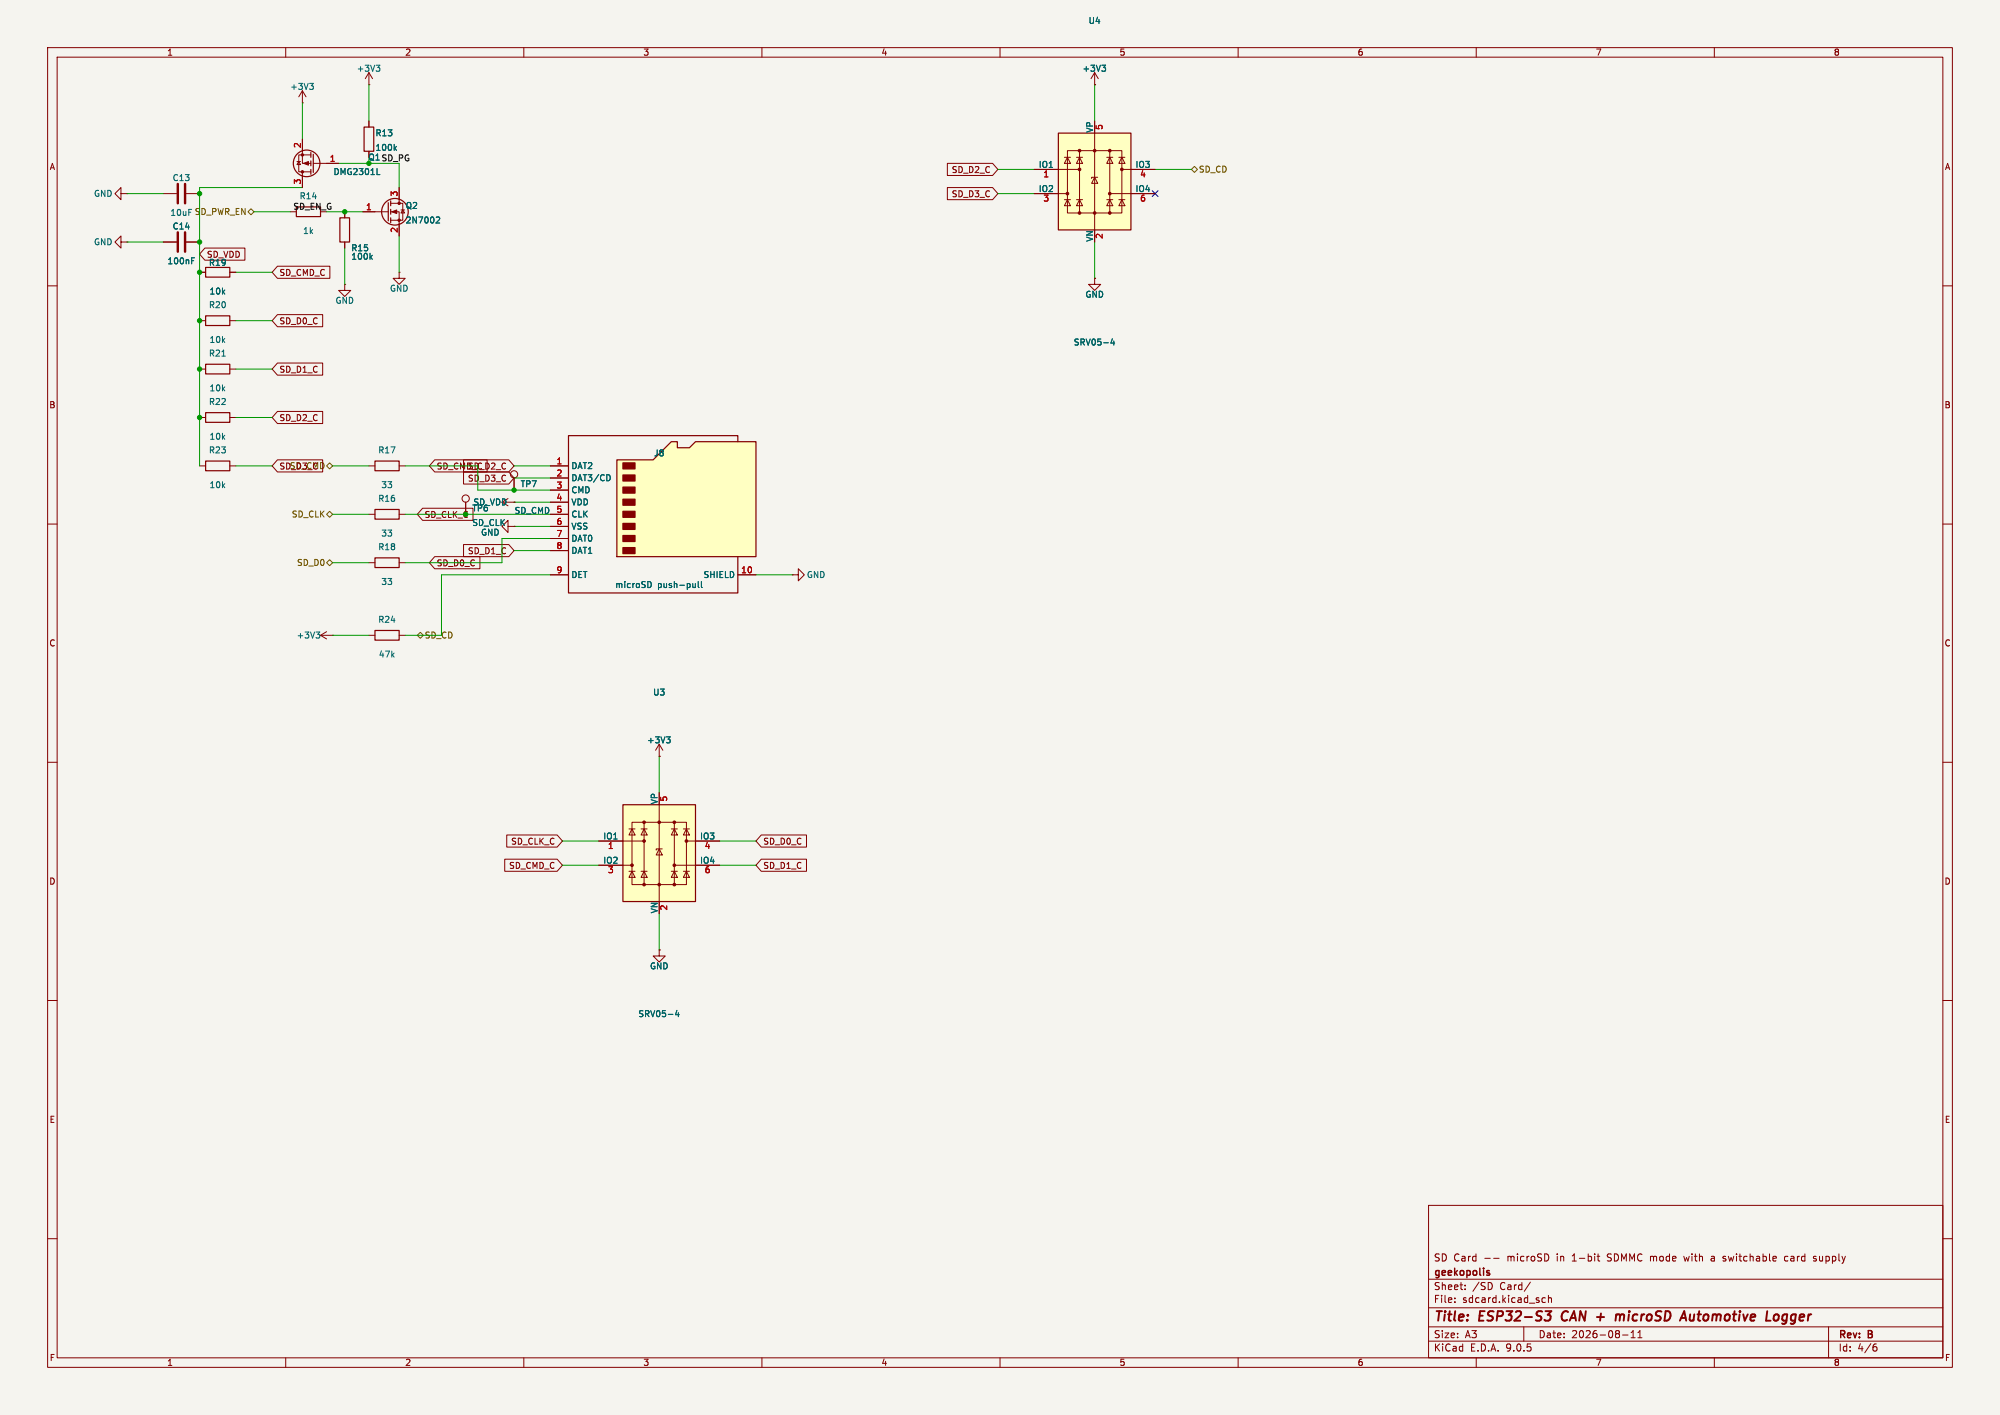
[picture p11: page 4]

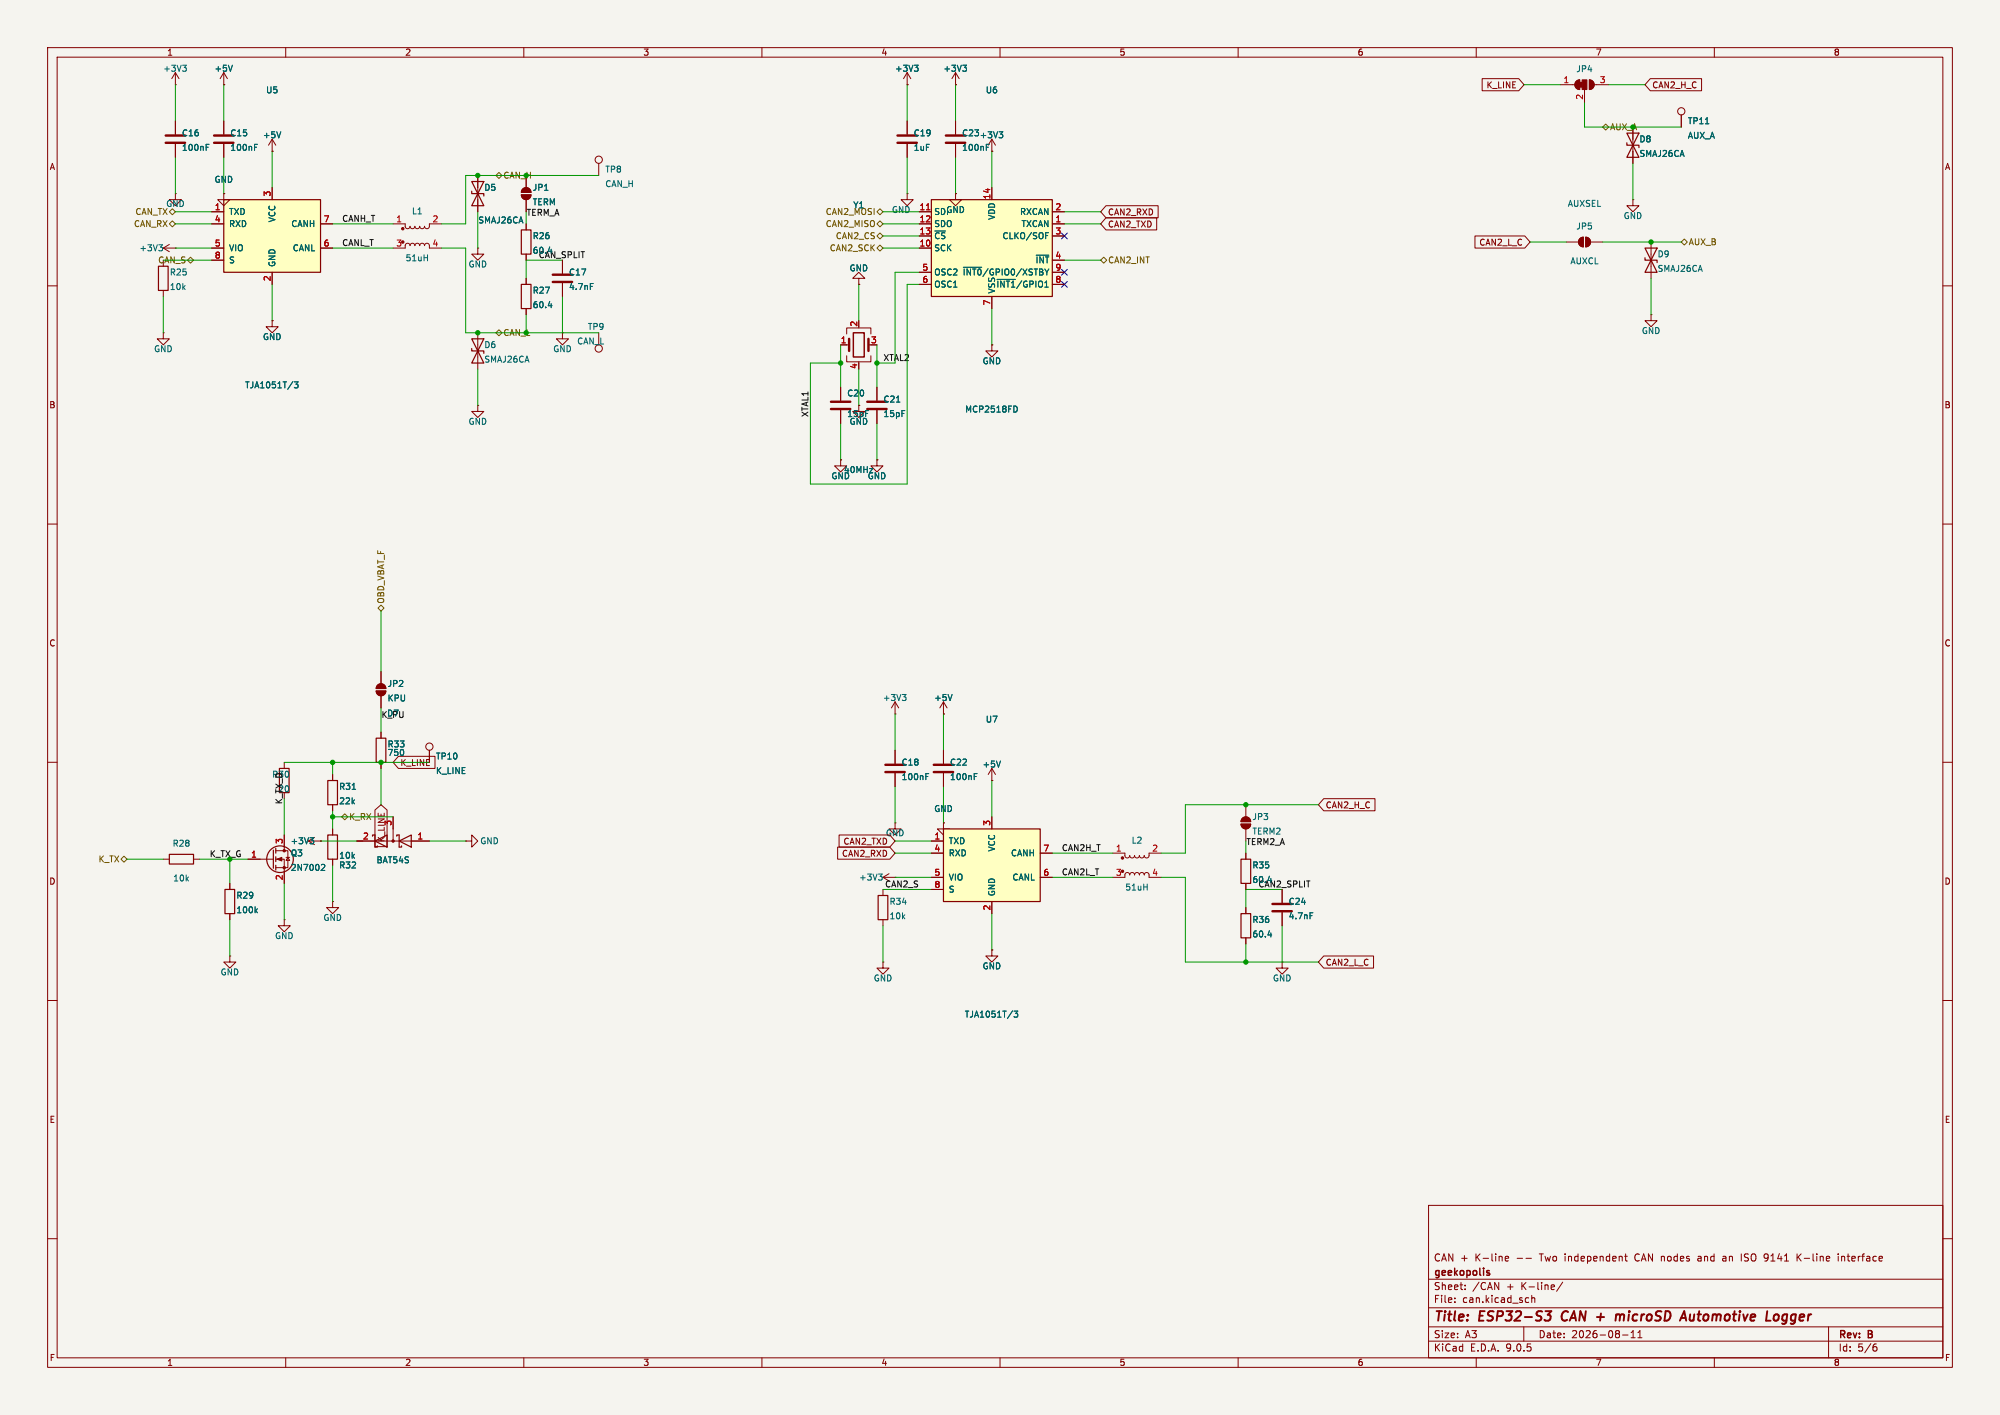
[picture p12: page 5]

7 RXCAN 2 TXCAN 1 CLKO/SOF 3 ~{INT}4 ~{INT0}/GPIO0/XSTBY 9 ~{INT1}/GPIO1 8 U6 MCP2518FD

7 RXCAN 2 TXCAN 1 CLKO/SOF 3 ~{INT}4 ~{INT0}/GPIO0/XSTBY 9 ~{INT1}/GPIO1 8 GND
GND

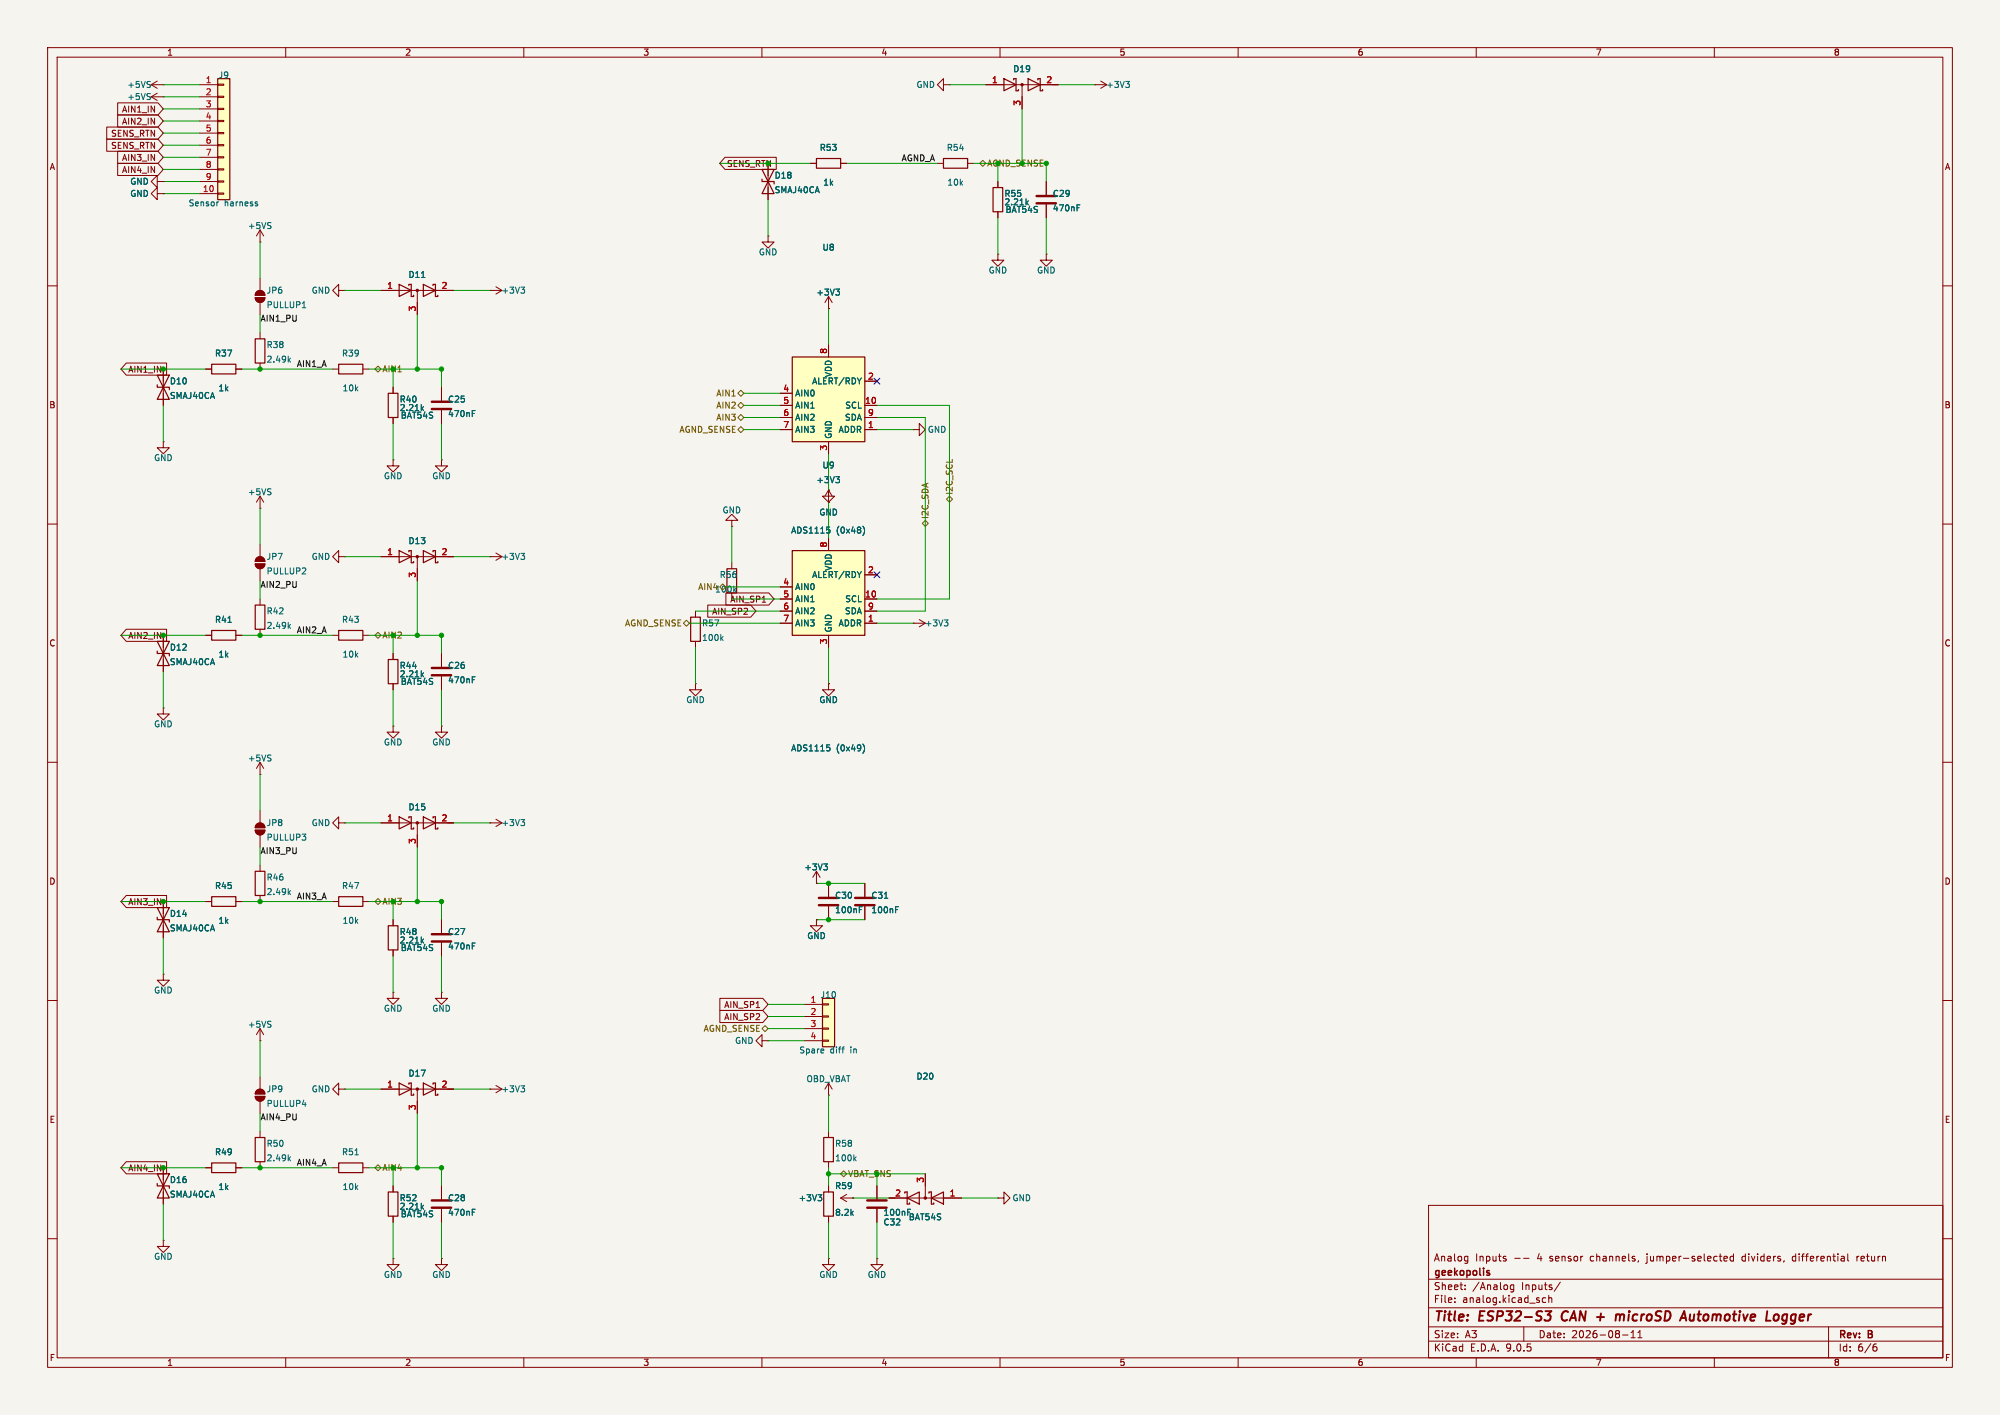
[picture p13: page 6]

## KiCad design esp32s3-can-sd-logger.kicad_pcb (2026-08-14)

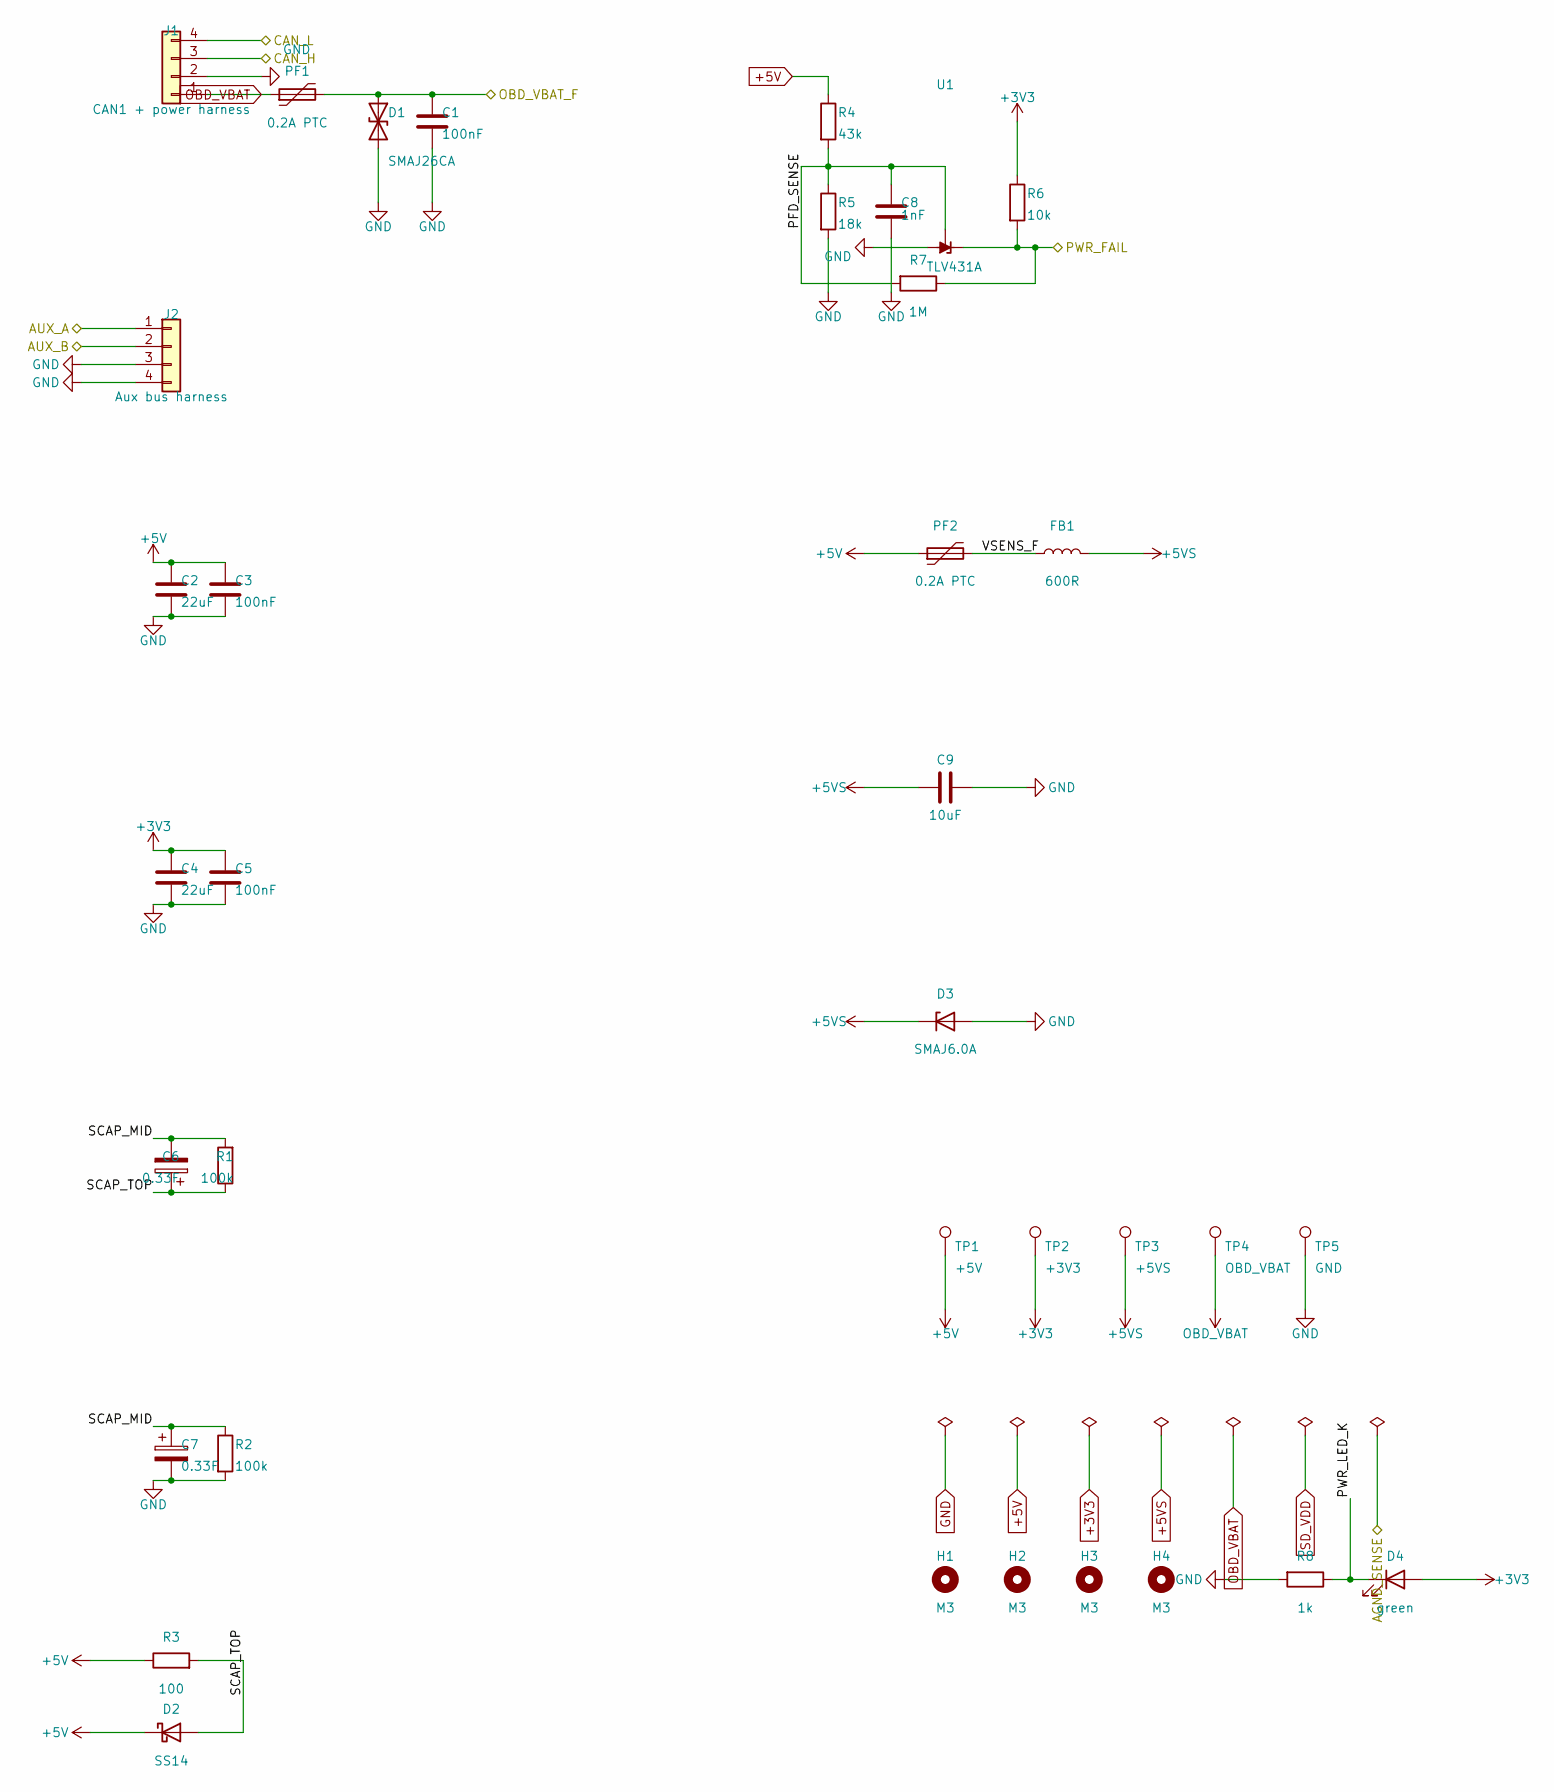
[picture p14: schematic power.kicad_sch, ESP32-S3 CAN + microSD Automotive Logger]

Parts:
C1: 100nF; C_0805_2012Metric; Voltage 100V
C2, C4: 22uF; C_1206_3216Metric; Voltage 16V
C3, C5: 100nF; C_0805_2012Metric; Voltage 16V
C6, C7: 0.33F; CP_Radial_D8.0mm_P3.50mm; Voltage 2.7V; MPN Eaton HB1030-2R5105-R
C8: 1nF; C_0805_2012Metric; Voltage 50V
C9: 10uF; C_1206_3216Metric; Voltage 16V
D1: SMAJ26CA; D_SMA; MPN Diodes Inc SMAJ26CA-13-F
D2: SS14; D_SMA; MPN SS14
D3: SMAJ6.0A; D_SMA; MPN Littelfuse SMAJ6.0A
D4: green; LED_0805_2012Metric
FB1: 600R; L_0805_2012Metric; MPN Wurth 742792022
H1, H2, H3, H4: M3; MountingHole_3.2mm_M3
J1: CAN1 + power harness; JST_PH_B4B-PH-K_1x04_P2.00mm_Vertical; MPN JST B4B-PH-K-S(LF)(SN)
J2: Aux bus harness; JST_PH_B4B-PH-K_1x04_P2.00mm_Vertical; MPN JST B4B-PH-K-S(LF)(SN)
PF1, PF2: 0.2A PTC; R_1812_4532Metric; MPN Bourns MF-MSMF020/60-2
R1, R2: 100k; R_0805_2012Metric
R3: 100; R_1206_3216Metric
R4: 43k; R_0805_2012Metric; Tolerance 1%
R5: 18k; R_0805_2012Metric; Tolerance 1%
R6: 10k; R_0805_2012Metric
R7: 1M; R_0805_2012Metric
R8: 1k; R_0805_2012Metric
TP1: +5V; TestPoint_Pad_D1.5mm
TP2: +3V3; TestPoint_Pad_D1.5mm
TP3: +5VS; TestPoint_Pad_D1.5mm
TP4: OBD_VBAT; TestPoint_Pad_D1.5mm
TP5: GND; TestPoint_Pad_D1.5mm
U1: TLV431A; SOT-23; MPN TLV431ASN1T1G

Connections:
+3V3: C4.1, C5.1, D4.2 (A), R6.1, TP2.1; also elsewhere on the board
+5V: C2.1, C3.1, D2.1 (K), PF2.1, R3.1, R4.1, TP1.1; also elsewhere on the board
+5VS: C9.1, D3.1 (K), FB1.2, TP3.1; also elsewhere on the board
AUX_A: J2.1; also elsewhere on the board
AUX_B: J2.2; also elsewhere on the board
CAN_H: J1.3; also elsewhere on the board
OBD_VBAT: J1.1, PF1.1, TP4.1; also elsewhere on the board
OBD_VBAT_F: C1.1, D1.1 (A1), PF1.2; also elsewhere on the board
PFD_SENSE: C8.1, R4.2, R5.1, R7.2, U1.2 (REF)
PWR_FAIL: R6.2, R7.1, U1.1 (K); also elsewhere on the board
PWR_LED_K: D4.1 (K), R8.1
SCAP_MID: C6.2, C7.1, R1.2, R2.1
SCAP_TOP: C6.1, D2.2 (A), R1.1, R3.2
VSENS_F: FB1.1, PF2.2

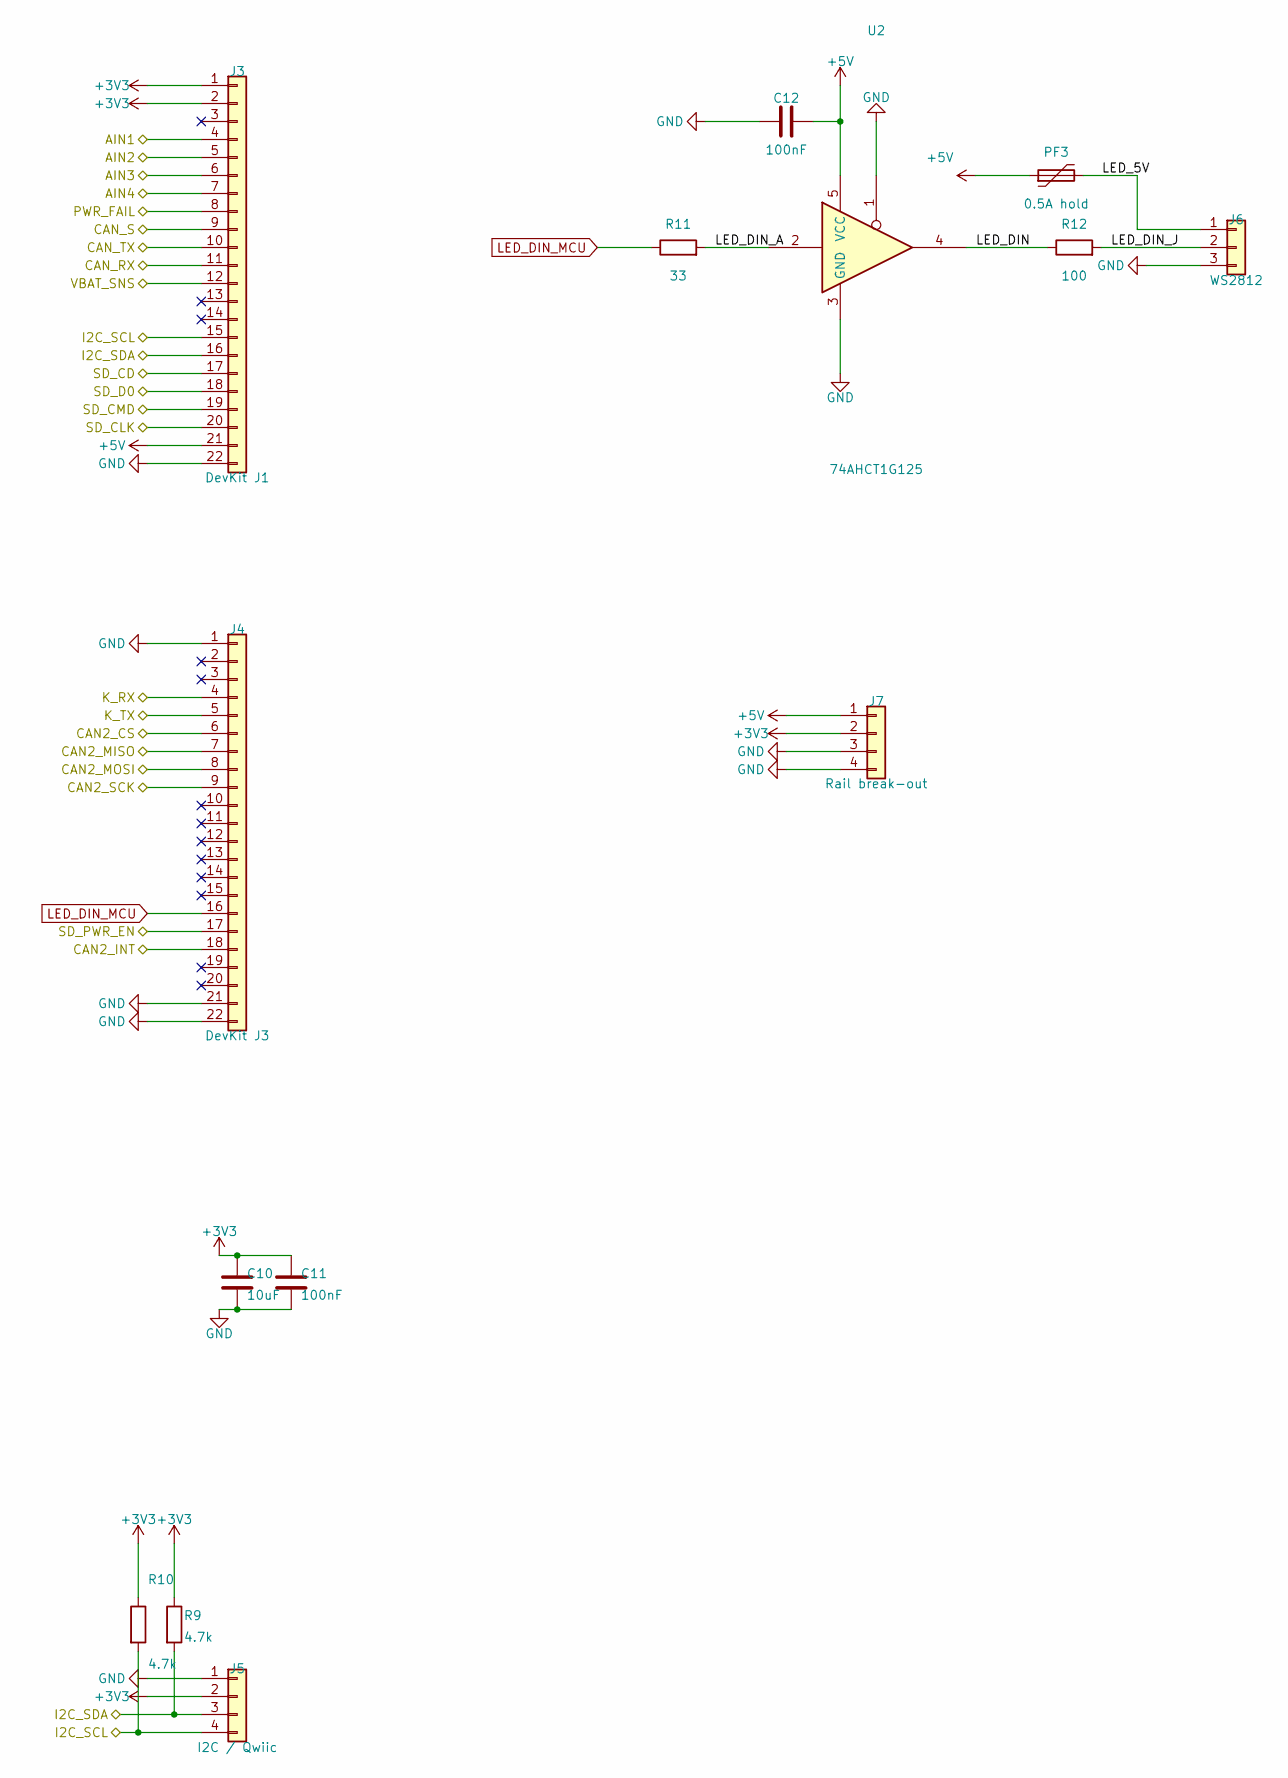
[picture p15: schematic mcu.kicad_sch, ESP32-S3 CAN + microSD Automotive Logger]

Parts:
C10: 10uF; C_1206_3216Metric; Voltage 16V
C11, C12: 100nF; C_0805_2012Metric; Voltage 16V
J3: DevKit J1; PinSocket_1x22_P2.54mm_Vertical; MPN ESP32-S3-DevKitC-1 J1
J4: DevKit J3; PinSocket_1x22_P2.54mm_Vertical; MPN ESP32-S3-DevKitC-1 J3
J5: I2C / Qwiic; PinHeader_1x04_P2.54mm_Vertical
J6: WS2812; PinHeader_1x03_P2.54mm_Vertical
J7: Rail break-out; PinHeader_1x04_P2.54mm_Vertical
PF3: 0.5A hold; R_1812_4532Metric; MPN Bourns MF-MSMF050-2
R9, R10: 4.7k; R_0805_2012Metric
R11: 33; R_0805_2012Metric
R12: 100; R_0805_2012Metric
U2: 74AHCT1G125; SOT-23-5; MPN SN74AHCT1G125DBVR

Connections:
+3V3: C10.1, C11.1, J3.1, J3.2, J5.2, J7.2, R9.1, R10.1; also elsewhere on the board
+5V: C12.1, J3.21, J7.1, PF3.1, U2.5 (VCC); also elsewhere on the board
AIN1: J3.4; also elsewhere on the board
AIN2: J3.5; also elsewhere on the board
AIN3: J3.6; also elsewhere on the board
AIN4: J3.7; also elsewhere on the board
CAN2_CS: J4.6; also elsewhere on the board
CAN2_INT: J4.18; also elsewhere on the board
CAN2_MISO: J4.7; also elsewhere on the board
CAN2_MOSI: J4.8; also elsewhere on the board
CAN2_SCK: J4.9; also elsewhere on the board
CAN_RX: J3.11; also elsewhere on the board
CAN_S: J3.9; also elsewhere on the board
CAN_TX: J3.10; also elsewhere on the board
I2C_SCL: J3.15, J5.4, R10.2; also elsewhere on the board
I2C_SDA: J3.16, J5.3, R9.2; also elsewhere on the board
K_RX: J4.4; also elsewhere on the board
K_TX: J4.5; also elsewhere on the board
LED_5V: J6.1, PF3.2
LED_DIN: R12.1, U2.4
LED_DIN_A: R11.2, U2.2
LED_DIN_J: J6.2, R12.2
LED_DIN_MCU: J4.16, R11.1
PWR_FAIL: J3.8; also elsewhere on the board
SD_CD: J3.17; also elsewhere on the board
SD_CLK: J3.20; also elsewhere on the board
SD_CMD: J3.19; also elsewhere on the board
SD_D0: J3.18; also elsewhere on the board
SD_PWR_EN: J4.17; also elsewhere on the board
VBAT_SNS: J3.12; also elsewhere on the board

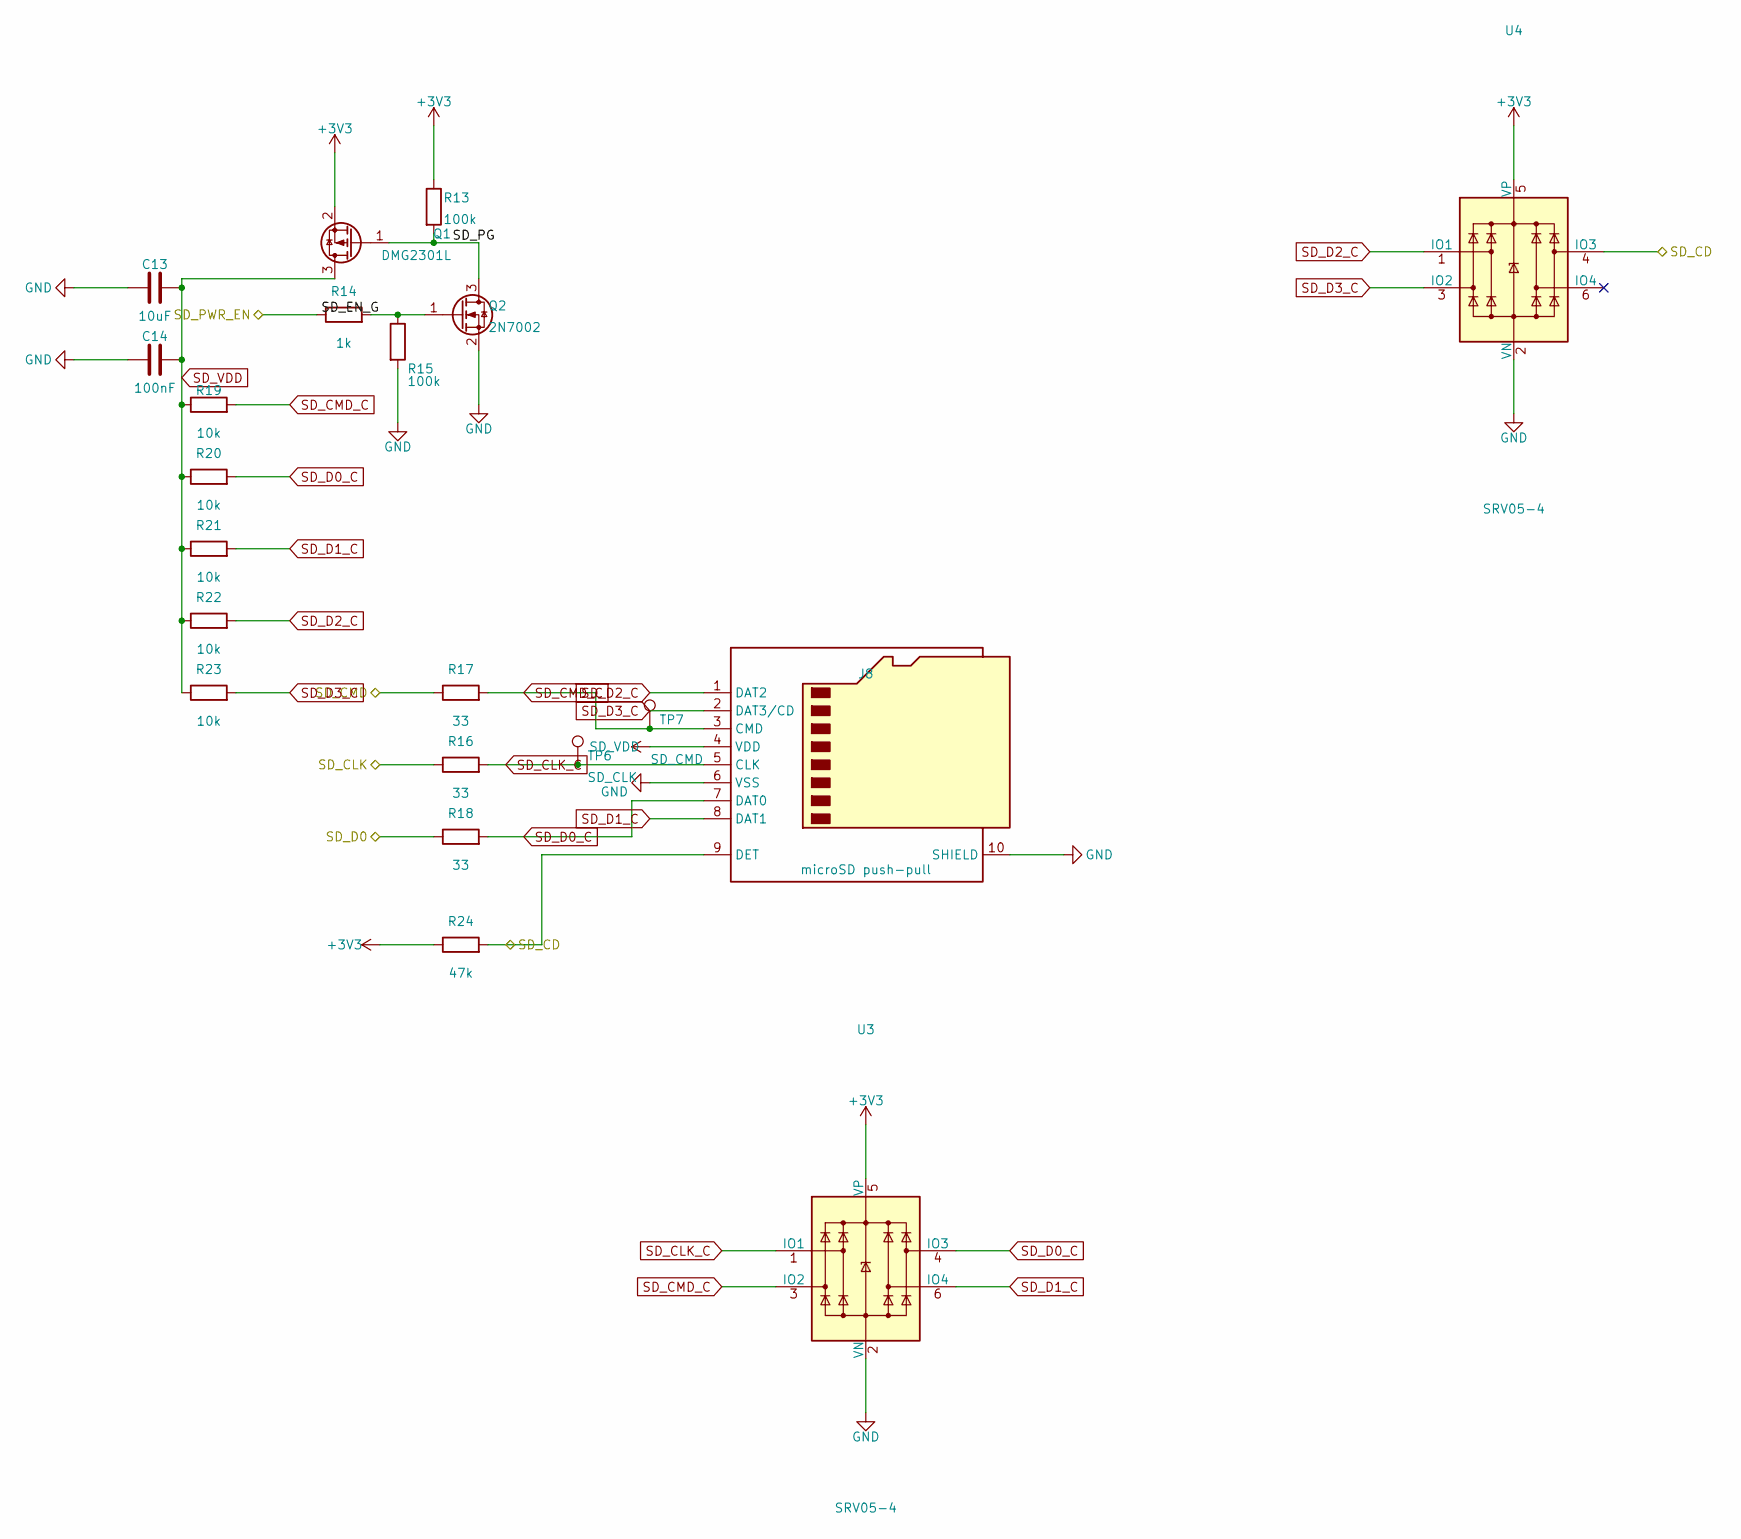
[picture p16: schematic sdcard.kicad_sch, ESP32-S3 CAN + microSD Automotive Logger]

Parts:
C13: 10uF; C_1206_3216Metric; Voltage 16V
C14: 100nF; C_0805_2012Metric; Voltage 16V
J8: microSD push-pull; microSD_HC_Hirose_DM3D-SF; MPN Hirose DM3D-SF
Q1: DMG2301L; SOT-23; MPN DMG2301L
Q2: 2N7002; SOT-23; MPN 2N7002
R13, R15: 100k; R_0805_2012Metric
R14: 1k; R_0805_2012Metric
R16, R17, R18: 33; R_0805_2012Metric
R19, R20, R21, R22, R23: 10k; R_0805_2012Metric
R24: 47k; R_0805_2012Metric
TP6: SD_CLK; TestPoint_Pad_D1.5mm
TP7: SD_CMD; TestPoint_Pad_D1.5mm
U3, U4: SRV05-4; SOT-23-6; MPN Semtech SRV05-4.TCT

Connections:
+3V3: Q1.2 (S), R13.1, R24.1, U3.5 (VP), U4.5 (VP); also elsewhere on the board
SD_CD: J8.9 (DET), R24.2, U4.4 (IO3); also elsewhere on the board
SD_CLK: R16.1; also elsewhere on the board
SD_CLK_C: J8.5 (CLK), R16.2, TP6.1, U3.1 (IO1)
SD_CMD: R17.1; also elsewhere on the board
SD_CMD_C: J8.3 (CMD), R17.2, R19.2, TP7.1, U3.3 (IO2)
SD_D0: R18.1; also elsewhere on the board
SD_D0_C: J8.7 (DAT0), R18.2, R20.2, U3.4 (IO3)
SD_D1_C: J8.8 (DAT1), R21.2, U3.6 (IO4)
SD_D2_C: J8.1 (DAT2), R22.2, U4.1 (IO1)
SD_D3_C: J8.2 (DAT3/CD), R23.2, U4.3 (IO2)
SD_EN_G: Q2.1 (G), R14.2, R15.1
SD_PG: Q1.1 (G), Q2.3 (D), R13.2
SD_PWR_EN: R14.1; also elsewhere on the board
SD_VDD: C13.1, C14.1, J8.4 (VDD), Q1.3 (D), R19.1, R20.1, R21.1, R22.1, R23.1

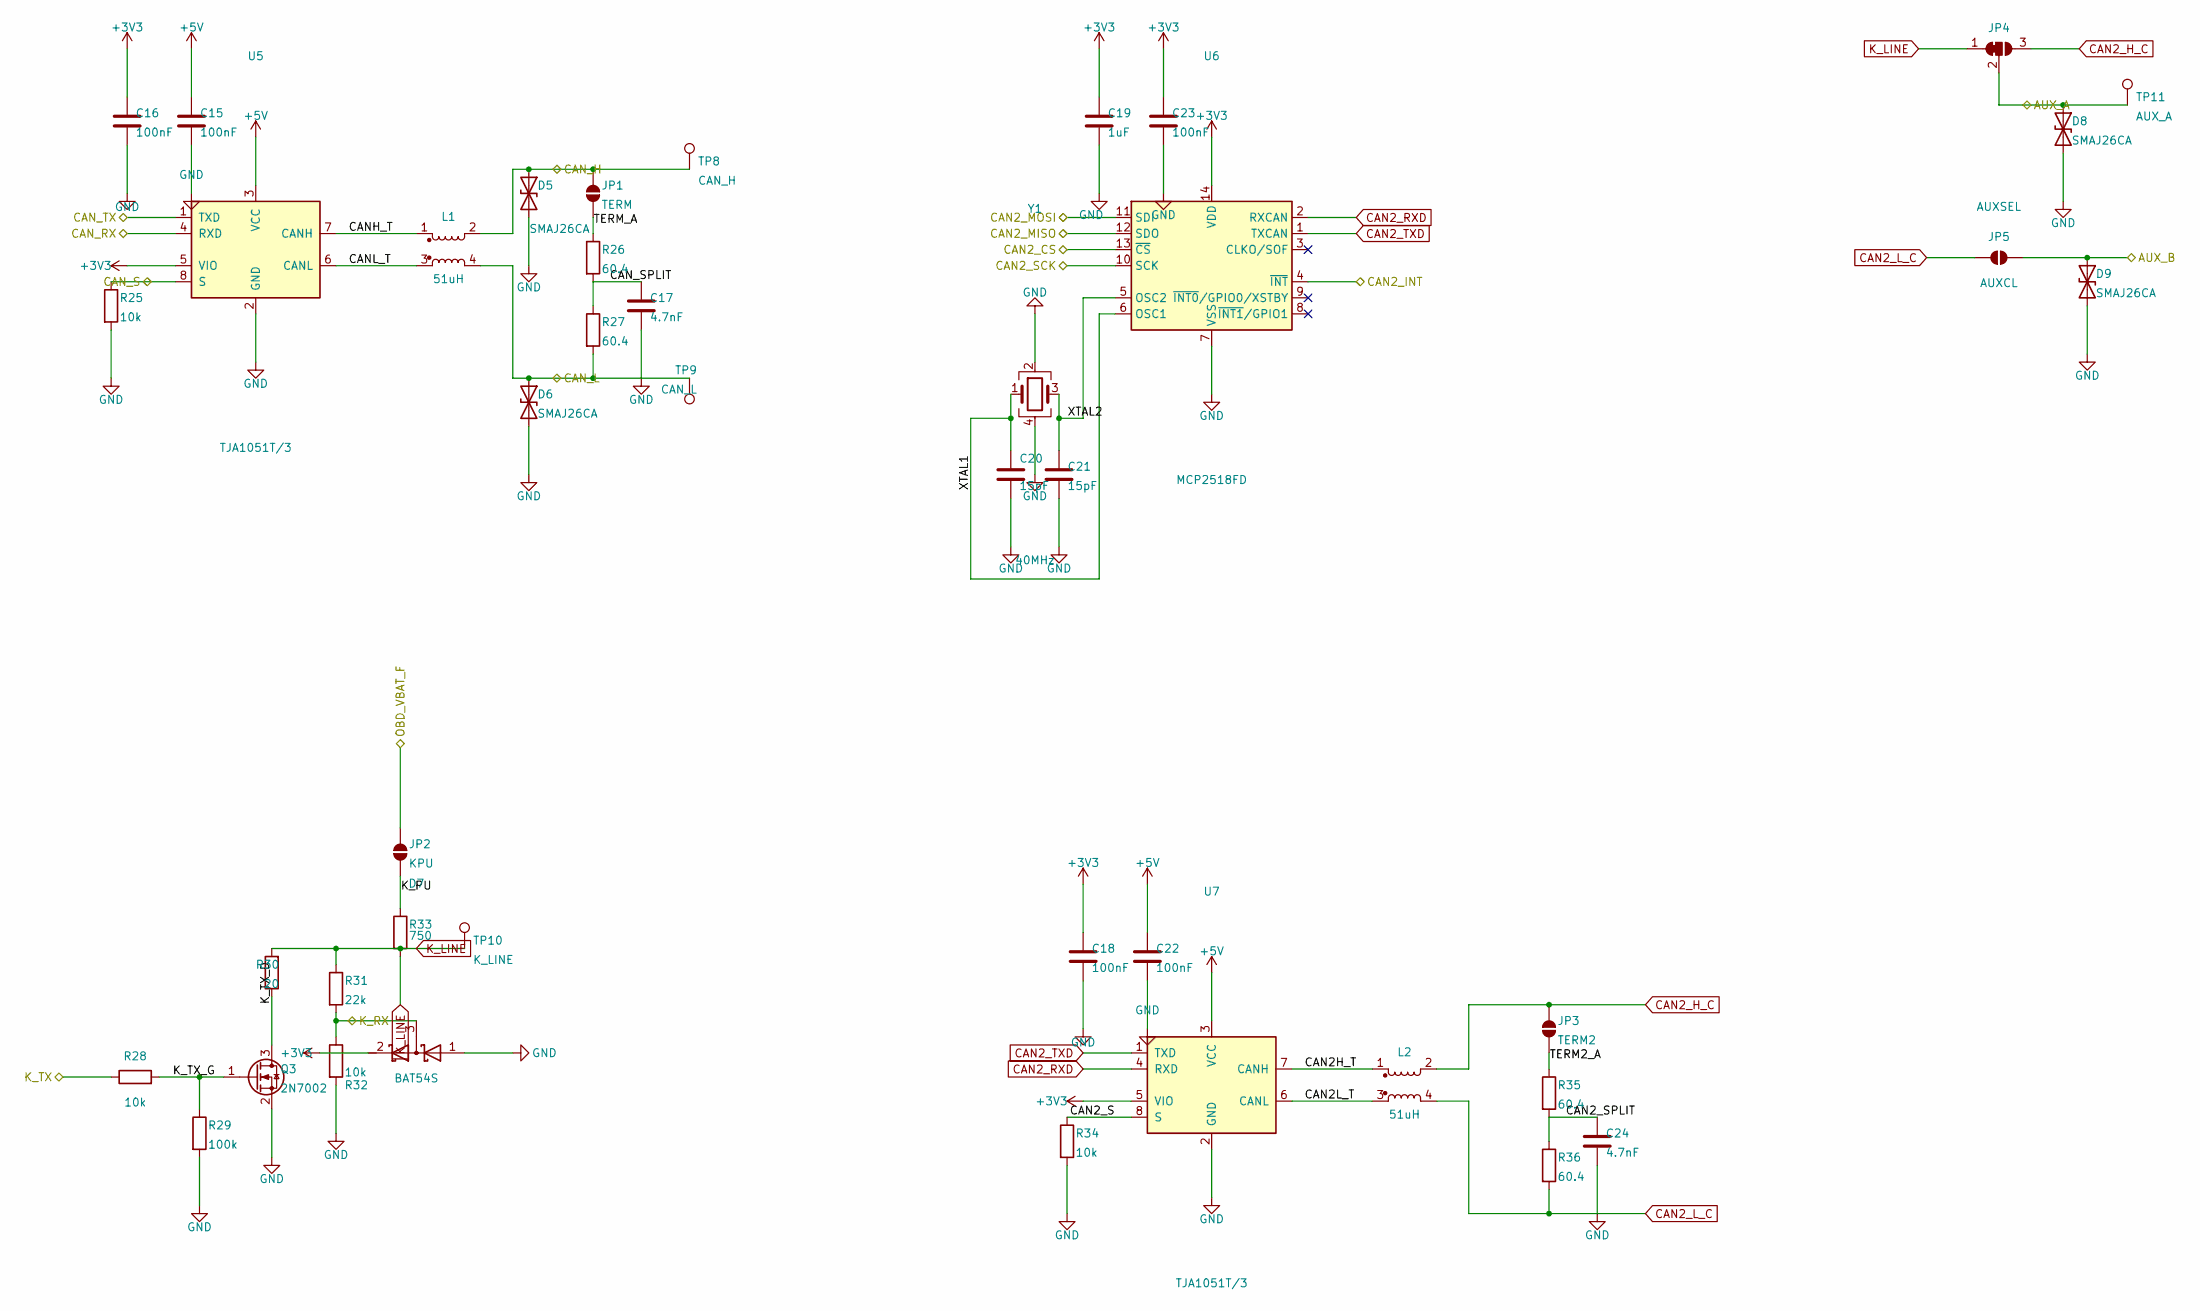
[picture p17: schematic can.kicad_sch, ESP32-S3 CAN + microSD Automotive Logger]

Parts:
C15, C16, C18, C22, C23: 100nF; C_0805_2012Metric; Voltage 16V
C17, C24: 4.7nF; C_0805_2012Metric; Voltage 50V
C19: 1uF; C_0805_2012Metric; Voltage 16V
C20, C21: 15pF; C_0805_2012Metric; Voltage 50V
D5, D6, D8, D9: SMAJ26CA; D_SMA; MPN Diodes Inc SMAJ26CA-13-F
D7: BAT54S; SOT-23; MPN MDD BAT54S
JP1: TERM; SolderJumper-2_P1.3mm_Open_Pad1.0x1.5mm
JP2: KPU; SolderJumper-2_P1.3mm_Open_Pad1.0x1.5mm
JP3: TERM2; SolderJumper-2_P1.3mm_Open_Pad1.0x1.5mm
JP4: AUXSEL; SolderJumper-3_P1.3mm_Bridged12_Pad1.0x1.5mm
JP5: AUXCL; SolderJumper-2_P1.3mm_Open_Pad1.0x1.5mm
L1, L2: 51uH; L_CommonMode_TDK_ACT45B; MPN TDK ACT45B-510-2P-TL003
Q3: 2N7002; SOT-23; MPN onsemi 2N7002
R25, R28, R32, R34: 10k; R_0805_2012Metric
R26, R27, R35, R36: 60.4; R_0805_2012Metric
R29: 100k; R_0805_2012Metric
R30: 20; R_1206_3216Metric
R31: 22k; R_0805_2012Metric
R33: 750; R_1206_3216Metric
TP8: CAN_H; TestPoint_Pad_D1.5mm
TP9: CAN_L; TestPoint_Pad_D1.5mm
TP10: K_LINE; TestPoint_Pad_D1.5mm
TP11: AUX_A; TestPoint_Pad_D1.5mm
U5, U7: TJA1051T/3; SOIC-8_3.9x4.9mm_P1.27mm; MPN TJA1051T/3,118
U6: MCP2518FD; SOIC-14_3.9x8.7mm_P1.27mm; MPN MCP2518FDT-H/SL
Y1: 40MHz; Crystal_SMD_3225-4Pin_3.2x2.5mm; MPN TX322540M4FBCE2T

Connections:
+3V3: C16.1, C18.1, C19.1, C23.1, D7.2 (K), U5.5 (VIO), U6.14 (VDD), U7.5 (VIO); also elsewhere on the board
+5V: C15.1, C22.1, U5.3 (VCC), U7.3 (VCC); also elsewhere on the board
AUX_A: D8.1 (A1), JP4.2 (C), TP11.1; also elsewhere on the board
AUX_B: D9.1 (A1), JP5.1 (A); also elsewhere on the board
CAN2H_T: L2.1, U7.7 (CANH)
CAN2L_T: L2.3, U7.6 (CANL)
CAN2_CS: U6.13 (~CS); also elsewhere on the board
CAN2_H_C: JP3.1 (A), JP4.3 (B), L2.2
CAN2_INT: U6.4 (~INT); also elsewhere on the board
CAN2_MISO: U6.12 (SDO); also elsewhere on the board
CAN2_MOSI: U6.11 (SDI); also elsewhere on the board
CAN2_RXD: U6.2 (RXCAN), U7.4 (RXD)
CAN2_S: R34.1, U7.8 (S)
CAN2_SCK: U6.10 (SCK); also elsewhere on the board
CAN2_SPLIT: C24.1, R35.2, R36.1
CAN2_TXD: U6.1 (TXCAN), U7.1 (TXD)
CANH_T: L1.1, U5.7 (CANH)
CANL_T: L1.3, U5.6 (CANL)
CAN_H: D5.1 (A1), JP1.1 (A), L1.2, TP8.1; also elsewhere on the board
CAN_RX: U5.4 (RXD); also elsewhere on the board
CAN_S: R25.1, U5.8 (S); also elsewhere on the board
CAN_SPLIT: C17.1, R26.2, R27.1
CAN_TX: U5.1 (TXD); also elsewhere on the board
K_LINE: JP4.1 (A), R30.2, R31.1, R33.2, TP10.1
K_PU: JP2.2 (B), R33.1
K_RX: D7.3 (common), R31.2, R32.1; also elsewhere on the board
K_TX: R28.1; also elsewhere on the board
K_TX_D: Q3.3 (D), R30.1
K_TX_G: Q3.1 (G), R28.2, R29.1
OBD_VBAT_F: JP2.1 (A); also elsewhere on the board
TERM2_A: JP3.2 (B), R35.1
TERM_A: JP1.2 (B), R26.1
XTAL1: C20.1, U6.6 (OSC1), Y1.1
XTAL2: C21.1, U6.5 (OSC2), Y1.3

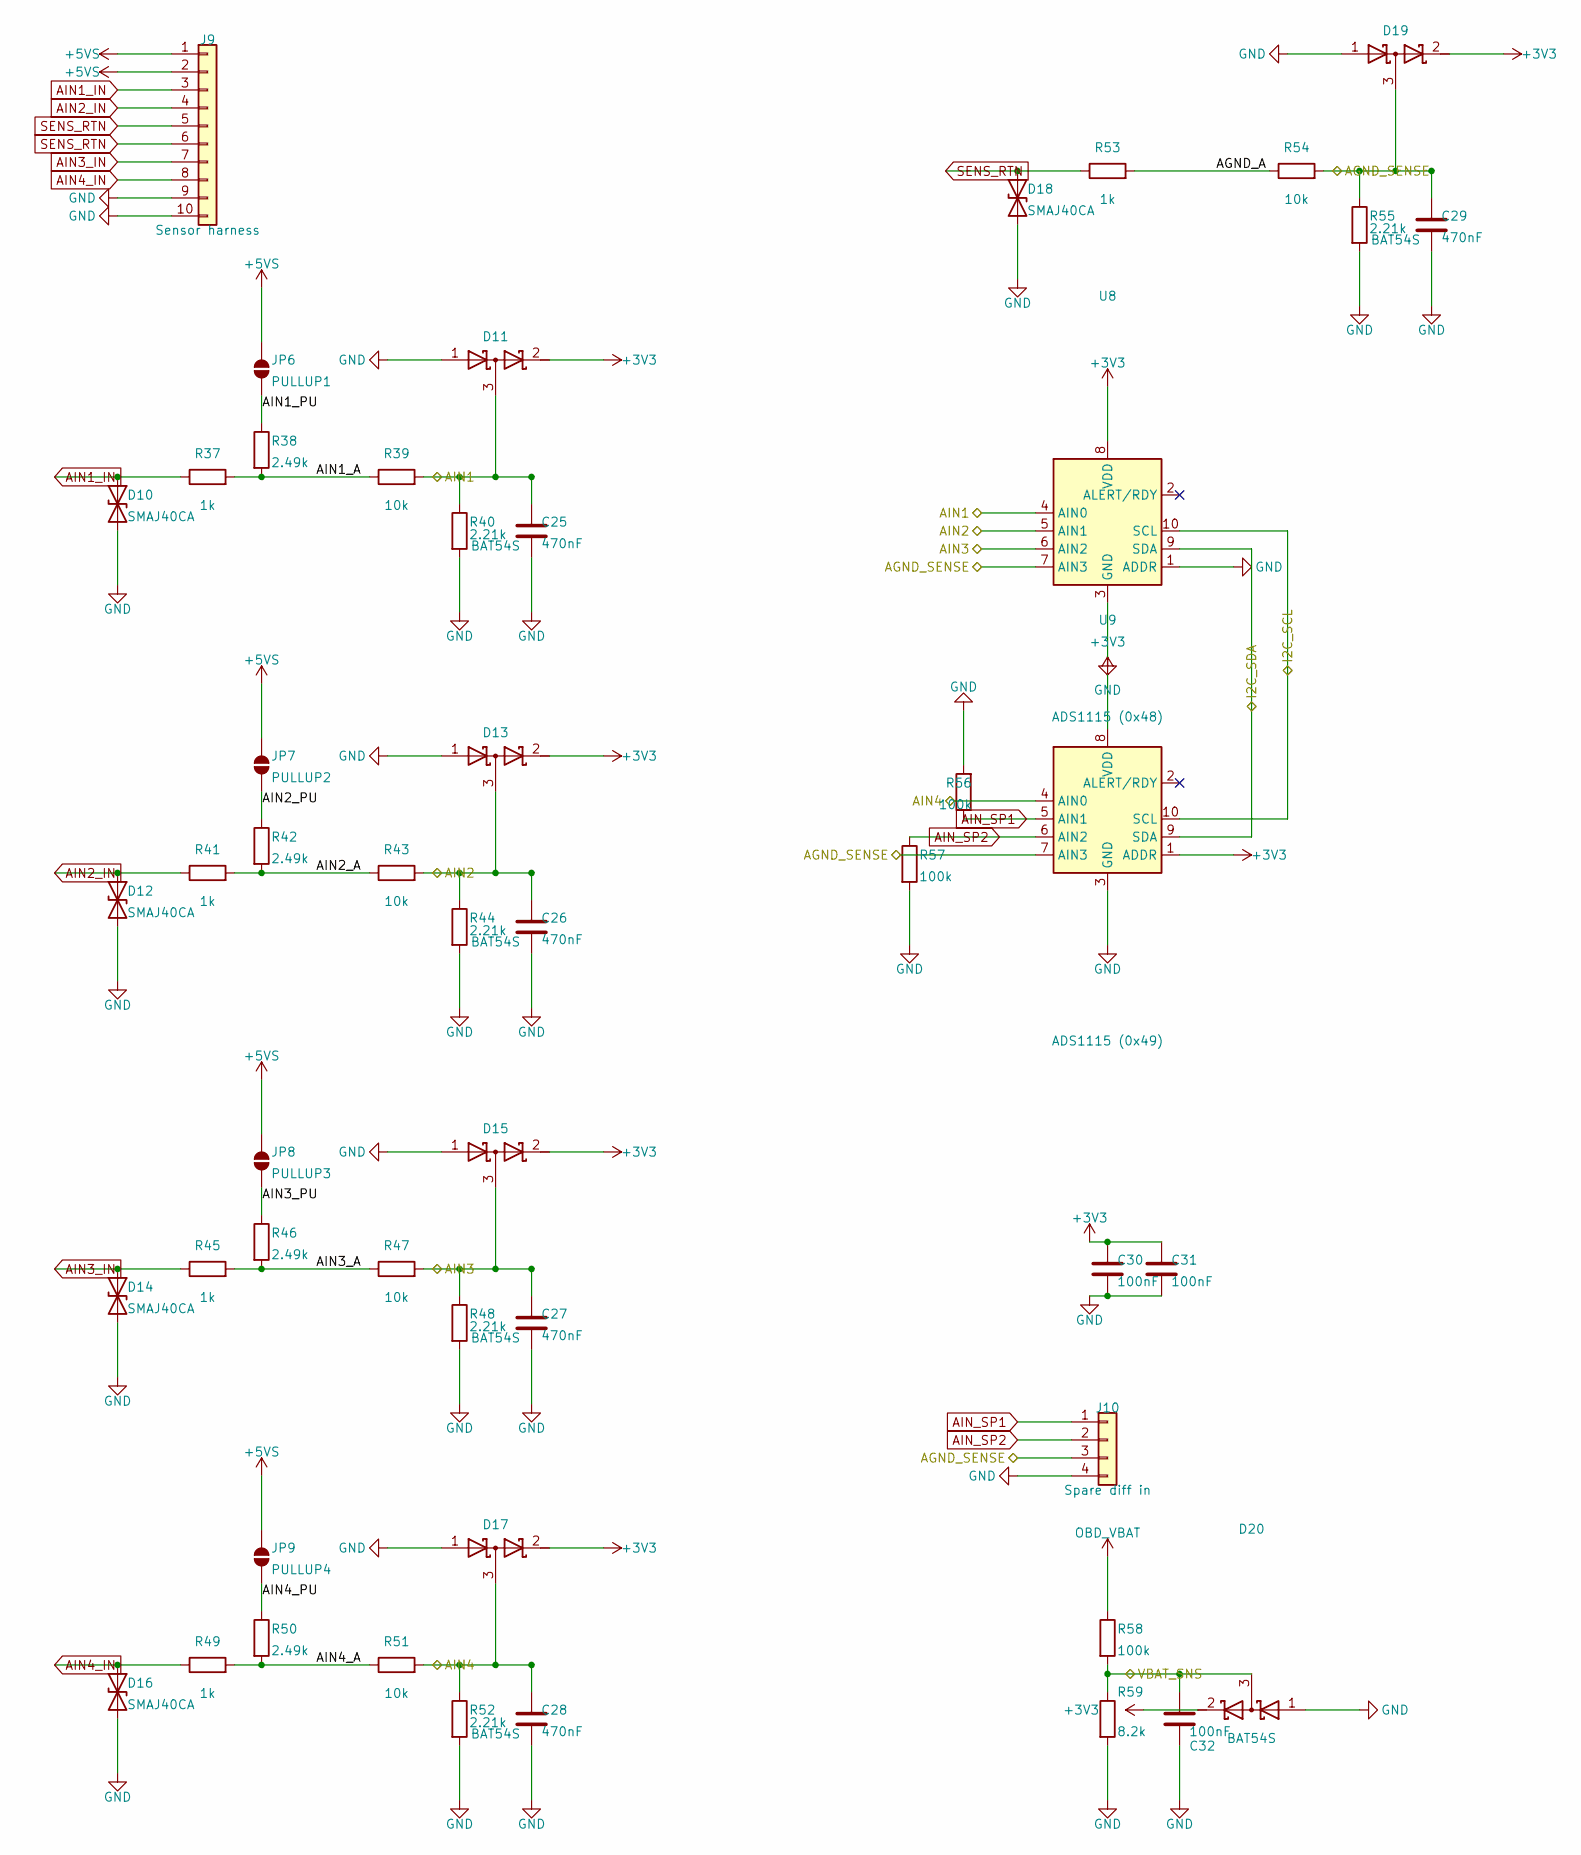
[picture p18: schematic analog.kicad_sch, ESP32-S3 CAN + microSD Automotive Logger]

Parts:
C25, C26, C27, C28, C29: 470nF; C_0805_2012Metric; Voltage 50V
C30, C31, C32: 100nF; C_0805_2012Metric; Voltage 16V
D10, D12, D14, D16, D18: SMAJ40CA; D_SMA; MPN Littelfuse SMAJ40CA
D11, D13, D15, D17, D19, D20: BAT54S; SOT-23; MPN MDD BAT54S
J9: Sensor harness; JST_PH_B10B-PH-K_1x10_P2.00mm_Vertical; MPN JST B10B-PH-K-S(LF)(SN)
J10: Spare diff in; PinHeader_1x04_P2.54mm_Vertical
JP6: PULLUP1; SolderJumper-2_P1.3mm_Open_Pad1.0x1.5mm
JP7: PULLUP2; SolderJumper-2_P1.3mm_Open_Pad1.0x1.5mm
JP8: PULLUP3; SolderJumper-2_P1.3mm_Open_Pad1.0x1.5mm
JP9: PULLUP4; SolderJumper-2_P1.3mm_Open_Pad1.0x1.5mm
R37, R41, R45, R49, R53: 1k; R_0805_2012Metric
R38, R42, R46, R50: 2.49k; R_0805_2012Metric
R39, R43, R47, R51, R54: 10k; R_0805_2012Metric; Tolerance 0.1%
R40, R44, R48, R52, R55: 2.21k; R_0805_2012Metric; Tolerance 0.1%
R56, R57, R58: 100k; R_0805_2012Metric
R59: 8.2k; R_0805_2012Metric
U8: ADS1115 (0x48); VSSOP-10_3x3mm_P0.5mm; MPN ADS1115IDGSR
U9: ADS1115 (0x49); VSSOP-10_3x3mm_P0.5mm; MPN ADS1115IDGSR

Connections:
+3V3: C30.1, C31.1, D11.2 (K), D13.2 (K), D15.2 (K), D17.2 (K), D19.2 (K), D20.2 (K), U8.8 (VDD), U9.1 (ADDR), U9.8 (VDD); also elsewhere on the board
+5VS: J9.1, J9.2, JP6.1 (A), JP7.1 (A), JP8.1 (A), JP9.1 (A); also elsewhere on the board
AGND_A: R53.2, R54.1
AGND_SENSE: C29.1, D19.3 (common), J10.3, R54.2, R55.1, U8.7 (AIN3), U9.7 (AIN3)
AIN1: C25.1, D11.3 (common), R39.2, R40.1, U8.4 (AIN0); also elsewhere on the board
AIN1_A: R37.2, R38.2, R39.1
AIN1_IN: D10.1 (A1), J9.3, R37.1
AIN1_PU: JP6.2 (B), R38.1
AIN2: C26.1, D13.3 (common), R43.2, R44.1, U8.5 (AIN1); also elsewhere on the board
AIN2_A: R41.2, R42.2, R43.1
AIN2_IN: D12.1 (A1), J9.4, R41.1
AIN2_PU: JP7.2 (B), R42.1
AIN3: C27.1, D15.3 (common), R47.2, R48.1, U8.6 (AIN2); also elsewhere on the board
AIN3_A: R45.2, R46.2, R47.1
AIN3_IN: D14.1 (A1), J9.7, R45.1
AIN3_PU: JP8.2 (B), R46.1
AIN4: C28.1, D17.3 (common), R51.2, R52.1, U9.4 (AIN0); also elsewhere on the board
AIN4_A: R49.2, R50.2, R51.1
AIN4_IN: D16.1 (A1), J9.8, R49.1
AIN4_PU: JP9.2 (B), R50.1
AIN_SP1: J10.1, R56.1, U9.5 (AIN1)
AIN_SP2: J10.2, R57.1, U9.6 (AIN2)
I2C_SCL: U8.10 (SCL), U9.10 (SCL); also elsewhere on the board
I2C_SDA: U8.9 (SDA), U9.9 (SDA); also elsewhere on the board
OBD_VBAT: R58.1; also elsewhere on the board
SENS_RTN: D18.1 (A1), J9.5, J9.6, R53.1
VBAT_SNS: C32.1, D20.3 (common), R58.2, R59.1; also elsewhere on the board

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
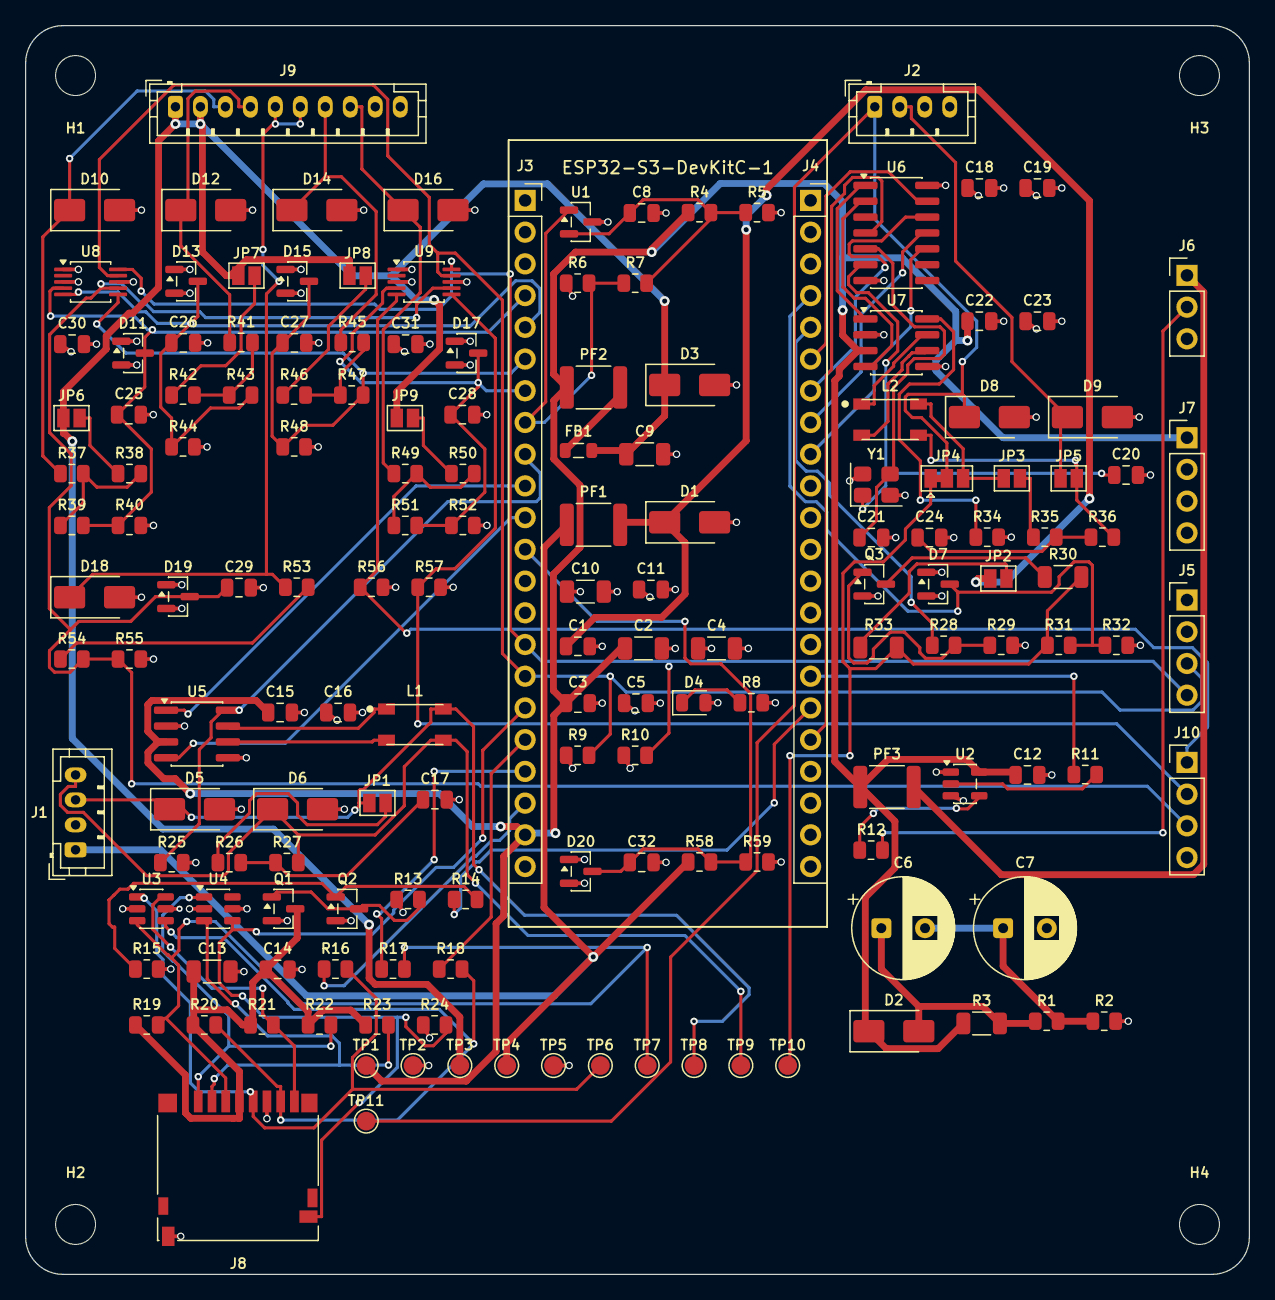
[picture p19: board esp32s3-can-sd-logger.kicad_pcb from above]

Board: 4 copper layers, 98.0 x 100.0 mm, 164 parts (0 on the bottom side), 88 nets.

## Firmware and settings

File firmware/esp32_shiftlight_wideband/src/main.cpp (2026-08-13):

// Shift light + wideband BLE bridge + microSD logger — ESP32-S3 autosport board
//
// Ported from the MINI R53 sketch that runs on a Waveshare ESP32-S3-Zero
// (mini-r53-logger, firmware/esp32_shiftlight_wideband). A verbatim copy of
// that original is kept in firmware/vendor/ and is the control build for
// gen/simulate_firmware.py; every difference below is a difference in the
// hardware, not a change of mind about the logic.
//
// What the board changes, and why each line here is what it is:
//
//   1. Every pin moves. GPIO map is README section 6, and it is the contract.
//      The map is grouped by which side of the carrier each circuit sits on,
//      because the two 22-way sockets slot every plane layer: analog, CAN and
//      the SD bus all hang off the J1 row, K-line and I2C off the J3 row.
//   2. The wideband divider is 2.21k/13.21k, not 10k/10k. DIVIDER_GAIN was
//      2.0 and is now 5.9774 — the original constant reads the sensor low by
//      a factor of three here, and there is only one range to get wrong.
//   3. The +5 V sensor excitation is permanently on, fed from USB through a
//      polyfuse. The parent board switched it so firmware could shed 80 mA
//      and stretch a 127 ms ride-through; the supercap bank here holds
//      seconds, so the switch and its GPIO went away.
//   4. WS2812 data goes through a 74AHCT1G125 whose input floats from reset,
//      so GPIO48 is driven low before the LED driver ever touches it.
//   5. There is a power-fail signal and roughly 825 ms of supercap behind it,
//      and a microSD card that will be left corrupt if that window is not
//      spent. README section 2 states the contract; shutdown() honours it.
//      The signal now watches the 5 V USB rail, not a 12 V harness.
//   6. K-line (ISO 9141 / KWP2000) is wired to GPIO1/2 through a discrete
//      low-side FET and a divider. TX is inverted in hardware, so the UART
//      needs UART_SIGNAL_TXD_INV. Nothing in this sketch drives it yet.
//   7. A second CAN bus hangs off an MCP2518FD on SPI, because the S3 has
//      exactly one TWAI. Not driven here yet either.
//
// GATT is unchanged, so the existing WidebandBleManager in the logger app
// pairs with this board without modification.
// Libraries: FastLED 3.7+, NimBLE-Arduino 2.x. CAN uses the core's TWAI driver.

#include <Arduino.h>
#include <FastLED.h>
#include <NimBLEDevice.h>
#include <Wire.h>
#include <SD_MMC.h>
#include <driver/twai.h>
#include <math.h>

// --- Pin map (README section 6) ---------------------------------------------
#define LED_PIN     48            // via U6 74AHCT1G125 to the WS2812 header
#define NUM_LEDS    8
#define LED_TYPE    WS2812B
#define COLOR_ORDER GRB

#define CAN_TX_PIN  GPIO_NUM_17
#define CAN_RX_PIN  GPIO_NUM_18
#define CAN_S_PIN   16            // low = normal, high = listen-only

#define PWR_FAIL_PIN 15           // rising = the 5 V rail is below 4.20 V

// K-line, not yet driven. Listed so the pin map in this file stays the whole
// pin map -- a GPIO that is documented nowhere is a GPIO someone reuses.
#define K_TX_PIN      2           // low-side FET gate; UART TX must be inverted
#define K_RX_PIN      1           // divided 22k/10k and clamped

// Second CAN bus: an MCP2518FD on SPI, because the ESP32-S3 has exactly one
// TWAI peripheral and two buses have to be watched at once. Not driven by
// this sketch yet; listed so the pin map in this file stays the whole pin
// map. SDI/SDO on the controller are named from ITS point of view, so they
// cross over: the controller's SDI is this end's MOSI.
#define CAN2_SCK_PIN  39
#define CAN2_MOSI_PIN 40          // -> MCP2518FD SDI
#define CAN2_MISO_PIN 41          // <- MCP2518FD SDO
#define CAN2_CS_PIN   42
#define CAN2_INT_PIN  21
// These two live on the far socket row from the card itself. They are the
// only SD signals that do, and deliberately: they are DC, so crossing the
// board costs nothing, while the six bus lines stay beside the slot.
#define SD_PWR_EN_PIN 47
#define SD_CD_PIN     11
// 1-BIT SDMMC. D1/D2/D3 are not wired to the MCU at all: those three pins
// went to the second CAN controller's SPI bus, which needed five and had
// two spare. The card still pulls all three up -- a card samples DAT3 at
// power-up and falls into SPI mode if it finds it low -- they just stop
// there. 1-bit carries about 1.5 MB/s against this logger's <130 kB/s, and
// bus width does not touch the card's internal write stall, which is the
// thing the whole hold-up budget is sized around.
#define SD_CLK_PIN 14
#define SD_CMD_PIN 13
#define SD_D0_PIN  12

#define RPM_STALE_MS 2000         // blank the strip if CAN goes quiet

// 500 kbit/s, id 0x316, RPM in bytes 2-3 little-endian / 6.4. Lifted from the
// working car sketch, esp32-canbus-SN65HVD230-v2 — same decode, same bus.
#define CAN_RPM_ID 0x316

CRGB leds[NUM_LEDS];
uint16_t rpm = 0;
bool redBlinkState = false;
unsigned long lastBlinkTime = 0;
const unsigned long blinkInterval = 100;   // 100 ms = 5 Hz blink above 7100 rpm
unsigned long lastRpmMs = 0;
bool canUp = false;

unsigned long canFrames = 0;      // frames since the last status line

// --- Analog front end (README section 3) ------------------------------------
//
// The four channels are identical and there is ONE range, 0-16 V, which spans
// a 5 V and a 12 V sensor both. The range and bypass jumpers are gone: a
// per-channel range select would have needed a per-channel matched return
// attenuator for the differential ground correction, and a jumper you can
// half-set is a silent wrong reading.
//
// AIN1 carries the wideband. gen/simulate_firmware.py study 3 measures the
// gain end to end, and the mutation harness puts the R53 board's 2.0 back to
// prove the study would notice.
// 13.21 / 2.21. One divider ratio on this board, spanning 0-16 V, so a 5 V
// sensor lands at 0.836 V and a 12 V one at 2.01 V. The 0-5 V range and its
// 1.7334 went with the range-select jumpers -- see the note above the channel
// loop in gen/generate_schematic.py for why one fixed ratio is what makes the
// differential ground correction exact.
//
// This constant can be USED AS IS. The two gain-setting resistors are 0.1%
// and the series resistor's 1% barely moves it, so the divider is 0.235%
// worst case and the ADS1115's own 0.30% is the larger term. A per-channel
// calibration would still be better, but nothing here assumes you took one.
static const float DIVIDER_GAIN = 5.9774f;
static const int   ESP_ADC_PIN  = 4;       // AIN1 = GPIO4 = ADC1_CH3
static const int   VBAT_ADC_PIN = 8;       // VBAT_SNS = GPIO8, from OBD-II pin 16
// 108.2k / 8.2k, not the 11.0 this file inherited. The schematic moved to
// 13.2:1 so a 36 V input would not saturate the ADC and the constant never
// followed, so every battery reading was 20 % low. The fwsim board model
// carried the same wrong 1/11, which is why nothing caught it: the two agreed
// with each other and neither agreed with the board.
static const float VBAT_DIVIDER = 13.195f;

// I2C is on the Qwiic header and on the J1 socket row, beside the analog
// front end and both ADS1115s. IO38 would have been the obvious SDA but it
// drives the DevKitC-1 v1.1's own RGB LED.
static const int   ADS_SDA_PIN  = 10;
static const int   ADS_SCL_PIN  =  9;
static const uint8_t ADS_ADDR   = 0x48;
static const float   ADS_LSB_MV = 0.125f;  // GAIN_ONE (+-4.096 V)

// The sensor can legitimately reach the top of its range, so the clamp has to
// sit above it rather than at 5.5 V, which on this front end is inside the
// measurement band once the gain is right.
static const float SENSOR_VMAX = 5.6f;

enum HwMode : uint8_t { HW_RESISTOR = 0, HW_ADS1115 = 1 };

static const char* DEVICE_NAME = "R53-Wideband";
static const char* SERVICE_UUID      = "4fafc201-1fb5-459e-8fcc-c5c9c331914b";
static const char* VOLTS_CHAR_UUID   = "beb5483e-36e1-4688-b7f5-ea07361b26a8";
static const char* HW_MODE_CHAR_UUID = "beb5483e-36e1-4688-b7f5-ea07361b26a9";

// The strip is redrawn every LOOP_PERIOD_MS; the wideband is notified more
// slowly. 50 Hz notifications outrun the connection interval a phone actually
// negotiates, which backs up NimBLE's buffers until the link drops — and the
// sensor itself only responds in ~100 ms, so 20 Hz loses nothing.
static const uint32_t LOOP_PERIOD_MS   = 20;
static const uint32_t NOTIFY_PERIOD_MS = 50;
static const uint32_t BLE_RETRY_MS     = 5000;
static const uint32_t LOG_FLUSH_MS     = 1000;

NimBLECharacteristic* voltsCharacteristic  = nullptr;
NimBLECharacteristic* hwModeCharacteristic = nullptr;
bool clientConnected = false;
bool bleReady        = false;
uint32_t bleRetryAtMs = 0;
uint32_t lastNotifyMs = 0;
volatile bool voltsSubscribed = false;

volatile uint8_t hwMode = HW_RESISTOR;
bool adsPresent = false;
bool adsTried   = false;

// --- Power fail --------------------------------------------------------------
//
// Set from the ISR, read from loop(). The ISR used to drop SENS_EN here as
// well, to double a 53 ms budget to 108 ms. There is no sensor switch any
// more and the budget is measured in seconds, so the ISR does the one thing
// it still has to: latch the flag and get out.
volatile bool powerFailed = false;
bool shuttingDown = false;

File logFile;
bool sdUp = false;
uint32_t lastLogFlushMs = 0;
unsigned long logLines = 0;

void updateLEDs();
bool bleInit();
void bleWatchdog();
void shutdown();
float readBatteryVolts();   // defined below; printStatus() reports it

void IRAM_ATTR onPowerFail() {
  powerFailed = true;
}

/**
 * One status line a second — the only routine output, and the thing that says
 * which half is unhappy without a scope. Frames counts EVERY id on the bus, so
 * "frames 0" is a wiring/transceiver problem while "frames high, rpm 0" is a
 * decode problem.
 */
void printStatus() {
  static unsigned long last = 0;
  unsigned long now = millis();
  if (now - last < 1000) return;
  last = now;
  const char* ble;
  if (!bleReady)              ble = "DOWN";
  else if (clientConnected)   ble = "connected";
  else if (NimBLEDevice::getAdvertising()->isAdvertising()) ble = "advertising";
  else                        ble = "IDLE";
  // Battery is on the status line as well as in the log. It is the one
  // reading with no other way to see it live, and its divisor was wrong for
  // the whole life of the parent board without anything noticing -- putting
  // it here is what lets gen/simulate_firmware.py hold it to a number.
  Serial.printf("rpm %4u  can %s frames/s %-4lu  ble %-11s  sd %s lines %lu  batt %.2f\n",
                rpm, canUp ? "up" : "DOWN", canFrames, ble,
                sdUp ? "up" : "DOWN", logLines, readBatteryVolts());
  canFrames = 0;
}

// --- CAN --------------------------------------------------------------------
void canInit() {
  // CAN_S low = normal mode. R40 already pulls it there so the transceiver is
  // sane while the MCU is in reset; drive it anyway so the state is the
  // firmware's decision and not a resistor's.
  pinMode(CAN_S_PIN, OUTPUT);
  digitalWrite(CAN_S_PIN, LOW);

  twai_general_config_t g =
      TWAI_GENERAL_CONFIG_DEFAULT(CAN_TX_PIN, CAN_RX_PIN, TWAI_MODE_NORMAL);
  g.rx_queue_len = 32;   // FastLED.show() blocks ~0.5 ms; don't drop frames in it
  twai_timing_config_t t = TWAI_TIMING_CONFIG_500KBITS();
  twai_filter_config_t f = TWAI_FILTER_CONFIG_ACCEPT_ALL();

  if (twai_driver_install(&g, &t, &f) != ESP_OK || twai_start() != ESP_OK) {
    Serial.println("TWAI: init failed");
    return;
  }
  canUp = true;
  Serial.println("TWAI initialized");
}

void canPoll() {
  if (!canUp) return;
  twai_message_t msg;
  while (twai_receive(&msg, 0) == ESP_OK) {
    canFrames++;
    if (msg.extd || msg.rtr || msg.identifier != CAN_RPM_ID) continue;
    if (msg.data_length_code < 4) continue;
    uint16_t raw = msg.data[2] | ((uint16_t)msg.data[3] << 8);
    rpm = (uint16_t)constrain(raw / 6.4f, 0.0f, 9000.0f);
    lastRpmMs = millis();
  }
  twai_status_info_t st;
  if (twai_get_status_info(&st) == ESP_OK && st.state == TWAI_STATE_BUS_OFF) {
    twai_initiate_recovery();
  }
}

// --- Analog ------------------------------------------------------------------
float readEspAdcSensorVolts() {
  float v = (analogReadMilliVolts(ESP_ADC_PIN) / 1000.0f) * DIVIDER_GAIN;
  return constrain(v, 0.0f, SENSOR_VMAX);
}

float readBatteryVolts() {
  return (analogReadMilliVolts(VBAT_ADC_PIN) / 1000.0f) * VBAT_DIVIDER;
}

bool adsWriteReg(uint8_t reg, uint16_t value) {
  Wire.beginTransmission(ADS_ADDR);
  Wire.write(reg);
  Wire.write((uint8_t)(value >> 8));
  Wire.write((uint8_t)(value & 0xFF));
  return Wire.endTransmission() == 0;
}

bool adsReadReg(uint8_t reg, uint16_t* out) {
  Wire.beginTransmission(ADS_ADDR);
  Wire.write(reg);
  if (Wire.endTransmission(false) != 0) return false;
  if (Wire.requestFrom(ADS_ADDR, (uint8_t)2) != 2) return false;
  uint16_t hi = Wire.read();
  uint16_t lo = Wire.read();
  *out = (hi << 8) | lo;
  return true;
}

/** Lazy I2C — only touch the bus when the phone asks for ADS1115 mode. */
void ensureAdsProbed() {
  if (adsTried) return;
  adsTried = true;
  Wire.begin(ADS_SDA_PIN, ADS_SCL_PIN);
  Wire.setClock(400000);
  // 0x1283, not 0x4283: MUX 001 is AIN0 referenced to AIN3, not to GND.
  //
  // AIN3 on both parts carries AGND_SENSE -- the sensor loom's own ground,
  // brought back as a Kelvin wire through an attenuator identical to the
  // signal channels'. The board is grounded twice (through the loom, and
  // through USB by way of a charger somewhere else in the car), and a few
  // hundred millivolts of chassis drop between those points is 6 % of a
  // 0-5 V channel. Reading differentially subtracts it exactly, because both
  // legs are divided by the same 15/26.
  //
  // Read single-ended (0x4283) and the offset is measured as signal. The
  // 0.1 % divider resistors on this board are wasted money if this register
  // is wrong.
  if (!adsWriteReg(0x01, 0x1283)) return;  // AIN0-AIN3, +-4.096 V, 128 SPS
  delay(10);
  uint16_t check = 0;
  adsPresent = adsReadReg(0x01, &check);
}

float readAdsSensorVolts() {
  ensureAdsProbed();
  if (!adsPresent) return NAN;
  uint16_t raw = 0;
  if (!adsReadReg(0x00, &raw)) return NAN;
  float v = (((int16_t)raw) * ADS_LSB_MV / 1000.0f) * DIVIDER_GAIN;
  return constrain(v, 0.0f, SENSOR_VMAX);
}

float readSensorVolts() {
  if (hwMode == HW_ADS1115) {
    float v = readAdsSensorVolts();
    if (isfinite(v)) return v;
  }
  return readEspAdcSensorVolts();
}

// --- microSD -----------------------------------------------------------------
void sdInit() {
  pinMode(SD_CD_PIN, INPUT);
  pinMode(SD_PWR_EN_PIN, OUTPUT);
  digitalWrite(SD_PWR_EN_PIN, HIGH);       // the card supply is switched
  delay(10);                               // let the rail come up before clocking

  SD_MMC.setPins(SD_CLK_PIN, SD_CMD_PIN, SD_D0_PIN);
  if (!SD_MMC.begin("/sdcard", true)) {    // 1-bit; see the pin block above
    Serial.println("SD: mount failed");
    return;
  }
  logFile = SD_MMC.open("/log.csv", FILE_APPEND);
  if (!logFile) {
    Serial.println("SD: could not open /log.csv");
    return;
  }
  logFile.println("t_ms,rpm,wideband_v,vbat_v");
  sdUp = true;
  Serial.println("SD: logging to /log.csv");
}

void logSample(float volts, float vbat) {
  if (!sdUp || shuttingDown) return;
  logFile.printf("%lu,%u,%.3f,%.2f\n", millis(), rpm, volts, vbat);
  logLines++;
  uint32_t now = millis();
  if (now - lastLogFlushMs >= LOG_FLUSH_MS) {
    lastLogFlushMs = now;
    logFile.flush();     // bound what an unexpected reset can lose to one second
  }
}

/**
 * The firmware half of README section 2. The hardware guarantees roughly
 * 108 ms between PWR_FAIL and the converters dropping out; this is what spends
 * it. Order matters: the sensor rail is already off (the ISR did it), the strip
 * goes dark so it is not drawing from the bank, then the file is closed, and
 * only then is the card supply removed — with SD_MMC.end() first, because
 * dropping SD_PWR_EN while the bus pins are still driven back-feeds the card
 * through its ESD structures (README section 5).
 */
void shutdown() {
  if (shuttingDown) return;
  shuttingDown = true;

  // The LEDs are the one load worth shedding: eight WS2812s at full white is
  // 480 mA against the ~120 mA the rest of the board draws, and the hold-up
  // budget is inversely proportional to it. Clearing them first turns a
  // 769 ms worst case back into 2500 ms.
  FastLED.clear(true);

  if (sdUp) {
    // close() flushes. Calling flush() first as well costs a second full
    // card-side write, and on this budget that is not a tidiness question:
    // gen/simulate_firmware.py study 11 measures the double flush cutting the
    // tolerable card latency from ~100 ms to ~50 ms.
    logFile.close();
    SD_MMC.end();
    sdUp = false;
  }
  digitalWrite(SD_PWR_EN_PIN, LOW);

  Serial.printf("PWR_FAIL at %lu ms: %lu lines flushed and closed\n", millis(), logLines);
}

// --- BLE ---------------------------------------------------------------------
class ServerCallbacks : public NimBLEServerCallbacks {
  void onConnect(NimBLEServer* server, NimBLEConnInfo& info) override {
    clientConnected = true;
    // Ask for a link the phone can hold: 15–30 ms interval, no slave latency,
    // 4 s supervision timeout. The default timeout can run to 20 s, and while
    // it counts down after a dropout the server is neither connected nor
    // advertising — twenty seconds of "no wideband bridge found" on the phone.
    server->updateConnParams(info.getConnHandle(), 12, 24, 0, 400);
  }
  void onDisconnect(NimBLEServer*, NimBLEConnInfo&, int) override {
    clientConnected = false;
    // Cleared here, not left to onSubscribe(0): a link that drops out of range
    // or times out never delivers an unsubscribe, and a stale true would have
    // us notifying into nothing until the next client happened to connect.
    voltsSubscribed = false;
    // Deliberately NOT calling startAdvertising() here: this runs on the NimBLE
    // host task while the connection is still being torn down.
    // advertiseOnDisconnect() restarts it at a safe point and bleWatchdog()
    // catches it if that ever doesn't take.
  }
};

class VoltsCallbacks : public NimBLECharacteristicCallbacks {
  void onSubscribe(NimBLECharacteristic*, NimBLEConnInfo&, uint16_t subValue) override {
    voltsSubscribed = (subValue != 0);
  }
};

class HwModeCallbacks : public NimBLECharacteristicCallbacks {
  void onWrite(NimBLECharacteristic* c, NimBLEConnInfo&) override {
    NimBLEAttValue v = c->getValue();
    if (v.length() < 1) return;
    uint8_t mode = v[0];
    if (mode == HW_RESISTOR || mode == HW_ADS1115) {
      hwMode = mode;
      c->setValue(&mode, 1);
    }
  }
};
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
void loop() {
  // Checked before anything else: from here on the only job is to finish the
  // write and stop. Nothing below this line may start new work.
  if (powerFailed) {
    shutdown();
    delay(LOOP_PERIOD_MS);
    return;
  }

  canPoll();
  bleWatchdog();

  float volts = readSensorVolts();

  // getSubscribedCount() — not just clientConnected. A phone is connected for
  // a beat before it discovers services and writes the CCCD, and notifying into
  // that gap is pure churn on the link at the least forgiving moment.
  if (bleReady && voltsCharacteristic != nullptr && voltsSubscribed &&
      (uint32_t)(millis() - lastNotifyMs) >= NOTIFY_PERIOD_MS) {
    lastNotifyMs = millis();
    if (isfinite(volts)) {
      voltsCharacteristic->setValue((uint8_t*)&volts, sizeof(volts));
      voltsCharacteristic->notify();
    }
  }

  logSample(volts, readBatteryVolts());

  updateLEDs();
  FastLED.show();
  printStatus();
  delay(LOOP_PERIOD_MS);
}

void updateLEDs() {
#ifdef RPM_STALE_MS
  if (rpm != 0 && (unsigned long)(millis() - lastRpmMs) > RPM_STALE_MS) rpm = 0;
#endif

  CRGB color;

  // Number of LED pairs to light, 0 to 4.
  int numPairs = constrain(map(rpm, 0, 7100, 0, 4), 0, 4);

  if (rpm < 3000) {
    color = CRGB(0, 0, 0);                // off below 3000 rpm
  } else if (rpm < 6000) {
    color = CRGB(0, 255, 0);              // solid green 3000-6000
  } else if (rpm <= 7100) {
    uint8_t t = map(rpm, 6000, 7100, 0, 255);   // green to red 6000-7100
    color = CRGB(t, 255 - t, 0);
  } else {
    if (millis() - lastBlinkTime >= blinkInterval) {
      redBlinkState = !redBlinkState;
      lastBlinkTime = millis();
    }
    color = redBlinkState ? CRGB(255, 0, 0) : CRGB(0, 0, 0);
    numPairs = 4;                         // all eight blink above 7100
  }

  // Light from the ends inward.
  for (int i = 0; i < NUM_LEDS; i++) {
    leds[i] = CRGB(0, 0, 0);
    if (numPairs >= 1 && (i == 0 || i == 7)) leds[i] = color;
    if (numPairs >= 2 && (i == 1 || i == 6)) leds[i] = color;
    if (numPairs >= 3 && (i == 2 || i == 5)) leds[i] = color;
    if (numPairs >= 4 && (i == 3 || i == 4)) leds[i] = color;
  }
}

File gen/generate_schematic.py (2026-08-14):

#!/usr/bin/env python3
"""
Generate the KiCad schematic for the ESP32-S3 CAN + microSD automotive logger.

The netlist below is the single source of truth: every component lists its
pins and the net each pin lands on.  Symbol geometry and -- critically --
pin numbering come from the official KiCad symbol libraries, so pin numbers
are never hand-typed here.

Output: <project>/*.kicad_sch (hierarchical, one sheet per functional block),
        <project>/bom.csv, <project>/netlist.txt

Usage:  python3 gen/generate_schematic.py [--symbol-dir /usr/share/kicad/symbols]
"""

import argparse
import csv
import math
import os
import re
import uuid

# --------------------------------------------------------------------------
# S-expression reading (only what we need: pin geometry + raw symbol text)
# --------------------------------------------------------------------------

TOKEN = re.compile(r'"(?:[^"\\]|\\.)*"|\(|\)|[^\s()]+')


def parse_sexp(text):
    toks = TOKEN.findall(text)
    pos = 0

    def read():
        nonlocal pos
        tok = toks[pos]
        pos += 1
        if tok == "(":
            out = []
            while toks[pos] != ")":
                out.append(read())
            pos += 1
            return out
        return tok

    out = []
    while pos < len(toks):
        out.append(read())
    return out


def unquote(s):
    if s.startswith('"'):
        return s[1:-1].replace('\\"', '"').replace("\\\\", "\\")
    return s


def children(node, tag):
    return [c for c in node if isinstance(c, list) and c and c[0] == tag]


def _property_spans(text):
    """[(start, end)] of each top-level (property ...) block in a symbol."""
    spans = []
    depth, i, in_str = 0, 0, False
    start = None
    while i < len(text):
        ch = text[i]
        if in_str:
            if ch == "\\":
                i += 2
                continue
            if ch == '"':
                in_str = False
        elif ch == '"':
            in_str = True
        elif ch == "(":
            if depth == 1 and start is None and text.startswith("(property ", i):
                start = i
            depth += 1
        elif ch == ")":
            depth -= 1
            if depth == 1 and start is not None:
                spans.append((start, i + 1))
                start = None
        i += 1
    return spans


# The schematic format this generator emits, and the symbol-library format its
# embedded definitions were validated against.  KiCad opens older schematics and
# upgrades them on load, so emitting the 7.0 format is safe on 7, 8 and 9 alike.
SCH_FORMAT_VERSION = "20230121"          # KiCad 7.0
VALIDATED_SYMBOL_VERSION = "20241209"    # KiCad 9.0 symbol libraries


def find_symbol_dir():
    """Locate the stock KiCad symbol libraries on Windows, macOS or Linux."""
    import glob as _glob

    for var in ("KICAD9_SYMBOL_DIR", "KICAD8_SYMBOL_DIR", "KICAD7_SYMBOL_DIR",
                "KICAD6_SYMBOL_DIR"):
        path = os.environ.get(var)
        if path and os.path.isdir(path):
            return path

    patterns = [
        r"C:\Program Files\KiCad\*\share\kicad\symbols",
        r"C:\Program Files (x86)\KiCad\*\share\kicad\symbols",
        "/Applications/KiCad/KiCad.app/Contents/SharedSupport/symbols",
        "/usr/share/kicad/symbols",
        "/usr/local/share/kicad/symbols",
        os.path.expanduser("~/.local/share/kicad/*/symbols"),
    ]
    found = []
    for pat in patterns:
        found.extend(p for p in _glob.glob(pat) if os.path.isdir(p))
    if found:
        # Highest KiCad version wins when several are installed.
        return sorted(found)[-1]
    return None


# A two-pin symbol's pin numbers say nothing its graphic does not already say
# -- polarity is the cathode bar and the plus sign, not the digit -- and they
# reliably collide with whatever the pin connects to. "+5VS" printed through a
# solder jumper's "2" rendered the rail as "+2VS", which is worse than useless
# on the one drawing somebody reads with a probe in their hand.
#
# KiCad's own Device:R and Device:C already hide theirs. This extends that to
# every two-pin symbol, which is where the collisions were.
_PIN_NUMBERS_RE = re.compile(r"\(pin_numbers\b[^()]*(?:\([^()]*\)[^()]*)*\)")


def hide_pin_numbers(text):
    """Force (pin_numbers (hide yes)) into a library symbol definition."""
    hidden = "(pin_numbers (hide yes))"
    if _PIN_NUMBERS_RE.search(text):
        return _PIN_NUMBERS_RE.sub(hidden, text, count=1)
    nl = text.find("\n")
    if nl < 0:
        return text
    return text[:nl + 1] + "\t\t" + hidden + "\n" + text[nl + 1:]


class SymbolLibs:
    """Reads the installed KiCad symbol libraries."""

    def __init__(self, symbol_dir):
        self.symbol_dir = symbol_dir
        self._parsed = {}
        self._raw = {}
        self.lib_version = None

    def _load(self, lib):
        if lib in self._parsed:
            return
        path = os.path.join(self.symbol_dir, lib + ".kicad_sym")
        if not os.path.exists(path):
            raise SystemExit("symbol library not found: " + path)
        text = open(path, encoding="utf-8").read().replace("\r\n", "\n")
        root = parse_sexp(text)[0]
        ver = children(root, "version")
        if ver and self.lib_version is None:
            self.lib_version = unquote(ver[0][1])
        self._parsed[lib] = {unquote(s[1]): s for s in children(root, "symbol")}

        # Byte-exact source text for each top-level symbol, so the definitions
        # we embed in the schematic are identical to the library's.
        # One indent level is two spaces (7.0 libraries) or one tab (9.0).
        raw = {}
        for m in re.finditer(r'^(?:  |\t)\(symbol "([^"]+)"', text, re.M):
            start = m.start()
            depth, i, in_str = 0, start, False
            while i < len(text):
                ch = text[i]
                if in_str:
                    if ch == "\\":
                        i += 2
                        continue
                    if ch == '"':
                        in_str = False
                elif ch == '"':
                    in_str = True
                elif ch == "(":
                    depth += 1
                elif ch == ")":
                    depth -= 1
                    if depth == 0:
                        i += 1
                        break
                i += 1
            raw[m.group(1)] = text[start:i]
        self._raw[lib] = raw

    def symbol(self, lib_id):
        lib, name = lib_id.split(":", 1)
        self._load(lib)
        if name not in self._parsed[lib]:
            raise SystemExit("symbol not found: " + lib_id)
        return self._parsed[lib][name]

    def has(self, lib_id):
        lib, name = lib_id.split(":", 1)
        if not os.path.exists(os.path.join(self.symbol_dir, lib + ".kicad_sym")):
            return False
        self._load(lib)
        return name in self._parsed[lib]
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

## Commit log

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2026-08-13 Re-scope the fork as a carrier board: no power section, differential analog, K-line
    The shield idea does not survive measurement. Component courtyard on the
    parent is 3052 mm2 over an 84 x 100 board -- 36% packing, not the 50% I had
    been estimating -- and a DevKitC-1 is 63 x 25.5 = 1607 mm2. The parts alone
    were 1.4x the whole dev board. So this is a carrier the dev board plugs into,
    not a shield that fits on top of one.
    Power section deleted entirely. It was 1746 mm2, 57% of the board, for two
    rails the DevKitC-1 already makes from its USB-C. Gone: both LM5164 bucks and
    everything around them, the LM74700 ideal diode, the reverse-battery FET, the
    three electrolytic cans, the 12 V input, an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
    [analog.kicad_sch, bom.csv, can.kicad_sch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]
2026-08-13 Second CAN bus, single analog range, and three placement bugs the render caught
    TWO CAN BUSES AT ONCE NEEDS A SECOND CONTROLLER. The ESP32-S3 has exactly
    one TWAI peripheral. Two transceivers on it would give a bus you can pick at
    runtime through the GPIO matrix, never two live at once, and the point of a
    second bus is watching the powertrain and the body bus together. So the
    second channel is an MCP2518FD on SPI (SOIC-14, KiCad ships the pin-compatible
    MCP2517FD symbol) with its own 40 MHz crystal, its own TJA1051 -- same part
    as CAN 1, so two positions on one BOM line -- choke, split termination and
    clamps.
    That cost five pins against two spare. The three came from dropping the
    microSD to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
    [analog.kicad_sch, bom.csv, can.kicad_sch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]
2026-08-13 Route, audit and document the carrier; verify every part number against the catalogue
    Ordering is the point of this pass, so the part numbers came first. Every
    LCSC number on the board was opened and read -- manufacturer part, package,
    and the parameter that decides whether it is the right part. That found:
    C2148396 for the MCP2518FD is an 18.7k resistor, out of stock -> C626759
    C255909 for a 40 MHz crystal is a 16 MHz crystal -> C5186937
    C157966 for a JST PH 10-way is a JST XH 9-way, 2.5 mm pitch -> C158038
    Three of the five numbers introduced last sitting were wrong, and all three
    were plausible enough that the BOM exported clean. docs/PARTS.md records the
    lot,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
    [analog.kicad_sch, bom.csv, can.kicad_sch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]
2026-08-13 Price the BOM and identify a 31% cut that costs nothing functional
    Read every LCSC price at the tier a five-board build lands in. Parts come to
    $18.29 a board -- $13.16 SMD, $5.13 through-hole -- and eight lines are 85% of
    the SMD side.
    The surprise is the precision resistors. FIFTEEN OF THEM COST $2.68, more than
    the CAN controller, because Yageo's 0.1% thin film is $0.30 and $0.19 a piece
    against $0.0027 for a stocked 1% part. They are not buying what they look like
    they are buying: the ADS1115's own gain error is +/-0.30% maximum against the
    divider's 0.14%, so the converter already dominates. Absolute accuracy has to
    be calibrated regardless -- the schematic has said so since the parent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
2026-08-13 Implement the cost reductions: 1% dividers and a 0.33 F bank -- $18.29 to $13.87
    Two of the three changes from docs/COST.md. The third was dropped once I
    checked it properly, which is the more interesting half of this commit.
    PRECISION RESISTORS TO 1%, saving $2.62 measured. Fifteen 0.1% parts cost
    $2.68 -- more than the CAN controller -- to tighten a divider whose error the
    ADS1115's own +/-0.30% gain spec already dominates. Absolute scale has to be
    calibrated whatever the tolerance, and the thing calibration cannot fix, the
    match between the signal chain and the return attenuator, is fine at 1%: a
    300 mV chassis offset leaves 6 mV instead of 0.6 mV, both negligible against
    the 300 mV bein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
    [analog.kicad_sch, bom.csv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]
2026-08-13 Precision where it changes the answer: 0.1% on the two gain-setting resistors
    Walking back half of the previous commit, because its argument depended on a
    calibration step that is not going to happen. All-1% dividers are only
    equivalent to 0.1% if somebody measures each channel against a known voltage
    and stores a constant; without that they are 1.67% worst case against 0.167%.
    But going straight back to fifteen 0.1% parts would have been the wrong
    correction. Gain is Rlow/(Rser+Rup+Rlow), so each resistor moves it in
    proportion to its share of the total:
    1k series 0.076 -> 0.076% of gain per 1% of tolerance
    10k upper 0.758 -> 0.758%
    2.21k lower 0.833 -> 0.833%
    The seri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
    [analog.kicad_sch, bom.csv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]
2026-08-13 Make the schematic readable: wire the loose parts, stop text printing through symbols
    Three things the drawing was doing badly, all now measured by a new
    gen/audit_schematic.py rather than judged by eye.
    LOOSE PARTS ARE WIRED NOW. A decoupling capacitor is a two-pin part with a
    rail on each pin, and the column packer had no reason to put one next to
    another -- so each came out as its own island with a net label at both ends,
    twenty-odd of them down the edge of the power sheet. Electrically perfect,
    visually a parts bin. build_ladders() groups the leftovers by which pair of
    nets they sit across and draws each group as a proper ladder: one wire along
    the top pins, one along the bottom, a junc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
    [analog.kicad_sch, bom.csv, can.kicad_sch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]
2026-08-13 microSD: turn the socket round so the card can actually go in
    You called it: the slot was backwards. The tell is the solder joints --
    a microSD goes in contacts-first, so the spring contacts and the tails
    that solder to pads 1-8 are at the BACK of the slot and the mouth is at
    the far end. Those pads sit at footprint y +5.35, so at 0 degrees the
    mouth faced -y: into the middle of the board. The card could only have
    been inserted from inside the laminate.
    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
    [esp32s3-can-sd-logger-B_Cu.gbr, esp32s3-can-sd-logger-B_Mask.gbr, esp32s3-can-sd-logger-B_Paste.gbr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]
2026-08-13 Schematic readability: fix the measurement, then fix the schematic
    Three bugs in audit_schematic.py meant it was reporting clean on things
    that were plainly wrong on the page:
    * lib_info() keyed its table on the NAME_1_1 unit sub-symbols while
    every placed symbol refers to the parent lib_id, so every lookup
    missed, every symbol came back with no pins, and the pin-number
    collisions the function exists to find were never once tested.
    * CHAR_W was an eyeballed 0.70. Plotting the sheets and measuring all
    1141 strings KiCad actually drew gives 0.851. Every string was
    modelled a sixth too narrow -- three characters' worth on a long net
    name.
    * A property's angle is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
    [analog.kicad_sch, can.kicad_sch, mcu.kicad_sch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]
2026-08-13 Draw the circuits that were only ever held together by net names
    You wanted the hanging parts fixed. 48 of 160 symbols reached nothing
    by wire -- a name at each end and nothing to follow. Now 7.
    First the measurement, again. audit_schematic counted 59, and 11 of
    those were decoupling capacitors with a rail symbol above and a ground
    below, which is exactly how a person draws a decoupling capacitor. A
    pin ending on a power symbol is DRAWN, not named; only a bare net label
    makes the reader do the join in their head. Counting the two the same
    made the number useless, so power symbols now count as a connection.
    Seven new hand-drawn blocks, and the second CAN channel is no longer a
    special case: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
    [analog.kicad_sch, can.kicad_sch, mcu.kicad_sch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]
2026-08-14 Space the parts for hand assembly: median gap 0.40 -> 1.20 mm
    This board was laid out for an assembly house at a 0.4 mm courtyard gap.
    It is being built by hand now, so the shelf packer runs at 1.2 mm and
    several zones grew to absorb it.
    median nearest neighbour 0.40 -> 1.20 mm
    parts with a neighbour
    closer than 1.0 mm 85 -> 12 of 100
    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
    [esp32s3-can-sd-logger-B_Cu.gbr, esp32s3-can-sd-logger-B_Mask.gbr, esp32s3-can-sd-logger-B_Paste.gbr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]
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2026-08-14 One combined parts order across both boards
    Building the logger and the gate controller at once, five of each. Both
    are mostly the same jellybeans, and ordered separately every shared line
    pays LCSC's minimum order quantity TWICE -- 200 pieces of an 0805 to fit
    thirty of them.
    gen/export_combined_order.py reads the finished assembly BOM from each
    project, adds the per-part quantities, and rounds the SUM to the minimum
    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
    [order-combined.csv, order-elsewhere.csv]
2026-08-14 Check live stock, and emit a cart that can actually be bought
    You said a bunch of the parts were out of stock. Every number in these
    projects had been checked against the catalogue when it was chosen, which
    proved the part EXISTS -- and I presented that as though it meant you
    could buy it. Those are not the same thing and the difference is the
    whole order.
    gen/check_stock.py pulls live stock and price for every line from
    jlcsearch, flags anything that cannot cover the quantity, hunts for a
    replacement of the same value in the same package that can, and writes
    fab/order-verified-paste.txt: the same order with the unbuyable lines
    replaced.
    61 of 64 in stock for the quantity needed
    1 sho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
    [check_stock.py]
2026-08-14 Stop guessing minimum order quantities, and check the whole cart
    Two more things wrong with the order, both mine.
    MINIMUMS. export_order rounded every chip package up to 100 and every
    SOT-23 to 50, extrapolated from six sampled parts and described in the
    comment as though it were the rule. Several were wrong. A wrong guess
    hurts both ways: too high buys a hundred of something sold in twenties,
    too low or off-multiple gets the line rejected. Quantities are now what
    the boards NEED and LCSC raises each line to its own minimum at
    checkout, which is where the real number lives. --moq restores the old
    behaviour for anyone who wants it.
    THE THROUGH-HOLE LINES WERE NEVER CHECKED. check_stock read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
    [analog.kicad_sch, bom.csv, can.kicad_sch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]
2026-08-14 check_stock: also emit the cart as a CSV for LCSC's BOM upload
    Same 70 lines as the paste file, with a header row, the value each part
    is, and a note on the three that replaced something short or unlisted --
    so the file still explains itself when it is read back later.
    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
    [order-verified.csv]
2026-08-14 Nine wrong part numbers, six of them the wrong package
    The generic-passive table carried a comment saying it had been verified
    against the live catalogue. It had not been. Nine entries were wrong:
    2.2nF 50V 0805 C1547 12pF, and 0402 -> C107146
    121k 0805 C25089 20R, and 0402 -> C17438
    31.6k 0805 C25100 27R, and 0402 -> C2930156
    4.7k 1206 C17909 120R -> C17936
    SMAJ5.0A SMA C908214 right part, SOD-123 -> C113952
    SMAJ36A SMA C908224 right part, SOD-123 -> C113967
    green LED 0805 C965798 0603 -> C2297
    yellow LED 0805 C965800 0603 -> C84261
    600R@100MHz bead C216149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
    [bom.csv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]
2026-08-14 check_stock: write the paste file as .csv as well as .txt
    Two bare columns, part number and quantity, with a header row. Not the
    same file as order-verified.csv, which carries a description and a note
    for a human reading it back in six months -- this one is only what LCSC
    wants when it is not being asked to map columns.
    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
    [order-verified-paste.csv]
2026-08-14 Real minimum order quantities, and two dead part numbers
    Correction first: C28233 is NOT a 16V capacitor. The previous commit said
    it was and that was wrong. It is 100V 100nF X7R 0805 and the substitution
    that put it there was correct. The index holds two records for it, one
    keyed by part number and one by MPN, and the by-number record comes back
    with an empty description -- so the Samsung code CL21B104KCFNNNE was
    decoded by hand and read backwards. The cart export settles it: A is 25V
    and B is 50V across four other Samsung lines on this board.
    That mistake caused a real one. Believing it, the last commit stopped
    check_stock substituting for any part absent from the index, and that put
    C290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
    [bom.csv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]
2026-08-14 A 32.768 kHz crystal was in the cart as the converter's bulk input cap
    Found on the last check before the order went in. The gate board's
    generic table had C387601 for 10uF100V in 1206. C387601 is an
    ECS-.327-7-34B-TR, a 32.768 kHz crystal, and it was in the cart against
    C2 -- the LM5164's bulk input capacitor on the 24 V rail.
    verify_cart passed it twice, for two independent reasons, both bugs here
    rather than bad luck:
    Package matched. SMD3215-2P contains "3215", which was in the accept
    list for 1206. It should never have been: 1206 is 3216 metric and 3215
    is a crystal package. One digit.
    The value check silently did nothing. It read the LEADING token of the
    description; that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
    [esp32s3-can-sd-logger-B_Cu.gbr, esp32s3-can-sd-logger-B_Mask.gbr, esp32s3-can-sd-logger-B_Paste.gbr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]
2026-08-14 docs/TODO.md: EGT through an MCP9600, scoped
    Wanted work, as distinct from the README's "Known open", which is
    defects and unverified assumptions in what already exists.
    Needs no board change, checked against the finished PCB rather than the
    schematic: J5 is at x=93mm on a 98mm board with the DevKitC-1 at x=40
    and x=63, so it is reachable with the module in and the loom plugged.
    Pull-ups are already fitted, 3.3V is on pin 2, and 0x60-0x67 does not
    collide with the ADS1115s at 0x48/0x49.
    Records the two things that decide the design, because both are easy to
    get wrong later:
    I2C does not leave the board. The sensors are in the engine bay and the
    logger is not, and a metre of single-ended S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
2026-08-14 lcsc-moq: C35689855, and the cart verifies clean
    79 parts in the ledger. The TDK 10uF 100V is MOQ 1, multiple 1.
    The cart LCSC returned also carries a full description for it this time
    -- "10uF X6S +/-10% 100V 1206" -- so the one line that was resting on an
    MPN decode is now confirmed from the catalogue.
    Final state: 69 lines, no missing, no extra, no quantity mismatches, no
    MOQ violations, every line matching the value, package, tolerance and
    voltage the schematic asked for, and every line covering 5 logger plus
    5 gate boards.
    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
    [lcsc-moq.csv]
2026-08-14 export_combined_order: per-project board counts and spares
    python gen/export_combined_order.py --boards 10 --other-boards 5 --spares 2
    --boards and --other-boards because the two projects are not built in
    the same numbers; --boards alone still applies to both.
    --spares adds n pieces to every line BEFORE rounding, which is what
    makes them nearly free. On a 100-piece minimum two extra cost nothing;
    they only move the lines whose minimum is 1 or 5 -- the LM5164, the
    MCP2518FD, the SD socket, the relays, the terminals. Those are the lines
    where losing one part stops a build and there is no bag of spares in the
    drawer. At 10 + 5 with two spares, 33 of 69 lines do not move at all.
    Two bugs fo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
    [order-combined.csv, order-verified-paste.csv, order-verified.csv]
2026-08-14 verify_cart: check each project's BOM, not just the survivors
    The combined order holds only the numbers consolidation KEPT. Where the
    two projects named different parts for one value, the loser was dropped
    before it reached order-combined.csv and was never checked by anything.
    Three wrong numbers lived in that blind spot, all in the gate board:
    C45783 22uF "1206" is a CL21A226 -- an 0805, and +/-20%
    C17407 100k not in the catalogue at all
    C79666 MF-MSMF050-2 is an IR2153S half-bridge gate driver, SOIC-8
    Consolidation replaced all three with the logger's numbers, so every cart
    verified clean while the gate's own fab/bom.csv -- the file you hand to
    an assembler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
    [verify_cart.py]
2026-08-14 ROW_PITCH settled at 22.86 mm, from Espressif's DXF
    This was the last thing blocking a board order, and it was the one
    number that decides whether the carrier is a carrier or a coaster.
    Read out of the actual DXF, not a rendering of it. The pad columns come
    out of the vertex list as three x values each -- pad left edge, centre,
    right edge:
    left row 0.640 1.270 1.910
    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
    [DXF_ESP32S3DevKitC1_V1_20210312CB.dxf]
2026-08-14 docs/COST.md: JLCPCB assembly quote, 10 loggers, and a correction
    $239.67 all in, 14 Aug 2026, Economic PCBA top-side only.
    The correction first: the quote is for 48 items, which is every part
    type on this board, C37593 included. This project has twice said the
    ADS1115 was absent from JLCPCB's assembly library and that 20 TSSOP-10s
    would stay hand work whatever the quote said. That was wrong. The claim
    came from the tscircuit parts index, which reports that part missing on
    some queries and present on others, and which was already wrong about it
    once -- it sat in a real LCSC cart while the index denied it. That index
    is evidence of stock and price; the quote form is the authority on what
    can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
2026-08-14 export_combined_order --assembled: the LCSC order when JLC builds it
    Economic PCBA sources and fits every SMD part itself, so ordering those
    from LCSC as well is buying them twice -- $222.92 of overlap on this
    order, against a $236.15 cart. What is actually still needed is only
    what an SMT line will not fit, which here is the six through-hole lines:
    relays, terminal blocks, the optocoupler and the JST headers.
    python gen/export_combined_order.py --boards 10 --other-boards 5 --assembled
    Writes fab/order-tht-paste.csv and .txt. 6 lines, 75 pieces, $9.64.
    No spares by default, unlike the hand-build path. With the boards
    arriving assembled there is no attrition to cover -- only repair, and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
    [order-tht-paste.csv]
2026-08-14 Record where the order got to, and why it stopped
    Paused on tariffs, not on anything technical. US customs adds 35% of
    merchandise value: the combined JLCPCB order was $315.12 of goods and
    $475.71 at checkout once $50.29 shipping and $110.30 duty were added.
    COST.md now carries both assembly quotes, the duty, and the route
    comparison. The useful finding is that duty does NOT decide between
    hand-building and assembly -- LCSC components are dutiable on the same
    basis, so hand-building moves merchandise from one Chinese invoice to
    another rather than avoiding the charge. It widens the assembly premium
    from $68.61 to $92.63, 6.0 cents a placement against 4.5. Same answer,
    bigger absolute number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
2026-08-14 export_macrofab.py: BOM in the format MacroFab can actually match
    MacroFab auto-matches on the MANUFACTURER part number, not a
    distributor's code. fab/bom.csv is written for JLCPCB and carries LCSC
    codes, so uploading it would come back with every line unmatched --
    C37593 means nothing to anyone but LCSC.
    python gen/export_macrofab.py
    Writes fab/macrofab-bom-{logger,gate}.xlsx. Their importer wants a
    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
    [lcsc-moq.csv, macrofab-bom-gate.csv, macrofab-bom-gate.xlsx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]
2026-08-14 export_us_order.py: buy the parts in the US instead
    A 35% tariff plus international freight makes LCSC's unit prices much
    less decisive than they look, and US distributors have no minimum order
    quantity. LCSC sells 0805 resistors in hundreds, so a line needing
    twelve buys a hundred; Digi-Key sells twelve. 1487 pieces against 3894,
    which closes most of the gap on its own.
    python gen/export_us_order.py --logger 10 --gate 5 --gate-assembled
    Writes fab/order-us.csv for Digi-Key's BOM manager, and order-us.txt.
    Three things had to be solved, which is why this is a script:
    Digi-Key does not know LCSC codes. MPNs come from fab/lcsc-moq.csv.
    Half the BOM is Chinese-brand -- UNI-ROYAL and FOJA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
    [order-logger-hand-paste.csv, order-us.csv]
2026-08-14 COST.md: three routes priced side by side, and where else to look
    Corrects a real error first. This page said the US parts order came in
    $18 cheaper than LCSC. It did not -- that compared the Octopart order,
    which covered the logger's SMD only because the gate was assembled in
    that scenario, against the FULL LCSC cart including the gate's SMD.
    Different baskets. Like for like, LCSC wins every route.
    route JLCPCB LCSC total US total
    1 JLCPCB assembles both 475.71 51.55 527.26 43.40 519.11
    2 bare boards, hand-build both 98.29 337.34 435.63 390.00 488.29
    3 gate assembled, logger by hand 188.57 295.28 483.85 319.23 507.80
    Cheapes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
    [order-us.csv]
2026-08-14 export_assembly_bom.py: one MPN BOM for any assembler, not just MacroFab
    Renamed from export_macrofab.py because PCBWay wants the same thing, and
    so does Eurocircuits. The split that matters is not which vendor it is,
    it is that JLCPCB matches on LCSC codes and everyone else matches on
    manufacturer part numbers -- so fab/bom.csv is for JLCPCB and this is
    for the rest.
    Adds a Type column, SMD on every line, because PCBWay asks for parts to
    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
    [assembly-bom-gate.csv, assembly-bom-gate.xlsx, assembly-bom-logger.csv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]
2026-08-14 export_centroid.py: a centroid with an origin anybody can agree on
    fab/positions.csv is KiCad's export and suits JLCPCB, which knows the
    convention: X right, Y NEGATED, because KiCad's Y axis points down and
    the export flips the sign rather than moving the origin. Every Y in it
    is negative -- the logger runs -91.5 to -13.0 on a board occupying
    0..100.
    PCBWay's guidance says only that the file must give position and
    orientation; it says nothing about which corner is zero. An unstated
    origin with negative Y is ambiguous in the way that gets a board built
    mirrored, so this writes the same data from the bottom-left corner of
    the board outline, X right, Y up, both positive. Checkable by eye:
    not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
    [centroid-logger.csv]
2026-08-14 export_assembly_bom: write each BOM into its own project's fab/
    Both were going into the logger's fab/, so the gate's BOM sat in the
    wrong repository -- away from the gerbers and centroid it has to be
    uploaded with, and certain to go stale the first time the gate changed
    and nobody thought to regenerate from over here.
    Now each project's BOM lands beside its own fab outputs, which is what
    export_centroid.py already did. --out-dir still forces both into one
    folder when you want a single place to upload from.
    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
    [assembly-bom-gate.csv, assembly-bom-gate.xlsx, assembly-bom-logger.xlsx]
2026-08-15 docs/TODO.md: wideband AFR via a TinyWB, scoped
    A DIY-EFI TinyWB is an LSU 4.9 controller giving 0-5 V scaled 10-20 AFR
    plus a custom serial protocol. The analogue route needs NOTHING changed:
    this is the sensor the front end was designed around, and the schematic
    says so -- "AFR on a 0-5 V wideband output". 5 V lands at 0.836 V through
    the fixed divider, 6688 counts, 0.75 mV referred to input, and the
    Kelvin return subtracts the exhaust-to-chassis offset that a
    manifold-mounted sensor actually suffers from.
    Records one thing that looked like a blocker and is not: +5VS sits
    behind a 0.2 A PTC and an LSU 4.9 heater takes amps, but the heater runs
    from a fused 12 V at the SENSOR connector --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
